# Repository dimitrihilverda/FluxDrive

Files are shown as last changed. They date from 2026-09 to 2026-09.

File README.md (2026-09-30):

# FluxDrive

An Amiga floppy drive emulator built around one ESP32-S3: no Gotek, no second microcontroller. It plugs into the
A500's internal floppy connector, holds a disk image in PSRAM and generates the MFM flux stream itself. Disk
images come from the [GTi](https://github.com/mesarim/Gotek-Touchscreen-interface) touchscreen over ESP-NOW, or
from a phone over WiFi. The design starts from Mez's OMEGAWARE FluxDrive hardware design document (see
[Credits](#credits)).

Status: v1 hardware (rev A) designed and reviewed: schematic, 4-layer layout (DRC clean) and JLCPCB production
files. It can be ordered once the checks under [Before ordering](#before-ordering) pass. Not built yet; the
firmware is a separate project.

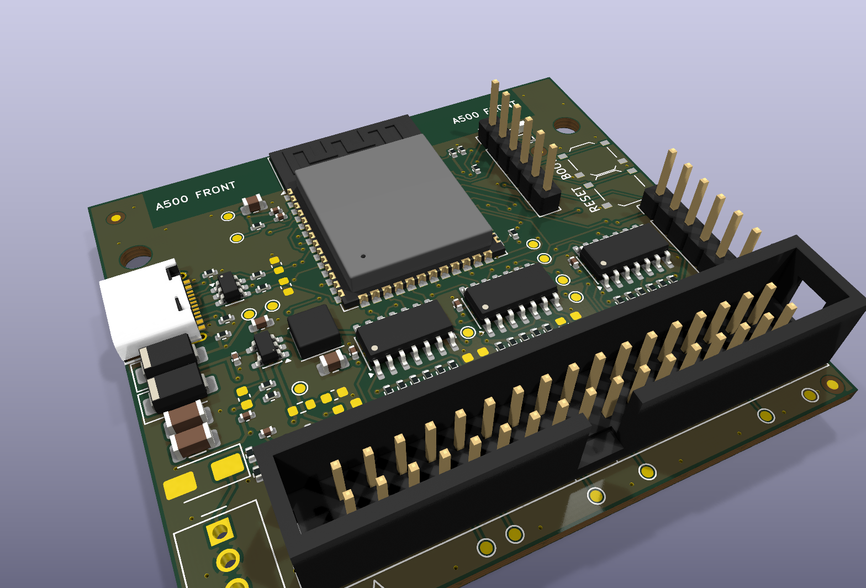
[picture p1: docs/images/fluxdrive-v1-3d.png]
FluxDrive v1, top


| Where | What |
|---|---|
| `docs/superpowers/specs/` | design specs (start with the v1 hardware design) |
| `docs/input/` | the documents this design builds on: Mez's OMEGAWARE FluxDrive HW design v0.1, breadboard measurements |
| `docs/reviews/` | specialist reviews of the spec, schematic and layout, with what was done about each finding |
| `FluxDrive_Schematic.pdf` | the schematic (generated from `hardware/design.py` by `tools/sch_gen.py`) |
| `FluxDrive.kicad_pcb` | the board (built by `tools/pcb_build.sh`; KiCad 10) |
| `jlcpcb/production_files/` | gerbers and drill files (zip), BOM and CPL for JLCPCB (`tools/jlc_production.sh`) |
| `mech/` | 1:1 fit template (PDF) and a STEP model for a printed dummy (`tools/fit_template.sh`) |
| `docs/images/` | renders of the board, top and bottom |

Related: the breadboard prototype and its firmware live in
[dimitrihilverda/amiga-floppy-emulator](https://github.com/dimitrihilverda/amiga-floppy-emulator).

## Building one

The board is 60 × 54.5 mm, 4 layers. JLCPCB places every SMD part on the top side except the ESP32 module; the
module and the connectors are soldered by hand.

### Before ordering

- **Range test:** check the radio with a WROOM-1 dev board inside the closed A500 (spec §11.5). If the range is
  poor, rev A is not the board to order (the WROOM-1U with an external antenna is the fallback).
- **J1:** check the drawing of the box header C601943: its body must not be longer than 52 mm, or it overhangs
  the east edge (the footprint is 50.84 mm, DIN 41651).
- **J2:** check the outline of the TE 171825-4 (C210162) against its footprint (spec O15).
- **Fit:** print `mech/fit_template.pdf` at 100 % (both scale bars must measure 50 mm and 40 mm) and lay it on
  CN11 in the A500: pin 1 over pin 1, the "A500 FRONT" edge towards the front of the computer. Check that the
  drive's power cable from CN12 reaches J2 (about 6 cm) and that the room under the shield takes the tallest part
  (`mech/FluxDrive.step` has the heights; the USB-C, the buttons and the eFuse are missing from it, none taller
  than 3.3 mm). On Dimitri's A500 both are fine. The rectangle that reaches 14.5 mm past the north edge on the
  template is the module's antenna keep-out, not board.

### Order settings (JLCPCB)

Upload `jlcpcb/production_files/GERBER-FluxDrive.zip`:

| Setting | Value |
|---|---|
| Layers | 4 (the default stackup; no impedance control needed: USB is full speed only) |
| Size | 60 × 54.5 mm, single board (no panel) |
| Thickness | 1.6 mm |
| Surface finish | lead-free HASL or ENIG |
| Via covering | tented |
| Mark on PCB | order number at a specified position (the `JLCJLCJLCJLC` text on the bottom) |
| PCB assembly | yes: Economic (Standard if the form does not offer it for 4 layers), top side, 2 or 5 boards |

Then upload `BOM-FluxDrive.csv` and `CPL-FluxDrive.csv`. They hold the 86 SMD parts that JLC places. Left out
(`tools/jlc_export.py` lists them): the ESP32 module U1, which you place yourself (`tools/assembly.py`; its pads get
no solder paste, see below), the unfitted pads, the test pads, the fiducials and every through-hole part.

### Check in JLC's placement preview

Before paying, look at every part below in JLC's preview; fix a wrong rotation there.

- **U2, U3, U4** (74LVC14A, 74LVC07A, SOIC-14): pin 1 at the south-west corner of each. The CPL gives SOIC the same
  correction as the TSSOP that JLC placed on the Nano-Tek; the JLCPCB Tools default would be 270°.
- **U1** (ESP32-S3-WROOM-1) is not placed by JLC: the preview shows its pads empty, and they come without paste.
- **U5** (TPS259531, WSON-8 with exposed pad), **U6** (TLV62569, SOT-23-5), **U7** (USBLC6-2SC6, SOT-23-6):
  pin 1 dot.
- **D1, D2** (SS34): cathode band to the west. **D3** (LED): cathode to the west.
- **J3** (USB-C): the opening flush with the west edge (the shell reaches 0.18 mm past it).
- **SW1, SW2**: the four pads on the pads.

### Soldering by hand

| Ref | Part | LCSC | Notes |
|---|---|---|---|
| U1 | ESP32-S3-WROOM-1-N16R8 module (exactly this variant) | C2913202 | SMD: antenna to the north edge, pin 1 at the north-west. The pads come bare (no paste from JLC, so the module sits flat). Solder the large ground pad underneath (pin 41) too, for ground and heat: flux or paste on the pads, then hot air or a hot plate. An iron alone reaches only the edge pads. Solder it before the connectors, while the board still lies flat |
| J1 | 2×17 box header, 2.54 mm, vertical | C601943 | or, to plug the board straight onto CN11, a 2×17 female socket on the bottom side (see the note on the silkscreen); pin 1 is the square pad |
| J2 | TE 171825-4 floppy power header, vertical | C210162 | polarised; pin 1 = +5 V at the north end |
| J4 | 1×6 pin header, 2.54 mm | — | optional: UART recovery (TX, RX, EN, IO0, 3V3, GND from the ESP32's side) |
| J5 | 1×6 pin header, 2.54 mm | — | optional: spare GPIO13, 14, 47, 48, 3V3, GND |

- **J3's shell legs:** the four through-hole legs of the USB-C receptacle get no solder paste. Check them on
  delivery; if they are bare, solder them from the bottom side (they carry the plugging force, not the SMD pins).
- **After soldering J1:** `/CHNG_D` runs 0.25–0.30 mm past the row of J1's ground pins, on both sides. With the
  board unpowered, beep between U4 pin 10 (`/CHNG_D`) and J1 pin 1 (GND): a steady beep means a solder bridge or
  a scratched mask there, and the Amiga would see a disk change all the time.

The unfitted pads (0603 unless noted), only if bring-up asks for them: C1–C4 220 pF input filters on STEP, SEL0,
SEL1 and MTR0; R16 and R25 1 kΩ pull-ups for the two /MTR0 pins; C16 15 pF buck feed-forward; C21/C22 10 pF on
USB D+/D−; R49 1 Ω + C15 4.7 µF damper on V5SYS (then change C13 from 10 µF to 4.7 µF); D4 SMAJ13A TVS (SMA) on
the power input.

### Power: read this first

- The board takes its power from the A500's drive power connector CN12, through the drive's power cable on J2.
  **Never plug or unplug it with the A500 switched on.** A mini-Berg plug forced on the wrong way round puts
  +12 V on the 5 V pin: the eFuse survives that only when the plug goes on with the power off.
- +12 V (J2 pin 4) is not connected on the board.
- The 34-pin cable without the power cable is not supported: the bus pull-ups then hang on a dead rail.
- USB-C and the A500 may power the board at the same time; neither can feed the other.

### Flashing

Over USB-C: the ESP32-S3's USB-Serial/JTAG enters download mode by itself (`idf.py flash`, `esptool.py`). If the
firmware has taken GPIO19/20 or put the chip to sleep: hold BOOT, press and release RESET, release BOOT, and flash
again. If USB does not work at all, J4 takes a 3.3 V USB-serial adapter (its RX to J4 TX, its TX to J4 RX, GND;
IO0 to GND and a pulse on EN for download mode).

### Test pads

1.0 mm pads on the top side, for a probe. x from the west edge, y from the north (antenna) edge, in mm.

| Pad | Net | x | y | | Pad | Net | x | y |
|---|---|---|---|---|---|---|---|---|
| TP1 | /DKRD (connector) | 50.5 | 53.1 | | TP9 | /MTR0 (connector) | 32.7 | 53.1 |
| TP2 | DKRD_N (ESP32) | 42.6 | 31.8 | | TP10 | MTR0 (ESP32) | 30.8 | 33.7 |
| TP3 | /INDEX (connector) | 22.6 | 53.1 | | TP11 | +5V_A | 14.0 | 32.9 |
| TP4 | INDEX_N (ESP32) | 42.4 | 28.4 | | TP12 | V5SYS | 14.6 | 22.5 |
| TP5 | /SEL0 (connector) | 25.1 | 53.1 | | TP13 | VBUS | 12.2 | 22.6 |
| TP6 | SEL0 (ESP32) | 42.6 | 34.3 | | TP14 | +3V3 | 13.9 | 8.1 |
| TP7 | /STEP (connector) | 37.8 | 53.1 | | TP15 | ESP_EN | 13.9 | 11.8 |
| TP8 | STEP (ESP32) | 42.4 | 26.1 | | TP16 | GND | 55.6 | 53.1 |

The connector-side pads sit in the strip south of J1, each between two ground pins.

### Rebuilding the files

KiCad 10, Python 3 with pytest, Java 17 and Freerouting 1.9 (`~/.kicad-mcp/freerouting.jar`):

```bash
bash tools/export_netlist.sh && python -m pytest -q    # schematic and its tests
bash tools/pcb_build.sh                                # the board: placement, routing, DRC (15-60 min)
bash tools/jlc_production.sh                           # gerbers, BOM and CPL
```

## Credits

- **Mez** ([mesarim](https://github.com/mesarim)): the *OMEGAWARE FluxDrive Hardware Design Document, Rev 0.1*
  ([`docs/input/OMEGAWARE_FluxDrive_HW_Design_v0.1.md`](docs/input/OMEGAWARE_FluxDrive_HW_Design_v0.1.md)), the input
  this design is built on: one ESP32-S3 on the Shugart bus that generates the MFM flux itself and gets its disk
  images from the GTi over ESP-NOW, the bus interface, the bench gate and the bring-up order. The v1 spec says where
  it follows that document and where it departs from it.
- **Dimmy (Dimitri Hilverda)**: the v1 hardware, from the spec to the board and the production files.
- Disk images come from the [GTi](https://github.com/mesarim/Gotek-Touchscreen-interface) touchscreen.

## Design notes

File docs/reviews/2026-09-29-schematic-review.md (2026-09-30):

# Review of the v1 schematic (commit f2901b3)

Four specialist reviews of the generated schematic (`FluxDrive.kicad_sch`, from `hardware/design.py`), its netlist
and its tests, done by separate agents on 2026-09-29. None of them changed a file. This document lists every
finding, what was decided and where it went. The spec went to v0.3 for this review only.

| Review | Findings | Blockers |
|---|---|---|
| Amiga floppy bus (SBUS) | 4: 2 minor, 2 nits | — |
| Power and EMC (SPWR) | 5: 1 major, 3 minor, 1 nit | — |
| ESP32-S3 hardware (SESP) | 3: 1 minor, 2 nits | — |
| PCB and manufacturing at JLC (SPCB) and the generator and tests (SCODE) | 15: 1 major, 7 minor, 7 nits | — |

Reference designators below are those of the fixed schematic; the reviews quoted the numbers of f2901b3, which
shifted when parts were added.

## Sources the reviews used

- **[TPS]** TI TPS2595x datasheet SLVSE57C (eFuse: pinout, clamp, current limit, dVdt, equation 18 and the TVS note).
- **[TLV]** TI TLV62569 datasheet SLVSDG1C (absolute maximum, input capacitor, feed-forward, table 4).
- **[NXP]** Nexperia 74LVC14A datasheet (VT+ max 2.0 V and VT− min 0.8 V at VCC 3.0–3.6 V).
- **[D]**, **[W]**, **[HDG]** ESP32-S3 datasheet v2.2 (table 2-2), WROOM-1 datasheet, hardware design guidelines, as
  in the spec review.
- **[JLC]** jlcsearch mirror of JLC's parts database: stock, basic/extended, descriptions.
- The netlist (`build/FluxDrive.net`), a pin-by-pin cross-check of netlist against design file (0 mismatches), and
  ERC at every severity (0 errors, 14 `footprint_filter` warnings).

## Where the reviews disagreed

| Topic | Positions | Decision |
|---|---|---|
| AMIGA_PWR on USB alone | SPWR-4: no hardware change, the firmware reads GPIO1 with the ADC. SESP-1: make the divider ten times stiffer. | Both. The divider is 1 kΩ / 1.5 kΩ, so the pin reads low in hardware (about 0.29 V), and spec §9 names the ADC reading as the firmware's second guard against the Schottky's leakage when hot. |
| Which TE part is vertical | SPCB-1 recalled 171825-x as the right-angle one. | The JLC listing of 171826-4 says right angle, the copied footprint's own description says "Horizontal" and its outline runs 11 mm to one side of the pins. 171825-4 (C210162, 5,365 in stock) is the vertical one. |

## Findings and decisions

"Accepted" means the design or spec now does what the finding asks. A test named in the Decision column failed
before the fix and passes after it; a test marked "coverage" pins behaviour that was already right, and was checked
by breaking the design on purpose (it failed).

### Amiga floppy bus

| ID | Sev. | Finding | Decision | Where |
|---|---|---|---|---|
| SBUS-1 | minor | With the firmware halted or unflashed, the 10 kΩ pull-ups release all six outputs: `/CHNG` high reads as a disk in, so DF0 looks like a drive holding an unreadable disk, not an empty one. | Accepted as a spec correction. No pull-down on `CHNG_N`: it would assert `/CHNG` while deselected and break "release = input". Bring-up checks that the Amiga still reaches the insert-disk screen or boots its next device. | spec 11 |
| SBUS-2 | minor | The tests did not check gate pairing, output direction or the spare gate input. | Accepted: `test_gate_pairs` (coverage) checks 1→2, 3→4, 5→6, 9→8, 11→10, 13→12 on U2/U3/U4 and U3 pin 13 on GND. | tests |
| SBUS-3 | nit | GPIO15/16 carry `/SIDE` and `/DKWE` and are also the 32 kHz crystal pins. | Accepted: spec §9 keeps the RTC slow clock internal. | spec 9 |
| SBUS-4 | nit | UART TX resistor 470 Ω in the design, 499 Ω in the spec. | Accepted: 470 Ω (basic part) in both. | spec 7 |

### Power and EMC

| ID | Sev. | Finding | Decision | Where |
|---|---|---|---|---|
| SPWR-1 | major | U7 (USBLC6) pin 5 on VBUS: from boot the ESP32's D+ pull-up lifts VBUS to about 2.7 V through the ESD diodes, plus D2's leakage. A USB-C host on a C-to-C cable then may never switch VBUS on, so the console fails while the Amiga powers the board. | Accepted: U7 pin 5 on +3V3, and R58 10 kΩ from VBUS to GND. `test_usb`. | design E, spec 5, 7 |
| SPWR-2 | minor | A USB hot-plug into the 10 µF through D2 can overshoot to 6–7.5 V, and D2 holds the peak; the TLV62569's absolute maximum is 6 V. | Accepted: unfitted damper R49 1 Ω + C15 4.7 µF on V5SYS (if fitted, C13 becomes 4.7 µF so the USB limit holds), and a bring-up hot-plug test with 1 m and 2 m cables. `test_protection_pads`. | design C, spec 5, 11 |
| SPWR-3 | minor | A reversed plug pushed on while the PSU runs can ring to 22–24 V on the eFuse input (20 V abs. max) and 7.7 V on EN/UVLO. | Accepted: unfitted D4 SMAJ13A (13 V standoff) on +5V_IN; spec says "fitted with the power off". `test_protection_pads`. | design C, spec 5 |
| SPWR-4 | minor | On USB alone +3V3 feeds +5V_A through the pull-ups: AMIGA_PWR at 1.25 V (undefined for the ESP32), bus inputs at 2.1–2.2 V (just above the LVC14A's VT+ max). | Accepted, see the disagreement above: AMIGA_PWR 0.29 V, bus inputs 0.51–0.74 V or 3.3 V. `test_usb_alone_leaves_everything_defined` solves the resistor network (it gave 1.24 V before the fix, as the review computed). | design C, spec 4.2, 5, 9 |
| SPWR-5 | nit | The 6.8 pF feed-forward value was for the datasheet's 200k/100k divider; ours needs about 13–15 pF. | Accepted: the unfitted pad C16 says 15 pF; the value is chosen at bring-up. `test_buck`. | design C, spec 5 |

### ESP32-S3 hardware

| ID | Sev. | Finding | Decision | Where |
|---|---|---|---|---|
| SESP-1 | minor | Same as SPWR-4: AMIGA_PWR is not reliably low on USB alone. | Accepted: R52 1 kΩ / R53 1.5 kΩ (C25867, basic), 3.0 V at 5 V, 3.5 V at the clamp, 2 mA. | design C, spec 5 |
| SESP-2 | nit | Same as SBUS-4. | Accepted. | spec 7 |
| SESP-3 | nit | Burning `EFUSE_DIS_USB_JTAG` without `EFUSE_DIS_PAD_JTAG` moves JTAG onto GPIO39–42 (bus outputs). | Accepted: rule added to spec §9. | spec 9 |

### PCB and manufacturing at JLC

| ID | Sev. | Finding | Decision | Where |
|---|---|---|---|---|
| SPCB-1 | minor | J2 171826-4 (C590635) has 16 in stock at LCSC and is right-angle; spec §8 wants a vertical header. | Accepted: TE 171825-4, vertical, C210162. New footprint `FluxDrive:171825-4` with the same pads (2.5 mm pitch, 1.2 mm drill, 1.8 mm pad); its outline is an estimate, open item O15. The right-angle footprint and its 3D model are removed. Spec §5 names a distributor for larger runs. | design C, library, spec 5, 10, 13 |
| SPCB-2 | minor | The 100 µF on +5V_A (C15008) is 6.3 V: the 5.7 V clamp is 90 % of its rating, and at 5 V it keeps only 20–30 µF. | Accepted: 2 × 47 µF 10 V X5R 1206 (C96123, CL31A476MPHNNNE, basic). `test_bulk_capacitors_rated_above_the_clamp`. | design C, spec 5, 10 |
| SPCB-3 | minor | The unfitted pads a builder might fill by hand were 0402. | Accepted: every unfitted R and C is 0603. `test_unfitted_pads_are_hand_solderable`. | design, spec 8 |
| SPCB-4 | nit | The eFuse is single-source with about 2,000 in stock, and its WSON cannot be reworked by hand. | Accepted: reserve stock at order time, spec §10. | spec 10 |
| SPCB-5 | nit | The library symbols' default footprints still pointed to `Nano-Tek:`. | Accepted: `FluxDrive:`. `test_project_symbols_load`. | library |
| SPCB-6 | nit | Same as SBUS-4. | Accepted. | spec 7 |
| SPCB-7 | nit | Every part was marked for the position file, also unfitted parts, holes and fiducials. | Accepted: `in_pos_files` = in BOM and fitted. `test_unplaced_parts_stay_out_of_the_position_file`. | generator |
| SPCB-8 | nit | The 14 `footprint_filter` warnings come from the 74HC14 symbol (its filter lists DIP only). The 1.0 mm test pads suit a probe, not a pogo-pin fixture. | Warnings noted and allowed by the ERC test. Test-pad size deferred to the layout (task 10), where the free space is known. | — |

### Generator and tests

| ID | Sev. | Finding | Decision | Where |
|---|---|---|---|---|
| SCODE-1 | major | The netlist tests read `build/FluxDrive.net` (git-ignored) and only checked that it existed: after a design edit without a re-export, about 40 tests passed on the old circuit. | Accepted: the session fixture generates the schematic, fails if it differs from the committed `FluxDrive.kicad_sch`, and exports a fresh netlist into a temporary directory. Checked: a design edit without a re-export now fails the netlist tests with "out of date". | tests/conftest.py |
| SCODE-2 | minor | ERC only ran on the tiny design, at error severity; stacked pins with different nets would merge two nets without an ERC error. | Accepted: `test_real_schematic_erc` (coverage) runs every severity on the real schematic and allows only `footprint_filter`; the generator raises on stacked pins with different nets (`test_stacked_pins_on_different_nets_are_an_error`). | tests, generator |
| SCODE-3 | minor | A pin named by number and by name silently took the last net. | Accepted: the generator raises. `test_pin_assigned_twice_is_an_error`. | generator |
| SCODE-4 | minor | Common pins of multi-unit symbols got duplicate IDs (not triggered by this design). | Accepted: the unit is part of the pin, label and no-connect IDs. `test_common_pins_of_multi_unit_symbols_get_unique_ids`, with a two-unit test symbol. | generator |
| SCODE-5 | minor | Nothing checked that the unfitted pads exist. | Accepted: `test_unfitted_pads_exist` (coverage) for the /MTR0 pull-ups and the 220 pF pads; `test_usb` for the 10 pF pads; `test_buck` for the feed-forward pad. | tests |
| SCODE-6 | nit | The tiny test design covers little (two rotations, no unfitted part, no pin by name, no `unconnected-` check; a hard-coded `parts[1]`). | Deferred: the real design, now tested fresh at every run, exercises all of these. | — |
| SCODE-7 | nit | `netlist.py` does not unescape `\\`; `p["_numbers"]` is unused; `lib_symbol` drops parent properties the child lacks; A0 paper is awkward to print. | Deferred: none changes the netlist of this design. | — |

## What the reviews could not verify

- The TE 171825-4 body outline and where the pin row sits in it (spec O15, before the layout is frozen).
- The USB hot-plug overshoot on V5SYS with real cables (bring-up, spec §11).
- The Schottky's reverse leakage into +5V_A when hot, which lifts AMIGA_PWR above 0.29 V (the firmware's ADC reading
  covers it, spec §9).
- How each Kickstart version treats a DF0 whose outputs are all released (bring-up, spec §11, O13).
- The schematic PDF (the reviewers had no PDF renderer; the netlist was reviewed instead).

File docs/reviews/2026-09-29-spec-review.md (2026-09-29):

# Review of the v1 hardware spec (draft of 2026-09-28)

Four specialist reviews of `docs/superpowers/specs/2026-09-28-fluxdrive-v1-hardware-design.md`, done by separate
agents on 2026-09-28/29. None of them changed a file. This document lists every finding, what was decided and where
it went in the spec (v0.2).

| Review | Findings | Blockers |
|---|---|---|
| Amiga floppy bus (BUS) | 12: 7 major, 3 minor, 2 nits | — |
| Power and EMC (PWR, SI) | 12: 1 blocker, 5 major, 5 minor, 1 nit | PWR-1 |
| ESP32-S3 hardware (ESP) | 11: 1 blocker, 3 major, 6 minor, 1 nit | ESP-1 |
| PCB and manufacturing at JLC (PCB) | 14: 4 major, 8 minor, 2 nits | — |

## Sources the reviews used

- **[SCH]** A500 schematic Rev 6a/7, https://amigawiki.org/dnl/schematics/A500_R6.pdf (sheet numbers from the title blocks)
- **[HRM]** Amiga Hardware Reference Manual, appendix E, https://www.theflatnet.de/pub/cbm/amiga/AmigaDevDocs/hard_e.html
- **[GARY]** Gary chip specification, https://www.devili.iki.fi/mirrors/haynie/systems/amiga2k/docs/gary.txt
- **[8520]** CIA 8520 specification, https://rastport.com/techblog/8520-complex-interface-adapter-specification/
- **[FF]** FlashFloppy source (`src/floppy.c`, `src/gotek/floppy.c`) and wiki page Host-Platforms, https://github.com/keirf/flashfloppy
- **[D]** ESP32-S3 datasheet v2.2, https://documentation.espressif.com/esp32-s3_datasheet_en.pdf
- **[W]** ESP32-S3-WROOM-1/1U datasheet v1.8, https://documentation.espressif.com/esp32-s3-wroom-1_wroom-1u_datasheet_en.pdf
- **[HDG]** ESP32-S3 hardware design guidelines, https://docs.espressif.com/projects/esp-hardware-design-guidelines/en/latest/esp32s3/
- **[RMT]** ESP-IDF RMT documentation and `esp_driver_rmt` source; ESP-IDF pages on USB-Serial/JTAG, SPI flash concurrency, I2S, `esp_wifi.h`
- **[TI]** SN74LS38 (SDLS105), SN74LS05, TPS562201, TLV62569, LM66100 datasheets, https://www.ti.com
- **[NXP]** Nexperia 74LVC14A (Rev 11) and 74LVC07A (Rev 10) datasheets
- **[AN88]** Linear Technology AN88, ceramic input capacitors and hot-plugging
- **[JLC]** JLCPCB assembly price, assembly capabilities, assembly FAQ and PCB capabilities pages; part data from the
  jlcsearch mirror of JLC's database (https://jlcsearch.tscircuit.com). Stock and prices from the mirror are to be
  re-checked in JLC's BOM tool at order time.

The ESP-1 claim was re-checked against [D] directly: table 2-2 lists GPIO1–14, XTAL_32K_P/N (GPIO15/16) and GPIO17
with a 60 µs low-level glitch at power-up, GPIO18 low and high, GPIO19/20 high. Footnote 1 defines a low-level glitch
as "the pin is at a low level output status".

## Where the reviews disagreed

| Topic | Positions | Decision |
|---|---|---|
| Bulk capacitor | PWR-4: aluminium electrolytic, a ceramic overshoots on hot-plug. PCB-14: 100 µF 1206 MLCC (basic part). | Ceramic, but only on `+5V_A` behind the eFuse. Its soft-start separates the capacitor from the cable, which is what AN88 is about. The `V5SYS` node stays at 10 µF (USB limit). |
| Power header | PCB-4: a generic 1×4 header (the 171826-4 has 16 in stock at JLC). PWR-3: the polarised 171826-4 is mandatory. | Polarised 171826-4. Dimitri solders all through-hole parts himself, so JLC stock does not matter. |
| Test pads | PCB-12: 1.5 mm pads on the bottom for a pogo jig. PCB-3: no exposed copper on the bottom, the plug-on board may rest on motherboard parts. | Test pads on the top side. |
| Buck converter | PCB-6: keep the TPS562201. PWR-5: its 4.5 V minimum input does not fit a diode-fed rail. | TLV62569 (PWR-5). |
| Output buffer | PCB-7: six 2N7002 would save one extended-part fee. | Keep the 74LVC07A: no inversion, fewer parts, the saving only counts at 5–10 boards. |

## Findings and decisions

"Accepted" means the spec now does what the finding asks; the column "Spec" gives the section of v0.2.

### Amiga floppy bus

| ID | Sev. | Finding | Decision | Spec |
|---|---|---|---|---|
| BUS-1 | major | `/MTR0` on pins 4/16 is latched by Gary (MTRON, U5 pin 46, via U36 74LS38 [SCH] sheet 4; [GARY] §2.1, §3.4.17). The breadboard symptom came from the HCT125 at 3.3 V. Sampling on the `/SEL0` edge would need ≥ 100 ns delay. | Accepted. O1 closed: firmware reads `/MTR0` as a level with a short glitch filter. A hardware latch is noted for a later external DF1. | 2.1, 9, 13 |
| BUS-2 | major | `/MTR0` already has R506 10 kΩ and the drive-LED transistor Q503 on the motherboard ([SCH] sheet 6). 2 × 1 kΩ on pins 4 and 16 (one net) is about 10.5 mA, over the A500+'s 74LS05 rating of 8 mA. | Accepted: no pull-up on pins 4 and 16, footprint left unfitted. | 4.1, 4.2 |
| BUS-3 | major | With the pull-up on the buffer side of the 100 Ω, the LVC14A sees up to 0.92 V for a low; its VT− can be 0.8 V ([NXP] 74LVC14A p.8). | Accepted: pull-up on the connector side, 100 Ω between that node and the buffer. A netlist test checks it. | 4.2, 11 |
| BUS-4 | major | Power domains: with FluxDrive unpowered the 1 kΩ pull-ups load the bus from a dead rail; on USB alone they feed about 1 mA per line into a dead Amiga; the P-FET conducts backwards. | Accepted: pull-ups on `+5V_A` (Amiga side of the power OR), 100 kΩ to 3.3 V on the buffer side, an `AMIGA_PWR` sense input, P-FET replaced (PWR-1). A ribbon without the power cable is declared unsupported. | 4.2, 5, 11 |
| BUS-5 | major | A mini-Berg forced on the wrong way round puts +12 V on pin 1 (CN12: 1 = +5 V, 4 = +12 V, [SCH] sheet 8), not a negative voltage. | Accepted, handled by the eFuse (PWR-3). | 5 |
| BUS-6 | major | An empty drive is not an absent drive: `/CHNG` stays set while no disk is in, `/TRK0` works without a disk ([HRM] appendix E, [FF]). "All outputs released until mounted" looks like "disk present, unchanged". | Accepted: outputs are gated by `/SEL0` only; empty state defined. | 9 |
| BUS-7 | major (DF1–3), minor (DF0) | `/RDY` with the motor off is the drive ID; a DD drive holds it low while selected ([HRM]). FlashFloppy does `pin 34 = !motor` in Amiga mode. | Accepted: the rule is used on DF0 as well; spin-up 500 ms. "Kickstart never probes DF0" softened. | 2.1, 9 |
| BUS-8 | minor | `/INDEX` goes to CIA-B /FLAG ([SCH] sheet 6); a real drive pulses once per revolution. | Accepted: 200 ms period, 2 ms low, only with motor on, disk mounted and selected. | 9 |
| BUS-9 | minor | Firmware release on deselect is too slow for two drives on one bus; real drives gate outputs in logic. | Deferred: fine for v1 (DF0 only). Hardware gating is an item for external-DF1 support. | 13 |
| BUS-10 | minor | `/DKWD` and `/DKWE` have no host pull-up and are shared with the external port; 1 kΩ + a DF1's 1 kΩ is 10 mA, over the 74LS05's 8 mA. | Accepted: 4.7 kΩ on `/DKWD` and `/DKWE`, 1 kΩ on `/STEP`, `/DIR`, `/SIDE`, `/SEL0`, 10 kΩ on `/SEL1`. The 0.7 µs rise on `/DKWD` is checked against Paula's write pulse before v2. | 4.2, 13 |
| BUS-11 | nit | Rise times are fine; the DB23 port adds 100 pF filters to the shared nets ([SCH] sheet 7). | No parts added. The `/DKRD` pulse width is fixed in the firmware spec after measuring a real drive. | 9, 13 |
| BUS-12 | nit | Cite [HRM] appendix E for the 1 kΩ termination, not the TEAC drive. | Accepted. | 2.1 |

### Power and EMC

| ID | Sev. | Finding | Decision | Spec |
|---|---|---|---|---|
| PWR-1 | blocker | A P-FET wired for reverse polarity conducts both ways once on: on USB alone it back-feeds the A500's whole 5 V rail. The spec's claim that the Schottky prevents back-feeding is wrong. | Accepted: CN12 → eFuse → `+5V_A` → Schottky → `V5SYS`; VBUS → USBLC6-2SC6 → Schottky → `V5SYS`. No P-FET. | 3, 5 |
| PWR-2 | major | Same as BUS-4 from the power side. | Accepted, see BUS-4. | 4.2, 5 |
| PWR-3 | major | Reversed plug = +12 V on the 5 V pin; it reaches the LVC14A inputs (abs. max 6.5 V) and the Amiga's pins through the pull-ups. A plug shifted by one pin shorts the PSU. | Accepted: eFuse with over-voltage clamp at 5.7 V (TPS259531, to be verified in the plan against its datasheet), and the polarised 171826-4 header is mandatory. | 5, 7 |
| PWR-4 | major | Ceramic bulk + hot-plug overshoot ([AN88]); inrush on the running A500; USB allows 10 µF on VBUS. | Accepted with a change: see "Where the reviews disagreed". | 5 |
| PWR-5 | major | TPS562201 needs 4.5 V in and ~4.4 V for 3.3 V out; USB minus a Schottky is ~4.35 V. | Accepted: TLV62569 (2.5–5.5 V, 100 % duty). Its 6 V abs. max is covered by the eFuse clamp. | 5 |
| PWR-6 | minor | No usable buck on JLC's basic list. | Accepted: one extended part. | 5, 10 |
| PWR-7 | major | The WROOM-1-N16R8 is rated −40…65 °C; with PSRAM ECC 85 °C ([W] §1). | Accepted: PSRAM ECC on (7.5 MB left, 2.8 MB used), one-hour lid-closed temperature test. | 6, 9, 11 |
| SI-1 | minor | Released `/DKRD` is a high-impedance node that picks up switch-node edges. | Accepted: connector at one end, buck at the other (≥ 15 mm), unbroken ground under the signals, stitching. | 8 |
| SI-2 | minor | LVC07A edges into an unterminated ribbon ring. | Accepted: 33 Ω in series on every output. | 4.3 |
| SI-3 | minor | The 100 Ω does not damp ringing; the hysteresis does. | Accepted: wording fixed; optional (unfitted) 100–220 pF pads after the 100 Ω on `/STEP`, `/SEL0`, `/SEL1`, `/MTR0`. | 4.2 |
| PWR-8 | minor | USB protection. | Accepted: USBLC6-2SC6 at the connector, before the VBUS diode. | 7 |
| PWR-9 | nit | Test points for the rails. | Accepted: `+5V_A`, `V5SYS`, VBUS, 3V3, EN. | 7 |

### ESP32-S3 hardware

| ID | Sev. | Finding | Decision | Spec |
|---|---|---|---|---|
| ESP-1 | blocker | All six output GPIOs (4, 8–12) are driven low for ~60 µs at power-up ([D] table 2-2), which overrides the 10 kΩ pull-ups and asserts every bus output, also on a RESET press while the Amiga runs. | Accepted: outputs moved to GPIO21 and 38–42, which have no glitch and are not strapping pins. O3 closed. | 4.1, 6 |
| ESP-2 | minor | GPIO18 also has a high-level glitch: output contention with the LVC14A. | Accepted: GPIO18 unused. | 4.1 |
| ESP-3 | major | RMT and GPIO drivers start pins low by default (`init_level`, `eot_level` = 0); I2S `auto_clear` sends zeros. | Accepted: release = pin to input, never a peripheral idle level; idle and end levels 1; release first in `app_main` and in a panic hook. | 9 |
| ESP-4 | minor | GPIO0 needs an external pull-up and no capacitor ([HDG]). | Accepted: 10 kΩ, no debounce capacitor; the 15 s wipe only with no disk mounted. | 6, 9 |
| ESP-5 | minor | No series parts on D+/D−; CC and pair wiring. | Accepted: 22 Ω series pads (0 Ω allowed), unfitted capacitor pads, separate 5.1 kΩ on CC1/CC2, A6–B6 and A7–B7 tied, 90 Ω pair. | 7, 8 |
| ESP-6 | minor | UART header pins not defined; a closed A500 hides USB and buttons. | Accepted: 6-pin header with UART0 (GPIO43/44, 499 Ω on TX), EN, IO0, 3.3 V, GND. A wired GTi link uses UART1 on spare pins. Wi-Fi OTA with rollback is the normal update path, only with no disk mounted. | 7, 9 |
| ESP-7 | minor | Temperature rating of the R8 modules. | Accepted with PWR-7; thermal pad to ground with vias. | 6, 8 |
| ESP-8 | major | Antenna: Espressif prefers the antenna outside the board, 15 mm clearance from metal ([HDG]); the SuperMini range test does not transfer. | Accepted: antenna past the board edge, 15 mm rule, range test with a real WROOM-1 board in both connector variants. | 6, 11 |
| ESP-9 | major | Flux ISR vs flash writes: an ISR that is safe with the cache off must still not touch PSRAM during a flash write; Wi-Fi stores its config in flash by default. | Accepted: Wi-Fi storage in RAM, the current track copied to internal RAM on each step, endless RMT transmission, channel created on core 1. | 9 |
| ESP-10 | minor | GPIO39–42 are JTAG pins; they stay GPIO with default eFuses. | Accepted: eFuse rules for v1. | 9 |
| ESP-11 | nit | GPIO47/48 run from VDD_SPI: 3.3 V on N16R8, 1.8 V on R16V. | Accepted: the module variant is fixed exactly in the BOM. | 6 |

### PCB and manufacturing at JLC

| ID | Sev. | Finding | Decision | Spec |
|---|---|---|---|---|
| PCB-1 | major | A 34-way boxed header body is about 51–54 mm long; 50 mm is too short. | Accepted: at least 56 mm along the connector; 54 × 10 mm on top kept free of SMD parts. | 8 |
| PCB-2 | minor | The pin-header hole pattern is right; the overhang direction and a mechanical key are missing. | Accepted: pin-1 triangle and edge marks on both sides, even row towards the board, key or foot; direction from the fit test. | 4.4, 8, 13 |
| PCB-3 | major | The plug-on board hangs on 34 contacts; cables lever it. | Accepted: power header next to the 34-way connector, vertical; two 3.2 mm non-plated holes at the far end for a foot; bottom vias tented, no exposed copper on the bottom. | 8 |
| PCB-4 | minor | Who solders the through-hole parts; stock of the 171826-4. | Accepted: Dimitri solders all through-hole parts; the header stays the polarised 171826-4 (PWR-3). | 7, 8 |
| PCB-5 | major | Economic assembly: 30 or 50 pieces (JLC's pages disagree); standard assembly needs 70 × 70 mm with rails. | Accepted: the board is laid out so a 2-up JLC panel is possible; decided at order time. | 8 |
| PCB-6 | minor | No basic buck; TPS562201 values. | Superseded by PWR-5. | 5 |
| PCB-7 | minor | Seven extended parts, about $21.5 per order. | Accepted as a cost; the 2N7002 option rejected. | 10 |
| PCB-8 | minor | Use SOIC-14 for the logic, reserve LVC07 stock. | Accepted. | 4, 10 |
| PCB-9 | minor | Module stock and price; windowpane paste on the ground pad. | Accepted. | 6, 8, 10 |
| PCB-10 | major | Antenna placement on a 45 mm board. | Accepted with ESP-8; whether economic assembly takes an overhanging module is asked at JLC (O10). | 6, 13 |
| PCB-11 | minor | Design rules. | Accepted. | 8 |
| PCB-12 | minor | Fiducials, test pads, serial box, order-number position. | Accepted; test pads on top (PCB-3). | 7, 8 |
| PCB-13 | nit | UART and spare headers: unpopulated holes. | Accepted. | 7 |
| PCB-14 | nit | 100 µF as 1206 MLCC. | Accepted, see "Where the reviews disagreed". | 5 |

## What the reviews could not verify

Carried into the spec's open items (§13) where they affect the design:

- Termination on the original Chinon/Matsushita A500 drives; how Kickstart 1.3/2.x/3.x treats a DF0 ID; whether reset
  clears Gary's motor latch; real-drive `/DKRD` and `/INDEX` pulse widths; Paula's write pulse width; the A500+
  `/MTR0` network (BUS).
- Unpowered 8520 pin behaviour; temperature in a closed A500; the default ESP-NOW rate; whether the A500's own CN12 is
  polarised (PWR).
- What the ROM and bootloader do to GPIO21 and 38–42 during download mode; whether an endless RMT transmission has no
  gap; whether Paula accepts the chosen `/DKRD` pulse width (ESP).
- JLC's own part pages and PCB prices; boxed-header dimensions from a datasheet; whether economic assembly takes a
  bottom-side through-hole part or an overhanging module (PCB).

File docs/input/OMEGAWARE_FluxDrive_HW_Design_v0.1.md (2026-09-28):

# OMEGAWARE FluxDrive — Hardware Design Document

**Rev 0.1 — working draft**
ESP32-S3 direct Shugart floppy emulator, Amiga DD target

---

## 1. Scope

A single PCB that presents itself to an Amiga as an internal DD floppy drive (DF0)
over the 34-pin Shugart bus. It receives ADF images wirelessly from the GTi over
ESP-NOW, holds them in PSRAM, and generates MFM flux directly. The Gotek is
eliminated from the system entirely.

### v1 definition (deliberately minimal)

| Item | v1 | Deferred |
|---|---|---|
| Density | DD only (250 kbit/s) | HD (500 kbit/s) |
| Format | Amiga trackdisk (11 sec/track) | IBM 720K/1.44M |
| Writes | `/WPRO` asserted always | Write capture + write-back |
| Images resident | 1 | Multi-disk set |
| Host | Amiga 500 internal DF0 | A1200, A2000, external DF1, PC |
| Radio during motor-on | deaf | — |

### Non-negotiables (established during design review)

1. **ESP32-S3-WROOM-1-N16R8.** 8 MB octal PSRAM. Not N8R2.
2. **No flash writes while a disk is mounted.** No NVS, no LittleFS, no OTA.
   A cache suspend of 20–40 ms is unsurvivable at any buffer depth. Buffer
   config changes in RAM, commit on eject.
3. **Refill ISR is `IRAM_ATTR`**, all DMA buffers in internal SRAM, flux task
   pinned to core 1, WiFi initialised from core 0.
4. **Output buffer released at power-on by hardware**, not firmware. The Amiga
   boots faster than the ESP32.
5. **RMT TX buffer ≥ 1024 symbols** (4 KB internal SRAM → ~3 ms slack at DD).

---

## 2. The 34-pin interface

### 2.1 Amiga internal pinout

All odd pins are GND. The Amiga uses a *modified* Shugart pinout — it is **not**
the PC pinout. Three differences will destroy a board if got wrong:

- Amiga selects on **DS0 (pin 10)**; PC drives use DS1
- **`/CHNG` is on pin 2** on Amiga; on PC it is pin 34
- **`/RDY` is on pin 34** on Amiga; PCs have no such signal

| Pin | Signal | Dir (from board) | Notes |
|---|---|---|---|
| 2 | `/CHNG` | **OUT** | Disk change. PC puts density select here. |
| 4 | `/MTR0` | IN | Amiga alternate motor line (drives LED) |
| 6 | n/c | — | |
| 8 | `/INDEX` | **OUT** | Optional for ADF — see §6.3 |
| 10 | `/SEL0` | IN | Drive select 0 — this is DF0 |
| 12 | n/c | — | (`/SEL1` on some machines) |
| 14 | n/c | — | |
| 16 | `/MTR` | IN | Motor on — **latched on `/SEL` falling edge** |
| 18 | `/DIR` | IN | Step direction |
| 20 | `/STEP` | IN | Step pulse |
| 22 | `/WDATA` | IN | Write data (flux from host) |
| 24 | `/WGATE` | IN | Write enable |
| 26 | `/TK0` | **OUT** | Track 0 |
| 28 | `/WPRO` | **OUT** | Write protect |
| 30 | `/RDATA` | **OUT** | **Read data — the flux stream** |
| 32 | `/SIDE` | IN | Head select |
| 34 | `/RDY` | **OUT** | Ready. Required by trackloaders (X-Copy etc.) |

**Count:** 8 inputs, 6 outputs. All active low. All open-collector on the bus.

> **VERIFY BEFORE ROUTING.** Pins 4 and 16 both carry motor-related signals in
> different Amiga models, and pin 12/14 select-line usage varies between A500,
> A1200 and A2000. Buzz out the actual target machine's connector with a meter
> before committing copper. Route pins 4, 12 and 14 to spare GPIO through the
> input buffer so they can be reassigned in firmware.

### 2.2 Electrical character of the bus

- 5 V TTL, **open collector / open drain**, active low
- Host provides pull-ups (typically 1 kΩ to +5 V on 3.5" machines)
- Sink current at 1 kΩ: **~5 mA per line**
- 5.25" systems with 150 Ω termination would need ~33 mA — out of scope for v1
  but affects driver choice if ever targeted

---

## 3. Level translation

The ESP32-S3 is 3.3 V and **not 5 V tolerant**. Every line needs conditioning.

### 3.1 Inputs (host → board)

**2 × 74LVC14A** hex Schmitt-trigger inverter, VCC = 3.3 V.

- LVC family inputs are 5 V tolerant when the part is powered at 3.3 V
- Schmitt hysteresis matters — ribbon cable in a metal case next to a switching
  PSU is a genuinely noisy environment, and `/STEP` glitches cause phantom seeks
- It inverts. Bus signals are already active-low, so a single inversion presents
  active-high logic to the S3 — handle in firmware, don't add a second stage
- Series 100 Ω on each line at the connector for ESD and ringing

Capacity: 12 inverters across two packages, 8 inputs used, 4 spare for the
verify-before-routing signals above.

### 3.2 Outputs (board → host)

**1 × 74LVC07A** hex open-drain buffer, VCC = 3.3 V.

- Open drain is mandatory — a push-pull output fighting the host's pull-up on a
  shared bus will damage something
- Sinks 24 mA min, comfortably above the ~5 mA required
- Output pins tolerate being pulled to 5 V by the host

**The safe-state trick:** fit **10 kΩ pull-ups to 3.3 V on every LVC07A input.**
At power-on the S3's GPIOs are high-impedance; the pull-ups hold the buffer
inputs high, the open drains release, and the bus floats to the host's idle
state. No `/OE` logic, no enable pin, no firmware involvement. The Amiga sees an
absent drive until firmware asserts otherwise.

This is worth being deliberate about — `ESP32FloppyTester` documents exactly the
inverse failure: on that board, flashing the ESP32 puts pins high-Z with pull-ups
and drives SELECT, MOTOR, SIDE and WRITE GATE all active, erasing whatever track
is under the head. The pull-up polarity is the whole difference.

### 3.3 Bus release on deselect

A real drive stops driving the bus when `/SEL` is deasserted. Firmware handles
this: on `/SEL` rising edge, drive all six output GPIOs high (releasing the open
drains) and stop the RMT channel. Microsecond-scale, no hardware gating needed.

Only relevant in a two-drive setup, but implement it from the start — it's three
lines of code and impossible to retrofit into a habit.

### 3.4 Pin remapping — what is and isn't possible

**The one hard rule: direction is baked into copper.** An input-buffer pin can
never become an output, and vice versa. Everything else is firmware.

FlashFloppy establishes the precedent and the scope. Its `interface=` modes remap
**only pins 2 and 34**:

| Mode | Pin 2 | Pin 34 |
|---|---|---|
| `shugart` (Amiga, Atari ST, CPC) | `DSKCHG` | `RDY` |
| `ibmpc` | unused | `DSKCHG` |
| `ibmpc-hdout` | `HD_OUT` | `DSKCHG` |
| `jppc` (Japanese PC) | unused | `RDY` |
| `jppc-hdout` | `HD_OUT` | `RDY` |

Plus `pin02 = auto` / `pin34 = auto` overrides for finer control.

**Critically: every variant of both pins is an output.** `DSKCHG`, `RDY`, `HD_OUT`,
unused — never an input. So both sit on the `74LVC07A` and mode switching costs
nothing in hardware. No dual-path, no bidirectional shifter.

Note that FlashFloppy does *not* remap drive select in firmware — that's a
physical jumper (S0 / S1 / JC on the Gotek's rear).

**Where FluxDrive can do better:** pins 10, 12 and 14 (`/SEL0`, `/SEL1`, `/SEL2`)
are all inputs, as are pins 4 and 6. Route all of them through the input buffer
and drive selection becomes a config value — **no jumper required**. Costs 3 spare
GPIO and 5 inverters, both of which the budget already has.

**Design rule for this board:**

| Pin | Direction | Fixed forever? |
|---|---|---|
| 2 | OUT | `/CHNG` ↔ `HD_OUT` — firmware |
| 34 | OUT | `/RDY` ↔ `/DSKCHG` — firmware |
| 4, 6, 10, 12, 14, 16 | IN | select/motor assignment — firmware |
| 18, 20, 22, 24, 32 | IN | fixed by function |
| 8, 26, 28, 30 | OUT | fixed by function |

That covers every documented interface variant with no hardware change. Only a
host that needs pin 2 or 34 as an *input* would break it, and no known machine
does.

---

## 4. Power tree

### 4.1 Input

The Amiga internal 34-pin connector carries **no power** — all odd pins are GND.
Power must come from the drive power connector (4-pin Berg on the A500 harness:
+5 V, GND, GND, +12 V). Only +5 V is needed; leave +12 V unconnected.

- Reverse polarity protection: series Schottky or P-FET (a reversed Berg is a
  classic way to destroy a board)
- 470 µF electrolytic + 10 µF ceramic bulk on the 5 V rail at entry

### 4.2 3.3 V generation

**Use a buck converter, not an LDO.**

ESP32-S3 with WiFi transmitting peaks around 350–500 mA. From 5 V:

| Regulator | Drop | Dissipation @ 450 mA | Verdict |
|---|---|---|---|
| AMS1117-3.3 (LDO) | 1.7 V | **0.77 W** | runs hot, marginal in SOT-223 |
| AP2112K-3.3 (LDO) | 1.7 V | 0.77 W | 600 mA rated, thermally tight |
| TPS562201 (buck) | — | ~0.15 W | **recommended** |
| MP2359 (buck) | — | ~0.15 W | acceptable alternative |

A hot LDO inside a sealed A500 next to the PSU is asking for thermal drift on a
board whose entire value proposition is timing accuracy. Spend the extra 40p.

### 4.3 Decoupling

- 100 µF + 10 µF + 100 nF at the WROOM-1 3V3 pin — the module's RF bursts are
  the largest transient on the board
- 100 nF per logic IC
- Steady state with radio off is ~50–70 mA, so most of the budget exists purely
  for the ADF transfer window

---

## 5. GPIO allocation

N16R8 consumes GPIO **26–32** (flash) and **33–37** (octal PSRAM). Avoid
strapping pins 0, 3, 45, 46. GPIO 19/20 are USB D-/D+.

Usable on WROOM-1: 1, 2, 4–18, 21, 38–42, 47, 48 (+43/44 if UART0 is sacrificed).
That is ~25 pins against 14 required — comfortable.

| Signal | GPIO | Notes |
|---|---|---|
| `/RDATA` (RMT TX) | 4 | Flux out. Keep trace short, away from switcher. |
| `/WDATA` (RMT RX) | 5 | Deferred to v2, route anyway |
| `/STEP` | 6 | Interrupt |
| `/DIR` | 7 | Sampled at STEP edge |
| `/SIDE` | 15 | |
| `/WGATE` | 16 | Interrupt |
| `/SEL0` | 17 | Interrupt (both edges — motor latch + bus release) |
| `/MTR` | 18 | Sampled at SEL falling edge |
| `/INDEX` | 8 | Optional, see §6.3 |
| `/TK0` | 9 | |
| `/WPRO` | 10 | Tied asserted in v1 |
| `/CHNG` | 11 | |
| `/RDY` | 12 | |
| Status LED | 14 | Mimic drive activity LED |
| Bus pin 4 (`/MTR0`) | 21 | IN — firmware-assignable |
| Bus pin 6 | 38 | IN — firmware-assignable |
| Bus pin 12 (`/SEL1`) | 39 | IN — firmware-assignable |
| Bus pin 14 (`/SEL2`) | 40 | IN — firmware-assignable |
| Spare | 41, 42, 47, 48 | Future: OLED I²C, SD |

Routing pins 4, 6, 12 and 14 to the input buffer is what makes drive-select and
motor-line assignment a firmware config rather than a jumper (§3.4). Four GPIO and
four inverters, both already in budget.

RMT reaches any GPIO through the peripheral matrix, so `/RDATA` placement is a
layout decision, not a constraint. Put it far from the buck converter's switch
node and give it a clean ground return.

---

## 6. Firmware architecture (summary — full detail separate document)

### 6.1 Three states

| State | Radio | Flux engine | Bus |
|---|---|---|---|
| `EMPTY` | listening | idle | `/RDY` deasserted |
| `MOUNTED_BUSY` | deaf | RMT streaming | driven when selected |
| `MOUNTED_IDLE` | listening | idle (motor off) | driven when selected |

The flux engine being idle in `MOUNTED_IDLE` is not a compromise — a real drive
isn't spinning when the motor is off, so silence on `/RDATA` is *correct
emulation*. The radio window falls out of accuracy rather than fighting it.

### 6.2 Memory plan (of 8 MB PSRAM)

| Region | Size |
|---|---|
| ADF, raw sectors | 880 KB |
| Whole disk pre-encoded as MFM bitcells | 1.91 MB |
| **Used** | **~2.8 MB** |
| Free | ~5.2 MB (HD headroom, future multi-disk) |

**Pre-encode all 160 tracks at insert time** (~50 ms, once). `/STEP` then becomes
a pointer change and the encoder leaves the host-deadline path entirely.

### 6.3 Amiga protocol specifics

- **Motor is latched, not level-read.** The drive latches `/MTR` on the falling
  edge of `/SEL`. A naïve `digitalRead(MTR)` reports "off" every time the machine
  deselects, including mid-load. Latch it in the `/SEL` ISR.
- **`/RDY` is required, and pin 34 is dual-purpose.** Amiga hosts expect a drive
  ID sequence on pin 34 when the motor is *disabled*, and `RDY` when the motor is
  *enabled*. FlashFloppy's default `shugart` mode ignores this and attaches `RDY`
  permanently — which works because a mounted image asserting `RDY` happens to
  match the DD drive ID anyway. The accurate approach multiplexes ID and `RDY`
  based on motor state with a realistic ~500 ms motor-on-to-`RDY` delay, and
  FlashFloppy can only do this on AT32F435-based Goteks because slower ones can't
  emulate the signals fast enough.

  **The S3 is comfortably faster than an AT32F435, and the `/SEL`-`/MTR` latch
  state machine this needs is already required for the motor-idle window.** So
  implement the accurate behaviour as the default, not as a premium option. It is
  a genuine fidelity edge over most Goteks in the field, and it's the difference
  between working and not working for HD images and external-drive use.

  AmigaOS tolerates a missing `/RDY`; trackloaders such as X-Copy Pro do not.
- **`/CHNG` handshake.** Assert on eject; clear **only** on a subsequent `/STEP`
  pulse. Otherwise AmigaDOS never notices the new disk.
- **`/INDEX` is optional for ADF.** Paula DMAs raw MFM and hunts `0x4489` sync
  words; it has no rotational-position requirement. Route it, populate it, leave
  it unasserted in v1.
- **Track wrap lands in the gap.** A real Amiga track has padding after sector 11
  before the first sync word. Point the RMT wrap at the middle of that gap — any
  minor discontinuity is invisible because nothing is being decoded there. No
  sub-tick seamlessness required.

### 6.4 Eject transaction

GTi retries `EJECT(txn_id)` at ~200 ms until the S3's motor-off window opens.
Must be **idempotent** (eject on an already-ejected slot returns `DONE`, not an
error — a lost ACK otherwise wedges the GTi) and **atomic** (if motor re-latches
mid-transaction, abort and report `BUSY`; never leave `/CHNG` asserted with the
image still mounted).

Failure case to handle in UI: trackloaders that leave the motor spinning during
gameplay never open a window. Show "waiting for drive idle" rather than a spinner,
and offer force-eject after ~10 s that fires on the next `/SEL` deassert.

---

## 7. Bring-up order

Staged so each step is independently verifiable and nothing depends on the Amiga
until it must.

| # | Step | Pass criterion |
|---|---|---|
| 0 | **Bench gate** (§8) | No gap or jitter at buffer boundary |
| 1 | Board powered, no bus connection | 3.3 V clean, module boots, LVC07A outputs float high |
| 2 | Bus connected, firmware halted | Amiga boots normally, sees no drive |
| 3 | Input capture only | Serial log shows `/SEL`, `/MTR`, `/STEP`, `/SIDE` from real Amiga |
| 4 | Static outputs | `/TK0`, `/WPRO`, `/RDY` assert; Amiga reports a drive present |
| 5 | Hardcoded synthetic track | Amiga reads *something* (garbage acceptable) |
| 6 | Real ADF, one track | Correct sector data on that track |
| 7 | Full disk | Workbench disk boots |
| 8 | ESP-NOW insert from GTi | Wireless load, then boot |
| 9 | Eject transaction | Disk swap recognised by AmigaDOS |

Steps 3 and 4 need no flux engine at all and will shake out most wiring errors.

---

## 8. The bench gate (do this first)

Everything above is contingent on one unvalidated property: **RMT ping-pong
buffer continuity under sustained load.** No Amiga, no level shifters, no ADF
parsing required.

### Setup
- Bare ESP32-S3 dev board, scope on the RMT TX pin
- Synthetic 11-sector Amiga MFM track in PSRAM, 1024-symbol ping-pong
- Loop indefinitely with the wrap point in the track gap
- ESP-NOW flooding the device from a second ESP32 throughout

### Measure
1. Interval histogram — expect tight clusters at 4/6/8 µs, spread < 0.2 µs
2. **Every buffer boundary** — no gap, no doubled interval, no accumulating drift
3. **The wrap point** — same
4. Run for 30+ minutes, not 30 seconds
5. Repeat with radio idle vs flooding — quantify the delta

### Interpreting it

The prior is better than "unknown". `ESP32FloppyTester` writes full MFM tracks to
real disks at 4/6/8 µs intervals and reads them back with passing CRCs — that is
200 ms of gapless flux across roughly 34 consecutive buffer boundaries, on older
silicon, verified magnetically. This test extrapolates 34 proven boundaries to
thousands; it does not ask whether ESP32 flux generation works at all.

**If it fails** and IRAM placement plus core pinning doesn't fix it: the fallback
is an RP2350 as a dumb flux coprocessor over SPI, with the S3 retaining radio and
storage. Leave 4 spare GPIO and an unpopulated footprint against that possibility
— it costs nothing now and saves a respin.

---

## 9. BOM (indicative)

| Qty | Part | Purpose | ~£ |
|---|---|---|---|
| 1 | ESP32-S3-WROOM-1-N16R8 | MCU, 8 MB PSRAM | 4.50 |
| 2 | 74LVC14A (SO-14) | Input Schmitt, 5 V tolerant | 0.60 |
| 1 | 74LVC07A (SO-14) | Output open drain | 0.35 |
| 1 | TPS562201 + L/C | 3.3 V buck | 0.90 |
| 1 | 34-pin IDC male header, 2.54 mm | Bus | 0.40 |
| 1 | 4-pin Berg male | Power | 0.20 |
| — | Passives, 100 Ω series ×14, 10 k ×6 | | 0.80 |
| 1 | microSD socket (**unpopulated**) | Future persistence | 0.30 |
| 1 | PCB, 2-layer, ~50 × 40 mm | | 1.50 |
| | | **Total** | **~£9.55** |

Against a Gotek at ~£15 plus a SuperMini plus a USB socket, and with one fewer
board in the machine.

---

## 10. Open items

| # | Item | Blocks |
|---|---|---|
| 1 | **Bench gate (§8)** | Everything |
| 2 | Buzz out target A500 connector — pins 4, 12, 14 | ~~Routing~~ firmware config only (§3.4) |
| 3 | Confirm A500 drive power connector type and pinout | Power section |
| 4 | Verify `/RDY` timing expectation of X-Copy specifically | v1 acceptance |
| 5 | Decide write policy for v2 (volatile RAM-disk vs SD vs push-to-GTi) | SD footprint |
| 6 | ESP-NOW protocol spec — separate document | Step 8 |
| 7 | Mechanical: does the board need to fit the DF0 bay, or sit loose? | Outline |
| 8 | Measure actual S3 WiFi ISR stall tail — validates policy-deaf assumption | Buffer sizing |

Item 8 is the one that could still change a design decision: if the WiFi ISR tail
is materially worse than the ~250 µs assumed, the 1024-symbol buffer stops being
comfortable and the deaf-while-spinning policy needs to become hardware-deaf.

---

*OMEGAWARE — draft, not yet reviewed against a physical machine.*

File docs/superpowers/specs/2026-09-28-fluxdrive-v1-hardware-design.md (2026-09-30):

# FluxDrive v1 — hardware design

**Status:** v0.4, 2026-09-29. Dimitri approved v0.2; v0.3 took in the schematic review, v0.4 the layout review and Dimitri's two decisions on it (4 layers; the antenna on the board).
**Authors:** Dimitri Hilverda (GTi co-author), with Claude
**Based on:** `docs/input/OMEGAWARE_FluxDrive_HW_Design_v0.1.md` (Mez, [mesarim](https://github.com/mesarim)), `docs/input/FluxDrive_v0.1_review_notes.md`
(breadboard measurements), and the A500 bus research done for the Nano-Tek Rev 2.0 GTi.
**Review:** `docs/reviews/2026-09-29-spec-review.md` lists every finding (BUS-, PWR-, SI-, ESP-, PCB-numbers below)
and what was done with it; `docs/reviews/2026-09-29-schematic-review.md` does the same for the schematic (SBUS-,
SPWR-, SESP-, SPCB-, SCODE-numbers), `docs/reviews/2026-09-29-layout-review.md` for the layout (LBUS-, LPWR-,
LESP-, LPCB-, LCODE-numbers).

FluxDrive is an Amiga floppy drive emulator built around one ESP32-S3 and nothing else: no Gotek, no second
microcontroller. It plugs into the A500's internal floppy connector, holds a disk image in PSRAM and generates the
MFM flux stream itself. Disk images come from the GTi touchscreen over ESP-NOW, or from a phone over WiFi.

The goal is the cheapest emulator that still has everything the GTi offers. Target: under €10 in parts per board at
50 pieces, SMD assembled by JLCPCB, through-hole parts soldered by hand.

---

## 1. Scope of v1

| | v1 | Later |
|---|---|---|
| Host | A500 internal DF0 | A1200, A2000, external DF1 |
| Density | DD, 11 sectors per track | HD, IBM formats |
| Writes | `/WPROT` always asserted. `/DKWD` and `/DKWE` are wired to GPIO, so writing is firmware only. | Write capture and write-back |
| Images | one ADF resident | several disks, disk sets |
| Image source | GTi over ESP-NOW; WiFi upload page for use without a GTi | microSD (footprint is not on v1) |
| Radio while the motor runs | off | — |

Not in v1: pass-through to a real drive, the drive-swap switch of the Nano-Tek, an OLED or buttons for picking
disks. The GTi is the user interface.

## 2. Facts this design leans on

### 2.1 The A500 internal floppy connector

From the A500 schematic Rev 6a/7 (amigawiki `A500_R6.pdf`; sheet numbers from the title blocks), the Hardware
Reference Manual (HRM) appendix E, the Gary specification and the 8520 specification. Checked in review (BUS).

- Connector CN11, even pins: 2 `/CHNG`, 4 `/MTR0`, 6 NC, 8 `/INDEX`, 10 `/SEL0`, 12 `/SEL1`, 14 NC, 16 `/MTR0`,
  18 `/DIR`, 20 `/STEP`, 22 `/DKWD` (write data), 24 `/DKWE` (write gate), 26 `/TRK0`, 28 `/WPROT`,
  30 `/DKRD` (read data), 32 `/SIDE`, 34 `/RDY`. Odd pins are ground, except pin 3 (NC). Pins 4 and 16 are one
  net.
- **Pin 2 is `/CHNG` and pin 34 is `/RDY`.** A PC drive has disk change on pin 34. Getting this wrong cost the
  breadboard build weeks.
- **Motor.** `/MTR0` is latched for DF0 by Gary (MTRON, U5 pin 46, through U36 74LS38, sheet 4; Gary spec §2.1:
  "latched disk 0 motor on", following `/SEL0` within 50 ns). It is a plain level. The breadboard's "stream dies
  on deselect" came from the 74HCT125 run at 3.3 V (§2.2). Only the external port gets the raw motor line.
- **Who drives what.**
  - `/STEP`, `/DIR`, `/SIDE`, `/SEL0–3` come straight from CIA-B (8520 port B): internal pull-ups of 3.1–5 kΩ,
    sinks at least 13 mA at 0.4 V.
  - `/MTR0`, `/DKWD`, `/DKWE` go through a 74LS38 (open collector, 24 mA). On the A500+ it is a 74LS05 (8 mA
    maximum, 0.5 V at 8 mA).
  - `/MTR0` has R506 10 kΩ to VCC on the motherboard, plus the base of the drive-LED transistor Q503 (sheet 6).
    `/DKWD` and `/DKWE` have **no** pull-up on the motherboard.
  - Back to the Amiga: `/DKRD` has 1 kΩ (R305, sheet 4), `/INDEX` 10 kΩ (RP501, sheet 6) and goes to CIA-B /FLAG.
    `/RDY`, `/TRK0`, `/WPROT` and `/CHNG` only have CIA-A's internal pull-ups.
  - `/STEP`, `/DIR`, `/SIDE`, `/SEL1`, `/DKWD` and `/DKWE` are shared with the external DB23 port, which puts 100 pF
    filters on them (sheet 7), even with nothing plugged in.
- **Drive termination.** HRM appendix E: "Each device must provide a 1000-Ohm pull-up resistor on those outputs
  driven by an open-collector device."
- **Power** is on a separate 4-pin connector CN12: 1 = +5 V, 2 = GND, 3 = GND, 4 = +12 V (sheet 8), no fuse. The
  34-pin connector carries none. A mini-Berg forced on the wrong way round puts **+12 V on the 5 V pin**.
- **Drive ID and disk state** (HRM appendix E). With the motor on, `/RDY` means "disk in and up to speed". With the
  motor off, `/RDY` carries the drive ID, which restarts on every motor on→off transition; a DD drive's ID is all
  ones (active low), so it simply holds `/RDY` low while selected with the motor off. The change flop is "set at
  power up or when no disk is installed" and reset by a step while selected, only with a disk in. `/TRK0` reports the
  head position with or without a disk. Kickstart does not probe DF0 at boot, but FlashFloppy's HD support reads its
  ID, so v1 answers the ID on DF0 as well.

### 2.2 What the breadboard build measured

ESP32-S3 at 240 MHz, buffers in PSRAM, Arduino core 3.3.7 (details in `docs/input/FluxDrive_v0.1_review_notes.md`):

- MFM-encoding one DD track: about 3.5 ms. Converting it naively to RMT symbols: another 12–17 ms.
- The Arduino RMT layer has no stop and no TX-done callback, and mixing it with the IDF RMT driver silently
  produces no output. Firmware for this board is therefore pure ESP-IDF.
- 74HCT125 powered at 3.3 V on the input side is out of spec and caused the "weak select line" symptoms.
  This design uses 74LVC throughout.

### 2.3 The ESP32-S3 at power-up

ESP32-S3 datasheet v2.2, table 2-2: GPIO1–14, GPIO15/16 (XTAL_32K) and GPIO17 are driven **low** for about 60 µs
during chip power-up, GPIO18 low and then high, GPIO19/20 high. A driven pin overrides any pull-up. The WROOM-1
datasheet says EN low powers the chip off, so a RESET press or a brown-out very likely repeats the glitch while the
Amiga runs. GPIO21 and GPIO38–48 start as inputs without a glitch. Every output that can disturb the bus is
therefore on GPIO21 or 38–42 (ESP-1).

## 3. Block diagram

```
 A500 CN11 (34-pin) ─┬─ pull-ups to +5V_A
                     └─100 Ω──► 2× 74LVC14A (Schmitt, 3.3 V) ──────────► ESP32-S3-WROOM-1-N16R8
                     ◄──33 Ω─── 74LVC07A (open drain, 3.3 V) ◄────────────  (outputs on GPIO21, 38–42)

 A500 CN12 ──► eFuse (5.7 V clamp) ──► +5V_A ──Schottky──┐
 USB-C VBUS ──► USBLC6 ────────────────────────Schottky──┴─► V5SYS ──► buck TLV62569 ──► 3V3
 +5V_A ──► divider ──► AMIGA_PWR (GPIO1)
                  BOOT, RESET, activity LED, 6-pin UART/recovery header, spare GPIO header, test pads
```

## 4. Bus interface

### 4.1 Pin by pin

| Pin | Signal | Direction (from FluxDrive) | Buffer | ESP32-S3 GPIO | On the board |
|---|---|---|---|---|---|
| 2 | `/CHNG` | out | LVC07A | 42 | 33 Ω series |
| 4 | `/MTR0` (alt.) | in | LVC14A | 4 | no pull-up (unfitted pad) |
| 6 | NC on A500 | in | LVC14A | 8 | 10 kΩ to +3.3 V |
| 8 | `/INDEX` | out | LVC07A | 39 | 33 Ω series |
| 10 | `/SEL0` | in | LVC14A | 17 | 1 kΩ to +5V_A |
| 12 | `/SEL1` | in | LVC14A | 9 | 10 kΩ to +5V_A |
| 14 | NC on A500 | in | LVC14A | 10 | 10 kΩ to +3.3 V |
| 16 | `/MTR0` | in | LVC14A | 11 | no pull-up (unfitted pad; R506 on the motherboard) |
| 18 | `/DIR` | in | LVC14A | 7 | 1 kΩ to +5V_A |
| 20 | `/STEP` | in | LVC14A | 6 | 1 kΩ to +5V_A |
| 22 | `/DKWD` | in | LVC14A | 5 | 4.7 kΩ to +5V_A |
| 24 | `/DKWE` | in | LVC14A | 16 | 4.7 kΩ to +5V_A |
| 26 | `/TRK0` | out | LVC07A | 40 | 33 Ω series |
| 28 | `/WPROT` | out | LVC07A | 41 | 33 Ω series |
| 30 | `/DKRD` | out | LVC07A | 38 | 33 Ω series |
| 32 | `/SIDE` | in | LVC14A | 15 | 1 kΩ to +5V_A |
| 34 | `/RDY` | out | LVC07A | 21 | 33 Ω series |

Eleven inputs on twelve inverters (one spare, input tied to ground). Six outputs on the six LVC07A buffers.

- The inputs sit on GPIOs that glitch low at power-up. That is harmless: the LVC14A output is low whenever its bus
  line is idle, so the glitch only overlaps an asserted line for 60 µs. GPIO18, which also glitches high, is not
  used (ESP-2).
- On the WROOM-1 the outputs are on the right edge and the bottom-right corner; the LVC07A goes there, the LVC14As
  on the left. `/DKRD` (pin 30) gets the shortest track.

### 4.2 Inputs

- **74LVC14A** hex Schmitt inverter at 3.3 V, SOIC-14. Its inputs tolerate 5.5 V while powered at 3.3 V, and its
  hysteresis (at least 0.3 V) is what rejects ringing on the ribbon. It inverts, so the ESP sees active-high
  signals.
- **Topology per line, in this order:** connector pin → pull-up node → 100 Ω → LVC14A input, with 100 kΩ from the
  LVC14A input to +3.3 V. The pull-up must be on the connector side: on the buffer side, 4 mA through the 100 Ω
  would lift a low to 0.92 V, above the LVC14A's minimum VT− of 0.8 V (BUS-3). The 100 Ω limits current for ESD
  and when the board is unpowered. On the bench (USB only, no Amiga, no ribbon) +3V3 leaks through the 100 kΩ
  and the pull-ups into +5V_A, which the AMIGA_PWR divider (§5) holds at about 0.5 V. Every input then sits at a
  defined level: 0.5–0.75 V on the lines pulled up to +5V_A (they read as asserted), 3.3 V on the others. The
  firmware ignores them while AMIGA_PWR is low (SPWR-4).
- **Pull-up values** (to +5V_A, the Amiga side of the power OR, §5):

  | Lines | Value | Why |
  |---|---|---|
  | `/STEP`, `/DIR`, `/SIDE`, `/SEL0` | 1 kΩ | HRM termination. CIA-B load 5 mA, plus 5 mA if an external DF1 terminates too, plus 1.6 mA internal = 11.6 mA, below 13 mA. |
  | `/DKWD`, `/DKWE` | 4.7 kΩ | No host pull-up, shared with the external port: keeps an A500+ 74LS05 inside 8 mA with a DF1 attached. |
  | `/SEL1` | 10 kΩ | Not used in v1. |
  | `/MTR0` (pins 4, 16) | none | The motherboard has R506 10 kΩ and the LED driver; 2 × 1 kΩ would exceed the A500+'s 74LS05. |

- Pull-ups on +5V_A draw no current when the Amiga is off, so nothing back-powers a dead Amiga (BUS-4, PWR-2).
- Optional 100–220 pF pads (not fitted) after the 100 Ω on `/STEP`, `/SEL0`, `/SEL1` and `/MTR0`; none on `/DKWD`.
- The two NC pins (6, 14) get 10 kΩ to +3.3 V so the buffer input never floats.

### 4.3 Outputs

- **74LVC07A** hex open-drain buffer at 3.3 V, SOIC-14: sinks 24 mA (VOL ≤ 0.4 V at 12 mA), the outputs may be
  pulled to 5 V by the host, and it has Ioff (±10 µA at VO = 5.5 V, VCC = 0), so an unpowered FluxDrive does not load
  the bus.
- **33 Ω in series** on every output, against ringing and EMI into the ribbon. At 5 mA it adds 0.17 V to the low
  level.
- **Power-on safe state:** 10 kΩ pull-up to +3.3 V on every LVC07A input. The six output GPIOs (21, 38–42) have no
  power-up glitch (§2.3), so the buffers stay off until the firmware asserts a line. GPIO39 also has a weak
  pull-up at reset.
- **Releasing a line** always means switching the GPIO to input so the 10 kΩ takes over, never relying on a
  peripheral's idle level (§9).
- **Gating on select** is firmware (§9). Two drives on one bus would need it in logic; that is for external-DF1
  support (§13).

### 4.4 The connector: ribbon or plug-on

The 2×17 holes take either part:

- a **boxed male header on the top side**, for a ribbon cable like a normal drive; or
- a **female 2×17 socket on the bottom side** (8.5 mm, e.g. DS1023-2*17SF11), which plugs straight onto the A500's
  male header. The board then sits about 11 mm above the motherboard.

Both mate correctly on the same holes because the footprint uses the pin-header pattern (pin 2 at +2.54 mm);
KiCad's socket footprint is mirrored and must not be used. This was worked out on the Nano-Tek CN3 and confirmed in
review (PCB-2).

- The even (signal) row faces the board interior, so signals escape without passing between the ground pins.
- A pin-1 triangle and a "this edge to …" mark on both silkscreen layers, because a bare header accepts the socket
  rotated or shifted by a row. The plug-on variant also gets a mechanical key: a printed foot in the mounting holes
  (§8).
- The overhang direction over the motherboard follows from the fit test (O7).
- Both connectors are hand-soldered, so the buyer picks.

## 5. Power

- **Input:** polarised 4-pin floppy power header **TE 171825-4**, vertical (LCSC C210162), fed from CN12. It is the
  same Berg family as on the Gotek and the Nano-Tek; their right-angle 171826-4 has almost no stock at LCSC (SPCB-1).
  For runs of 50, buy it from a distributor; it is hand-soldered anyway.
  A bare 1×4 header is not allowed: a plug shifted by one pin shorts the PSU. Only +5 V is used; +12 V is not
  connected.
- **eFuse** on CN12 pin 1: TPS259531 (checked against datasheet SLVSE57C in the schematic review) with an over-voltage clamp at
  5.7 V, a current limit and soft-start (about 22 nF). It survives a reversed plug (+12 V on the 5 V pin) **fitted
  with the power off**, and keeps it off the bus pull-ups, the LVC14A inputs (abs. max 6.5 V) and the Amiga's own
  pins. Its output is **+5V_A**. A reversed plug pushed on while the PSU runs can ring above the eFuse's 20 V
  absolute maximum: an unfitted pad for an SMAJ13A TVS (13 V standoff) sits on its input for that (SPWR-3).
- **Power OR:** `+5V_A` → Schottky (SS34) → **V5SYS**; USB-C VBUS → USBLC6-2SC6 → Schottky (SS34) → V5SYS. There
  is no P-FET: a reverse-polarity P-FET conducts both ways and would let USB feed the whole A500 (PWR-1).
  - The Amiga cannot reach VBUS, and USB cannot power +5V_A or the Amiga (only the 100 kΩ leakage of §4.2, BUS-4).
  - The USBLC6's supply pin goes to +3V3, not to VBUS: on VBUS, the ESP32's D+ pull-up would lift VBUS to about
    2.7 V through the ESD diodes, and a USB-C host on a C-to-C cable would then not switch VBUS on. A 10 kΩ bleeder
    holds VBUS at 0 V without a cable against the leakage of the VBUS diode (SPWR-1).
  - Alternative: two LM66100 ideal diodes instead of the Schottkys (±6 V abs. max, behind the eFuse).
- **3.3 V:** buck converter **TLV62569DBVR** (2.5–5.5 V in, 2 A, 100 % duty cycle), 2.2 µH, 22 µF out plus the
  module's own 22 µF, and an unfitted 15 pF feed-forward pad across the top feedback resistor (SPWR-5). It runs
  from USB's 4.75 V minus a Schottky; the TPS562201 of the input document needs 4.5 V in
  and does not (PWR-5). The ESP32-S3 peaks at 350–500 mA while transmitting; an LDO would burn up to 0.8 W inside
  the closed case.
- **Capacitors:**
  - eFuse input: 1 µF ceramic.
  - +5V_A: 2 × 47 µF 10 V X5R ceramic (1206, LCSC C96123), no 6.3 V parts: the clamp is 5.7 V (SPCB-2). The eFuse
    soft-start separates them from the cable, so the hot-plug overshoot of a ceramic on a bare cable does not apply.
  - V5SYS (buck input, seen by USB through its diode): 10 µF + 100 nF, no more (USB allows 10 µF on VBUS). An
    unfitted 1 Ω + 4.7 µF damper pad sits next to them in case a USB hot-plug rings V5SYS towards the buck's 6 V
    absolute maximum; if it is fitted, the 10 µF becomes 4.7 µF (SPWR-2).
  - 22 µF + 100 nF at the module's 3V3 pin, 100 nF per logic IC.
- **AMIGA_PWR:** 1 kΩ / 1.5 kΩ divider from +5V_A to GPIO1 (3.0 V at 5 V, 3.5 V at the clamp, 2 mA). It is this
  stiff so that on USB alone the leakage of §4.2 leaves it at about 0.3 V, well below the ESP32's 0.83 V low
  threshold (SESP-1). While it reads low, the firmware keeps every output released and ignores the inputs, because
  with the Amiga off every input reads as asserted.
- **Unsupported:** the 34-pin cable connected without the power cable. The pull-ups then hang on a dead +5V_A and
  the bus levels are undefined. The manual says so.

## 6. ESP32-S3 module

- **ESP32-S3-WROOM-1-N16R8** (exactly this variant: 16 MB flash, 8 MB octal PSRAM, VDD_SPI 3.3 V, so GPIO47/48 are
  3.3 V pins). The whole disk pre-encoded (1.9 MB) plus the ADF (880 KB) fits with room to spare, so a head step
  becomes a pointer change and no encoding happens under the host's deadline.
- **Temperature:** the R8 modules are rated −40…65 °C ambient, 85 °C with PSRAM ECC enabled. ECC is on (7.5 MB left);
  the lid-closed temperature is measured in bring-up (§11).
- **WROOM-1U-N16R8** (U.FL, external antenna) has the same 40 pads and thermal pad (WROOM-1 datasheet figures 11-1
  and 11-2). It is the fallback if the PCB antenna does not reach the GTi from inside the A500's shielded case (O5).
  It only helps if the antenna cable can leave the shield.
- **Antenna** (Espressif hardware design guidelines, PCB layout):
  - the antenna end of the module lies at the north board edge (0.5 mm inside it, so JLC can assemble the
    board: O10), over board material that is free of copper on all four layers, with its feed point near the
    edge. An overhanging antenna would reach a little further, but JLC's economic assembly wants every part inside
    the outline (Dimitri's decision after the layout review, LPCB-1);
  - no copper on any layer, no components and no ground pour under or beside it; dense ground vias along the
    keep-out border;
  - at least 15 mm clearance from metal in the housing, in all directions. In the plug-on variant the motherboard is
    closer than that: the range test decides (O5).
- **Pins:**

  | GPIO | Use |
  |---|---|
  | 0 | BOOT button, 10 kΩ pull-up to 3.3 V, no capacitor (strapping pin) |
  | 1 | AMIGA_PWR sense (§5) |
  | 2 | activity LED |
  | 4–11, 15–17 | bus inputs (§4.1) |
  | 19, 20 | USB D−, D+ |
  | 21, 38–42 | bus outputs (§4.1) |
  | 43, 44 | UART0 TX, RX: recovery and console header (§7) |
  | 13, 14, 47, 48 | spare header; 47/48 are glitch-free for future outputs |
  | 3, 12, 18, 45, 46 | not connected. GPIO3, 45 and 46 are strapping pins; GPIO45 must stay low or floating (it selects the flash voltage). |

  GPIO26–32 (flash) and 33–37 (octal PSRAM) are taken inside the module.
- **Boot and reset:** EN with 10 kΩ pull-up and 1 µF to ground (Espressif's values); a RESET button on EN; the BOOT
  button on GPIO0.
- **Module ground pad:** windowpane paste pattern, soldered to ground with tented vias.

## 7. Other parts on the board

- **USB-C** (USB 2.0 only) on GPIO19/20 for flashing and the serial console:
  - separate 5.1 kΩ on CC1 and CC2 (sink); A6–B6 and A7–B7 tied;
  - 22 Ω series pads on D+/D− near the module (0 Ω fitted if not needed) and unfitted capacitor pads to ground;
  - USBLC6-2SC6 at the connector, its supply pin on +3V3 (§5);
  - automatic download mode over USB-Serial/JTAG needs no extra parts, but stops working if the firmware
    reconfigures GPIO19/20, switches that controller off or sleeps. Recovery is then BOOT + RESET, or the UART header.
- **Activity LED** on GPIO2.
- **Recovery/console header** (6 pins, 2.54 mm, holes only): TX (GPIO43, 470 Ω in series), RX (GPIO44), EN, IO0,
  3.3 V, GND. A USB-serial adapter can reflash the board through it even if USB is dead. The ROM prints its boot
  messages on UART0, so a wired link to the GTi uses UART1 on the spare header, not this one.
- **Spare header** (holes only): GPIO13, 14, 47, 48, 3.3 V, GND. It replaces Mez's unpopulated RP2350 footprint:
  that fallback needs a crystal, flash and a second power domain, and is better as a separate board if the bench gate
  ever fails.
- **Test pads, on the top side:** `/DKRD`, `/INDEX`, `/SEL0`, `/STEP`, `/MTR0` (both sides of the buffers), +5V_A,
  V5SYS, VBUS, 3V3, EN, GND. The 34-pin connector itself is the interface for a functional test jig.

## 8. PCB

- **4 layers**, 1.6 mm, JLC standard process: F.Cu signals, In1.Cu a solid GND plane, In2.Cu a solid +3V3 plane,
  B.Cu signals (Dimitri's decision after the layout review: on 2 layers the router cut the bottom plane into
  pieces under the buffers, LBUS-1/LPWR-1). All SMD on the top side, assembled by JLC except the ESP32 module
  (Dimitri places it himself, 2026-09-30; `tools/assembly.py`: no paste on its pads, left out of JLC's BOM and
  CPL). **Hand-soldered** by the builder: every through-hole part (the 34-pin connector, top or bottom (§4.4), the power header, the two headers of
  §7). Unfitted pads are 0603, so the builder can fit them by hand (SPCB-3).
- **Size:** 60 × 54.5 mm: at least 56 mm along the connector axis (a 34-way boxed header body is 51–54 mm long),
  48 mm for the parts and 6.5 mm for the antenna; the fit test (O7) can still change it. A 54 × 10 mm area on the top side above the
  connector stays free of SMD parts, for the header body and for the soldering iron.
- **Floorplan** (top view):
  - south edge: the 2×17 connector, even row inward;
  - above it: the resistors, the two LVC14As (one under pins 4–16, one under pins 18–32, each gate in the
    connector's order), the LVC07A at the pin 26–34 end, so `/DKRD` is a track of about 10 mm without a via;
  - north half: the module, its antenna along the north edge;
  - west strip: the power header next to the 34-way connector (vertical, so plugging it in pushes straight down
    through the socket), eFuse, bulk capacitor, diodes, buck; USB-C on the west edge near GPIO19/20, with the ESD
    part at the connector;
  - east edge: buttons and LED, outside the antenna keep-out.
- **Mechanics:** two 3.2 mm non-plated holes at the far end for a nylon standoff or a printed foot; they are also
  tooling holes. All bottom-side vias tented, no exposed copper on the bottom (the plug-on board may rest on
  motherboard parts). Clearance under the A500's shield is part of the fit test.
- **Grounding and noise:** In1 is an unbroken ground plane under the whole board (apart from the antenna area);
  every GND pad of a logic IC and of its decoupling capacitor has its own via to In1 within 1.6 mm, none in a pad;
  +3V3 pads reach In2 through a via of their own or of a pad next to them (rev A: U2-U4 pin 14 through their
  100 nF, the row B pull-ups share four vias, the buck output enters In2 through one via; rev B gives each IC pin
  14 and C17/L1 their own vias); the odd connector pins are plated through to In1; the GND pours on F.Cu and B.Cu
  are stitched to In1 about every 5 mm, closer along the edges. No track runs between the rows of the 34-way
  connector (the plug-on socket is soldered there); between its GND pins only the five test-pad stubs, on F.Cu.
  Rev A has `/CHNG_D` running along the outside of the GND pin row, 0.25-0.30 mm from the pads (the README asks
  for a continuity check after soldering J1); rev B keeps tracks 0.8 mm from that row. The buck sits at least 15 mm from `/DKRD` and the antenna.
  Buck layout per the TLV62569 datasheet: tight input capacitor loop, small switch node with nothing under it or the
  inductor (no track under it on B.Cu, none between its pads), separate feedback sense track.
- **USB pair:** full speed (12 Mbit/s) only, so the impedance is not controlled (LESP-3): D+ and D− run close
  together over the In1 plane, the 22 Ω series pads next to the ESD part, the unfitted 10 pF pads on their module
  side.
- **Rules:** tracks and spacing 0.2 / 0.2 mm (0.15 mm allowed at the module), power 0.3 mm (the eFuse's 0.5 mm
  pitch pads take no wider track; 0.3 mm carries its 0.95 A limit); vias 0.3 mm drill /
  0.6 mm pad; through-hole annular ring ≥ 0.25 mm, header holes 1.0 mm with 1.7 mm pads; copper ≥ 0.3 mm from the
  edge; thermal reliefs on the ground pins of the 34-way and the power header; silkscreen text ≥ 1.0 mm with
  0.15 mm lines, 0.15 mm clear of pads.
- **Production features:** three fiducials (1 mm copper, 2 mm mask opening); a 15 × 6 mm silkscreen box on the
  bottom for a serial number and "FluxDrive v1 rev A"; a chosen position for JLC's order number.
- **Panel:** none needed: the board is ordered as a single board (economic assembly takes 2–50 pieces). A 2-up
  panel with mouse bites is possible if a larger run wants it; tracks and parts keep at least 0.3 mm from the
  edges.
- **Test pads:** 1.0 mm, on the top side, for a probe (SPCB-8: no pogo-pin fixture in v1). The connector-side ones
  sit in the strip south of J1; a map of all sixteen is in the README.

## 9. What the firmware must do because of this hardware

Firmware is a separate design; these points follow from the board and are fixed here.

- **Pure ESP-IDF.** Flux output through RMT or I2S/LCD_CAM; the bench gate picks one.
  - RMT: one endless transmission whose encoder wraps the track pointer itself (no start/stop at the wrap); the
    channel is created from a task pinned to core 1 at the highest interrupt priority; cache-safe ISR options on.
  - I2S/LCD_CAM: a continuous DMA ring; it can output `/DKRD` and `/INDEX` in lockstep.
  - The flux interrupt only reads internal RAM: on each head step a task copies the current track (about 12 KB of
    MFM bitcells) from PSRAM to internal RAM. An ISR that is safe with the flash cache off must still not touch PSRAM
    during a flash write.
- **No flash writes while a disk is mounted.** Wi-Fi keeps its settings in RAM (`esp_wifi_set_storage(WIFI_STORAGE_RAM)`),
  because by default every Wi-Fi config call writes flash. OTA updates (two slots with rollback, the normal way to
  update a fitted board) and the 15 s BOOT wipe only run with no disk mounted.
- **Bus release** (ESP-3): the first statement in `app_main`, and a panic/shutdown hook, switch the six output GPIOs
  to input. Releasing a line always means switching it to input. RMT channels use idle and end-of-transmission level
  1 (or `invert_out`); a GPIO is set high before it is made an output; I2S `auto_clear` must not send zeros onto
  `/DKRD`.
- **AMIGA_PWR low:** every output released, inputs ignored. Reading GPIO1 with ADC1_CH0 and a threshold of about
  2.4 V (+5V_A above about 4 V), with some hysteresis, also covers the reverse leakage of the +5V_A Schottky, which grows when hot (SPWR-4).
- **RTC slow clock:** internal only, never the external 32 kHz crystal: GPIO15/16 are bus inputs, driven by the
  LVC14A (SBUS-3).
- **Spare header J5:** GPIO13, 14, 47 and 48 get their internal pull-ups until something uses them; their tracks
  are 33–48 mm long and would float (LESP-10).
- **Outputs are gated by `/SEL0` only**, not by whether an image is mounted. While deselected all six are released.
- **Selected, no disk:** `/CHNG` asserted, `/WPROT` asserted, `/TRK0` live (it follows the head), no `/DKRD`, no
  `/INDEX`.
- **`/CHNG`:** set at power-up and while no disk is mounted; cleared only by a `/STEP` pulse while selected with a
  disk mounted. An eject sets it again.
- **`/RDY`:** with the motor off and the drive selected, held low (the DD drive ID, all ones active low). With the
  motor on, asserted about 500 ms after motor-on if a disk is mounted, not asserted without a disk. The same rule is
  used on DF0 and on DF1–DF3.
- **`/MTR0`:** read as a level (Gary latches it) with a short glitch filter. If it is ever sampled on the `/SEL0`
  edge, the sample must be taken at least 100 ns after the edge.
- **`/INDEX`:** a 2 ms low pulse every 200 ms, only with the motor on, a disk mounted and the drive selected, placed
  at the track wrap.
- **`/DKRD` pulse width:** fixed in the firmware spec after measuring a real drive (O12).
- **eFuses:** never burn `EFUSE_STRAP_JTAG_SEL` (GPIO39–42 must stay GPIO); `EFUSE_DIS_PAD_JTAG` may be burnt to lock
  that in. `EFUSE_DIS_USB_JTAG` only together with `EFUSE_DIS_PAD_JTAG`: alone it moves JTAG onto GPIO39–42,
  and GPIO40 would drive the bus until `app_main` runs (SESP-3). On v1, no secure boot, no flash encryption, no `DIS_DOWNLOAD_MODE`, no `DIS_USB_SERIAL_JTAG`: each would
  remove a recovery path.
- **GTi compatibility:** from the GTi's side FluxDrive is a dongle-class device, with the same ESP-NOW protocol and
  the same pairing gesture as the GTi SuperMini dongle (hold BOOT 5 s to pair, 15 s to wipe).

## 10. Cost

Estimate from the PCB review (JLC economic assembly: $8.18 setup, $1.53 stencil, $3.07 per extended part), with
about €1 per board (5–10 boards) or €0.5 (50) for 4 layers instead of 2 (layout review; to check in JLC's
calculator at order time), plus the
eFuse added after the power review. Parts at JLC's price tier per quantity, PCB price estimated, 1 EUR = 1.15 USD,
shipping, VAT and customs excluded. LCSC numbers and prices are fixed in the plan.

- Extended parts (8): module, 74LVC14A, 74LVC07A, eFuse, buck, inductor, USB-C, USBLC6. About $24.6 per order.
- Through-hole parts (34-way header or socket, power header): hand-soldered, about $0.40 per board.

| Quantity | Per board |
|---|---|
| 5 | ≈ €15 |
| 10 | ≈ €12 |
| 50 | ≈ €8 |

The WROOM-1U variant adds about €1.5–2 per board (module plus antenna and pigtail).

Main parts (review suggestions, to be re-checked in JLC's BOM tool):

| Function | Part | LCSC |
|---|---|---|
| Module | ESP32-S3-WROOM-1-N16R8 (1U: WROOM-1U-N16R8) | C2913202 (C3013946) |
| Schmitt inverter | SN74LVC14ADR, SOIC-14 (or Nexperia) | C133541 (C6065) |
| Open-drain buffer | 74LVC07AD, SOIC-14 | C6049 (reserve stock before a 50-piece order) |
| eFuse | TPS259531DSGR | C2155674 (single source, about 2,000 in stock: reserve before an order, SPCB-4) |
| Buck | TLV62569DBVR | C141836 |
| Schottky ×2 | SS34 | C8678 |
| USB ESD | USBLC6-2SC6 | C7519 or C2687116 |
| USB-C 16-pin | TYPE-C16PIN (the Nano-Tek part and footprint, placed by JLC before) | C393939 |
| Tactile switch | TS-1187A-B-A-B | C318884 |
| LED | KT-0603R | C2286 |
| Bulk capacitor ×2 | 47 µF 10 V X5R 1206, CL31A476MPHNNNE | C96123 |
| Power header | TE 171825-4, vertical, hand-soldered | C210162 |

## 11. How the design is proven

1. **Netlist tests** on the schematic export, as on the Nano-Tek:
   - every bus pin on the right buffer and direction, with the pull-up of §4.2 on the connector side of the 100 Ω;
   - no pull-up on `/MTR0`; pull-ups on +5V_A, not on V5SYS;
   - every output GPIO in {21, 38–42}, every output buffer input with its 10 kΩ, 33 Ω in series at every output;
   - strapping pins free, GPIO0 with 10 kΩ, no 5 V on a 3.3 V pin;
   - the power path: eFuse before +5V_A, a diode between +5V_A and V5SYS and between VBUS and V5SYS;
   - every gate used in and out of the same gate; the unfitted pads present, between the right nets;
   - the DC levels on USB alone (a resistor-network solve): AMIGA_PWR low, every bus input at a defined level;
   - the tests read a netlist exported fresh from the committed schematic, and fail if that schematic is not what
     the design file generates; ERC on the real schematic at every severity.
2. **ERC and DRC clean**, with JLC's 4-layer rules.
3. **Bench gate** (Mez §8), before the Amiga is involved: flux on a bare dev board for 30 minutes, with ESP-NOW
   flooding. Tight 4/6/8 µs clusters, nothing at buffer boundaries or the wrap point, no gap in the endless
   transmission.
4. **Fit test:** a 1:1 paper template and a printed dummy in the A500, in both connector variants, including the
   overhang direction and the clearance under the shield.
5. **Range test** with a real WROOM-1 board (a SuperMini has a different antenna) inside the closed A500, in both
   connector variants. If it does not reach the GTi, the board is ordered with the WROOM-1U.
6. **Bring-up** in Mez's order (§7 of the input document):
   - power: a reversed plug on a lab supply with current limit; USB alone with the Amiga off (+5V_A about 0.5 V,
     AMIGA_PWR low); hot-plug a 1 m and a 2 m USB-C cable with the Amiga off and scope V5SYS: it must stay below
     6 V, otherwise fit the damper of §5;
   - scope the six outputs through power-up, a RESET press and a flash over USB: no low pulse;
   - bus with firmware halted: all outputs released, so DF0 looks like a drive holding an unreadable disk (not an
     empty drive); the Amiga must still reach the insert-disk screen or boot its next device (SBUS-1). Then inputs
     logged, static outputs, synthetic
     track, one real track, Workbench boot, GTi insert, eject;
   - one hour lid-closed at the module: air temperature below 85 °C.

**v1 is done when:** Workbench 1.3 boots from an ADF sent by the GTi. Ten trackloader games load, among them one
that needs `/RDY` (X-Copy Pro). A disk swap is seen by AmigaDOS. The Amiga boots normally with FluxDrive fitted and
powered but with the firmware halted or unflashed. Fitted without the power cable is not supported (§5).

## 12. Review

Four specialist agents reviewed draft v0.1 on 2026-09-28/29: Amiga floppy bus, power and EMC, ESP32-S3 hardware,
PCB and manufacturing at JLC. Two blockers (the P-FET back-feed, the power-up glitches on the output GPIOs), 16
major findings and the rest minor. All of them are in `docs/reviews/2026-09-29-spec-review.md` with their sources and
decisions. The same four reviews ran again on the schematic (2026-09-29, no blockers, two majors, both fixed:
`docs/reviews/2026-09-29-schematic-review.md`) and run once more on the layout.

## 13. Open items

| # | Item | Decides |
|---|---|---|
| O5 | PCB antenna or U.FL: range test with a WROOM-1 board, both connector variants | module variant |
| O7 | Mounting of the plug-on variant (the printed foot of §8) and a printed dummy in the A500; the outline and the overhang direction are fixed by the paper fit test | mechanics |
| O8 | Write-back policy for v2 (RAM disk, push to GTi, microSD) | nothing in v1 |
| O9 | Licence and where the repo is published (OMEGAWARE / GTi) | publication |
| O12 | Real-drive `/DKRD` and `/INDEX` pulse widths, Paula's `/DKWD` pulse width (the 4.7 kΩ rise of 0.7 µs) | firmware, v2 |
| O13 | Kickstart 1.3/2.x/3.x with a DF0 ID; whether reset clears Gary's motor latch; the A500+ `/MTR0` network | firmware |
| O14 | External DF1 (later): outputs gated by `/SEL` in logic, a hardware motor latch for `MTRXD` | v2 hardware |
| O15 | TE 171825-4: body outline and the pin row's place in it against TE drawing 171825 (the footprint's pads are the right-angle part's, its outline an estimate) | layout |

Closed in review: O1 (Gary latches `/MTR0`), O2 (pull-up values, §4.2), O3 (output GPIOs without a power-up
glitch, §2.3), O4 (buck TLV62569, §5), O6 (GPIO allocation, §4.1 and §6). Closed in the schematic review: O11
(TPS259531 clamp, current limit, pinout and package checked against SLVSE57C; stock see §10).
Closed in the layout review: O10 (the module lies on the board with its antenna 0.5 mm inside the north edge, §6).
Fit test with the paper template (Dimitri, 2026-09-29/30): the board lies over CN11 towards the A500's front, over the
8520 and Gary; 60 mm is the width between CN12 and an electrolytic capacitor; the room under the shield is enough
and the drive's power cable reaches J2 from CN12. O7 keeps only the plug-on mounting and the printed dummy.

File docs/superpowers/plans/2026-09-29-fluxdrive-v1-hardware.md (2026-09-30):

# FluxDrive v1 hardware — implementation plan

> **For agentic workers:** REQUIRED SUB-SKILL: Use superpowers:subagent-driven-development (recommended) or superpowers:executing-plans to implement this plan task-by-task. Steps use checkbox (`- [ ]`) syntax for tracking.

**Goal:** a KiCad 10 project for the FluxDrive v1 board (schematic, 2-layer layout, JLC production files) that meets
the approved spec v0.2, proven by netlist tests, ERC, DRC and two rounds of specialist review.

**Architecture:** the circuit is written once, as data, in `hardware/design.py` (every part, every pin, every
net). `tools/sch_gen.py` turns that into `FluxDrive.kicad_sch`: symbols from KiCad's libraries, a net label on
every pin, no hand-drawn wires. `kicad-cli` exports the netlist; pytest checks it against the spec. The board is
built from that netlist by scripts adapted from the Nano-Tek (`pcb_sync`, placement, Freerouting, a maze router
for leftovers), so it can be rebuilt after every schematic change.

**Tech stack:** KiCad 10.0.6 (`kicad-cli`, its bundled Python with `pcbnew`), Python 3.13 + pytest for the tests,
Java 17 + Freerouting 1.9 (`~/.kicad-mcp/freerouting.jar`, already installed for the Nano-Tek), git with
`core.autocrlf=false`.

**Spec:** `docs/superpowers/specs/2026-09-28-fluxdrive-v1-hardware-design.md` (v0.2, approved by Dimitri on
2026-09-29). Review record: `docs/reviews/2026-09-29-spec-review.md`.

## Global constraints

- ESP32-S3-WROOM-1-N16R8 exactly (LCSC C2913202); the WROOM-1U-N16R8 (C3013946) is the same footprint.
- Bus outputs only on GPIO21 and GPIO38–42. GPIO18, 3, 12, 45, 46 and 35–37 unconnected.
- Inputs: connector → pull-up node → 100 Ω → 74LVC14A, 100 kΩ from the LVC14A input to +3.3 V.
- Pull-ups to **+5V_A**: 1 kΩ `/STEP` `/DIR` `/SIDE` `/SEL0`; 4.7 kΩ `/DKWD` `/DKWE`; 10 kΩ `/SEL1`; none fitted on `/MTR0` (pins 4, 16).
- Outputs: 74LVC07A, 10 kΩ to +3.3 V on every buffer input, 33 Ω in series at every output.
- Power: TE 171825-4 (vertical; was 171826-4 before the schematic review) → TPS259531 eFuse (5.7 V clamp) → +5V_A → SS34 → V5SYS; VBUS → USBLC6-2SC6 → SS34 → V5SYS; V5SYS ≤ 10 µF; TLV62569 buck, 2.2 µH, to +3V3. No P-FET.
- AMIGA_PWR: 1 kΩ / 1.5 kΩ from +5V_A to GPIO1 (10 kΩ / 15 kΩ before the schematic review, SESP-1).
- GPIO0: 10 kΩ pull-up, no capacitor. EN: 10 kΩ pull-up, 1 µF.
- Board: 2 layers, 1.6 mm, ≥ 56 mm along the connector, about 45 mm deep; all SMD on top, assembled by JLC; every through-hole part hand-soldered by Dimitri.
- Rules: tracks 0.2/0.2 mm (0.15 mm at the module), power 0.4 mm, vias 0.3/0.6 mm, copper ≥ 0.3 mm from the edge.
- Antenna end of the module over the north edge, keep-out on all layers, 15 mm clearance from housing metal (fit test).
- Silkscreen: pin-1 triangle and edge mark for the 34-pin connector on both sides, "FluxDrive v1 rev A", "by Dimmy (Dimitri Hilverda)".
- Git: commit with `git -c core.autocrlf=false`, never push. No AI attribution in commits (no `Co-Authored-By`), per Dimitri's global rules.

## Review focus

Failure modes the spec implies that no single task's main tests would catch; each has a test in the task named.

1. **A reversed power plug** (+12 V on pin 1): EN of the eFuse stays below 7 V and the eFuse is the only way from
   J2 to the board. Test `test_efuse_survives_12v` (task 5).
2. **USB alone on the bench with the Amiga off:** nothing from VBUS/V5SYS/+3V3 reaches +5V_A or a connector pin
   except through a reverse-biased diode or ≥ 100 kΩ. Test `test_no_backfeed_paths` (task 5).
3. **The ESP32 restarting while the Amiga runs:** every bus output GPIO is glitch-free and every buffer input has
   its 10 kΩ pull-up, so no output moves. Test `test_outputs_quiet_at_power_up` (task 4).
4. **A plug-on socket fitted rotated or a row off:** pin-1 marks on both silkscreen layers and the even row facing
   inward. Test `test_pin1_marked_both_sides` (task 10).
5. **Hand-soldering the connectors after JLC assembly:** no SMD part inside the 54 × 10 mm connector zone on top,
   and the power header next to the 34-pin connector. Test `test_connector_zone_free` (task 10).

---

## File structure

| Path | Responsibility |
|---|---|
| `hardware/design.py` | The circuit as data: `PARTS` (ref, symbol, value, footprint, LCSC, pin→net, block, dnp), `BLOCKS`, `PWR_FLAGS`. Single source of truth. |
| `tools/sexpr.py` | S-expression parser/writer that keeps quoted strings (KiCad files). |
| `tools/sch_gen.py` | `design.py` → `FluxDrive.kicad_sch`. |
| `tools/netlist.py` | Netlist reader (copied from Nano-Tek `2623d2f`, plus DNP awareness). |
| `tools/export_netlist.sh` | `kicad-cli` netlist export to `build/FluxDrive.net`. |
| `FluxDrive.kicad_sym`, `FluxDrive.pretty/` | Project symbols (TPS259531, TYPE-C16PIN, 171825-4) and footprints (USB-C, 171825-4). |
| `FluxDrive.kicad_pro`, `sym-lib-table`, `fp-lib-table` | KiCad project. |
| `tests/fd.py`, `tests/conftest.py` | Test helpers and the netlist fixture. |
| `tests/test_bus.py`, `test_power.py`, `test_esp.py`, `test_bom.py`, `test_sch_gen.py`, `test_pcb.py` | Spec checks. |
| `tools/pcb_sync.py`, `pcb_place.py`, `pcb_route.py`, `pcb_ripup.py`, `pcb_maze.py`, `pcb_autoroute.py`, `pcb_silk.py`, `pcb_build.sh` | Board from netlist (adapted Nano-Tek tools). |
| `tools/jlc_export.py`, `tools/jlc_production.sh` | BOM/CPL/gerbers (copied from Nano-Tek `2623d2f`). |
| `mech/fit_template.pdf` | 1:1 paper template for the fit test. |

---

### Task 1: Test tooling and project skeleton

**Files:**
- Create: `tools/__init__.py`, `tools/netlist.py`, `tools/sexpr.py`, `tools/export_netlist.sh`, `tests/__init__.py`, `tests/conftest.py`, `tests/fd.py`, `tests/test_tools.py`, `pytest.ini`, `.gitignore` (append)

**Interfaces:**
- Produces: `tools.sexpr.parse(text) -> list`, `tools.sexpr.dump(node) -> str`, class `tools.sexpr.Q(str)` (quoted atom); `tools.netlist.load(path) -> Netlist` with `.components`, `.nets`, `net_of(ref, pin)`, `net_of_function(ref, name)`, `resistors()`, and `Netlist.fitted(ref) -> bool`; `tests.fd` helpers `pulls(nl, net)`, `between(nl, ref)`, `parts_between(nl, a, b, prefix)`, `esp_net(nl, gpio)`, `RAILS`.

- [ ] **Step 1: copy the netlist reader.** `git -C "C:/Claude projecten/Nano-Tek" show 2623d2f:tools/netlist.py > tools/netlist.py`, then add to `Netlist`:

```python
    def fitted(self, ref):
        """False for parts marked DNP in the schematic (their footprint stays, JLC fits nothing)."""
        f = self.components[ref]["fields"]
        return "dnp" not in f and f.get("DNP", "") not in ("1", "yes")
```
  and make `resistors()` skip parts where `not self.fitted(ref)`.

- [ ] **Step 2: write `tools/sexpr.py`:**

```python
"""S-expressions as KiCad writes them. Quoted strings stay Q (so they are written back quoted)."""
import re

_TOKEN = re.compile(r'\(|\)|"(?:[^"\\]|\\.)*"|[^\s()"]+')

class Q(str):
    """A quoted atom."""

def parse(text):
    stack = [[]]
    for tok in _TOKEN.findall(text):
        if tok == "(":
            stack.append([])
        elif tok == ")":
            done = stack.pop()
            stack[-1].append(done)
        elif tok.startswith('"'):
            stack[-1].append(Q(tok[1:-1].replace('\\"', '"').replace("\\\\", "\\")))
        else:
            stack[-1].append(tok)
    return stack[0][0]

def _atom(a):
    if isinstance(a, Q):
        return '"' + a.replace("\\", "\\\\").replace('"', '\\"') + '"'
    if isinstance(a, float):
        return f"{a:.4f}".rstrip("0").rstrip(".") if a != int(a) else str(int(a))
    return str(a)

def dump(node, depth=0):
    """KiCad style: one child list per line, tab-indented; short atom lists stay on one line."""
    if not isinstance(node, list):
        return _atom(node)
    atoms = [x for x in node if not isinstance(x, list)]
    kids = [x for x in node if isinstance(x, list)]
    head = "(" + " ".join(_atom(a) for a in atoms)
    if not kids:
        return head + ")"
    inner = "\n".join("\t" * (depth + 1) + dump(k, depth + 1) for k in kids)
    return head + "\n" + inner + "\n" + "\t" * depth + ")"

def child(node, name):
    return next((c for c in node[1:] if isinstance(c, list) and c and c[0] == name), None)

def children(node, name):
    return [c for c in node[1:] if isinstance(c, list) and c and c[0] == name]
```

- [ ] **Step 3: write `tests/test_tools.py`** (fails until steps 1–2 exist):

```python
from tools import sexpr
from tools.netlist import parse_ohms

def test_sexpr_round_trip_keeps_quotes():
    text = '(kicad_sch (version 20260101) (symbol (lib_id "Device:R") (at 1.27 2.54 90)))'
    node = sexpr.parse(text)
    again = sexpr.parse(sexpr.dump(node))
    assert again == node
    assert isinstance(sexpr.child(again, "symbol")[1][1], sexpr.Q)

def test_parse_ohms():
    assert parse_ohms("4K7") == 4700 and parse_ohms("100") == 100 and parse_ohms("2K2") == 2200
```

- [ ] **Step 4:** `pytest.ini` with `[pytest]` / `pythonpath = .`; `tests/conftest.py`:

```python
import os
import pathlib

import pytest

from tools import netlist

ROOT = pathlib.Path(__file__).resolve().parents[1]

@pytest.fixture(scope="session")
def nl():
    path = pathlib.Path(os.environ.get("FD_NETLIST", ROOT / "build" / "FluxDrive.net"))
    if not path.exists():
        pytest.fail(f"{path} is missing: run  bash tools/export_netlist.sh  first")
    return netlist.load(path)
```

- [ ] **Step 5: `tests/fd.py`:**

```python
"""Helpers for the FluxDrive netlist tests."""
RAILS = {"+5V_IN", "+5V_A", "V5SYS", "VBUS", "+3V3", "GND"}

def pulls(nl, net):
    """Sorted [(value, rail)] of fitted resistors between `net` and a rail."""
    out = []
    for ref, a, b, _ in nl.resistors():
        if net in (a, b):
            other = b if a == net else a
            if other in RAILS:
                out.append((nl.components[ref]["value"], other))
    return sorted(out)

def between(nl, ref):
    return {nl.net_of(ref, 1), nl.net_of(ref, 2)}

def parts_between(nl, a, b, prefix="R"):
    """Fitted two-pin parts whose pins are on nets a and b."""
    return sorted(r for r, c in nl.components.items()
                  if r.startswith(prefix) and nl.fitted(r) and between(nl, r) == {a, b})

def esp_net(nl, gpio):
    for name in (f"IO{gpio}", {19: "USB_D-", 20: "USB_D+", 43: "TXD0", 44: "RXD0"}.get(gpio, "")):
        if name:
            net = nl.net_of_function("U1", name)
            if net is not None:
                return net
    raise AssertionError(f"U1 has no pin for GPIO{gpio}")

def is_nc(net):
    return net is None or net.startswith("unconnected-")
```

- [ ] **Step 6:** `tools/export_netlist.sh`:

```bash
#!/usr/bin/env bash
# Generate the schematic from hardware/design.py and export its netlist. Needs KiCad 10.
set -euo pipefail
cd "$(dirname "$0")/.."
KICAD_CLI="${KICAD_CLI:-/c/Program Files/KiCad/10.0/bin/kicad-cli.exe}"
mkdir -p build
python tools/sch_gen.py FluxDrive.kicad_sch
"$KICAD_CLI" sch export netlist --format kicadsexpr -o build/FluxDrive.net FluxDrive.kicad_sch
echo "build/FluxDrive.net written"
```

- [ ] **Step 7:** `python -m pytest -q tests/test_tools.py` → 2 passed. Append `build/`, `*.bak`, `fp-info-cache`, `*-backups/`, `*.lck` to `.gitignore`.
- [ ] **Step 8: commit** "Tools: s-expression and netlist readers, test skeleton".

### Task 2: The schematic generator

**Files:**
- Create: `tools/sch_gen.py`, `tests/test_sch_gen.py`, `tests/fixtures/tiny_design.py`

**Interfaces:**
- Consumes: `tools.sexpr`.
- Produces: `python tools/sch_gen.py OUT.kicad_sch [module]` (default module `hardware.design`); a design module defines `TITLE`, `BLOCKS` (list of block names), `PARTS` (list of dicts: `ref, lib, value, footprint, lcsc, pins, block, dnp, rot, in_bom`), `PWR_FLAGS` (net names). `pins` maps a pin number or a unique pin name to a net name, or to `None` for a no-connect. Every pin of the symbol must appear; `generate()` raises `ValueError` naming the missing pins.

- [ ] **Step 1: tiny test design** `tests/fixtures/tiny_design.py`:

```python
TITLE = "tiny"
BLOCKS = ["A. test"]
PARTS = [
    dict(ref="R1", lib="Device:R", value="10K", footprint="Resistor_SMD:R_0402_1005Metric", lcsc="C25744",
         pins={"1": "+3V3", "2": "SIG"}, block="A. test", dnp=False, rot=90, in_bom=True),
    dict(ref="U1", lib="74xx:74HC14", value="74LVC14A", footprint="Package_SO:SOIC-14_3.9x8.7mm_P1.27mm",
         lcsc="C133541", block="A. test", dnp=False, rot=0, in_bom=True,
         pins={"1": "SIG", "2": "OUT", "3": "GND", "4": None, "5": "GND", "6": None, "9": "GND", "8": None,
               "11": "GND", "10": None, "13": "GND", "12": None, "14": "+3V3", "7": "GND"}),
    dict(ref="R2", lib="Device:R", value="1K", footprint="Resistor_SMD:R_0402_1005Metric", lcsc="C11702",
         pins={"1": "OUT", "2": "GND"}, block="A. test", dnp=False, rot=90, in_bom=True),
]
PWR_FLAGS = ["+3V3", "GND"]
```

- [ ] **Step 2: failing test** `tests/test_sch_gen.py`:

```python
import pathlib
import subprocess

import pytest

from tools import netlist, sch_gen

CLI = r"C:/Program Files/KiCad/10.0/bin/kicad-cli.exe"

def test_tiny_design_round_trips(tmp_path):
    sch = tmp_path / "tiny.kicad_sch"
    sch_gen.main(str(sch), "tests.fixtures.tiny_design")
    net = tmp_path / "tiny.net"
    subprocess.run([CLI, "sch", "export", "netlist", "--format", "kicadsexpr", "-o", str(net), str(sch)], check=True)
    nl = netlist.load(net)
    assert nl.net_of("R1", 2) == "SIG" and nl.net_of("U1", 1) == "SIG"
    assert nl.net_of("U1", 2) == "OUT" and nl.net_of("R2", 1) == "OUT"
    assert nl.net_of("U1", 14) == "+3V3" and nl.net_of("U1", 7) == "GND"
    erc = tmp_path / "erc.txt"
    r = subprocess.run([CLI, "sch", "erc", "--severity-error", "--exit-code-violations", "-o", str(erc), str(sch)])
    assert r.returncode == 0, erc.read_text()

def test_missing_pin_is_an_error():
    import copy
    import tests.fixtures.tiny_design as d
    parts = copy.deepcopy(d.PARTS)
    del parts[1]["pins"]["12"]
    with pytest.raises(ValueError, match="U1.*12"):
        sch_gen.generate("t", ["A. test"], parts, [])
```
  Run `python -m pytest -q tests/test_sch_gen.py` → FAIL (no module `sch_gen`).

- [ ] **Step 3: write `tools/sch_gen.py`:**

```python
"""Draw a KiCad 10 schematic from a design module (a netlist written as data).

    python tools/sch_gen.py FluxDrive.kicad_sch [hardware.design]

Each part is placed once per unit, in rows per block. Every pin gets a local net label at its end point,
or a no-connect flag. Symbols are copied from KiCad's libraries (or FluxDrive.kicad_sym) into lib_symbols,
so the file is self-contained. It is a readable netlist, not a drawn circuit: the circuit lives in the
design module, and the tests check the exported netlist.
"""
import copy
import importlib
import math
import pathlib
import sys
import uuid

ROOT = pathlib.Path(__file__).resolve().parents[1]
sys.path.insert(0, str(ROOT))
from tools.sexpr import Q, child, children, dump, parse  # noqa: E402

KICAD_SYM = pathlib.Path(r"C:/Program Files/KiCad/10.0/share/kicad/symbols")
LOCAL_SYM = ROOT / "FluxDrive.kicad_sym"
G = 1.27
PAGE_W, MARGIN, ROW_GAP = 560.0, 20.0, 12.7
_libs = {}

def uid():
    return Q(str(uuid.uuid4()))

def snap(v):
    return round(round(v / G) * G, 4)

def _lib(name):
    if name not in _libs:
        path = LOCAL_SYM if name == "FluxDrive" else KICAD_SYM / f"{name}.kicad_sym"
        root = parse(path.read_text(encoding="utf-8"))
        _libs[name] = {s[1]: s for s in children(root, "symbol")}
    return _libs[name]

def lib_symbol(lib_id):
    """The library symbol, flattened (extends resolved) and renamed to lib_id, as lib_symbols wants it."""
    lib, name = lib_id.split(":", 1)
    syms = _lib(lib)
    sym = copy.deepcopy(syms[name])
    while child(sym, "extends"):
        parent_name = child(sym, "extends")[1]
        parent = copy.deepcopy(syms[parent_name])
        props = [c for c in sym[2:] if isinstance(c, list) and c[0] == "property"]
        head = [c for c in parent[2:] if not (isinstance(c, list) and c[0] in ("property", "symbol", "extends"))]
        subs = [c for c in parent[2:] if isinstance(c, list) and c[0] == "symbol"]
        for s in subs:
            s[1] = Q(name + s[1][len(parent_name):])
        sym = [sym[0], sym[1], *head, *props, *subs]
    sym[1] = Q(lib_id)
    return sym

def pins_of(sym):
    """{unit: [(number, name, x, y, angle)]}; unit 0 pins belong to every unit. Body style 2 is skipped."""
    base = sym[1].split(":", 1)[1]
    out = {}
    for s in children(sym, "symbol"):
        unit, style = (int(v) for v in s[1][len(base) + 1:].split("_"))
        if style == 2:
            continue
        for p in children(s, "pin"):
            at = child(p, "at")
            out.setdefault(unit, []).append((str(child(p, "number")[1]), str(child(p, "name")[1]),
                                             float(at[1]), float(at[2]), int(float(at[3])) if len(at) > 3 else 0))
    return out

def place(px, py, rot):
    """Symbol coordinates (y up) -> offset on the sheet (y down), for a rotation of rot degrees."""
    x, y = px, -py
    r = math.radians(rot)
    return (x * math.cos(r) + y * math.sin(r), -x * math.sin(r) + y * math.cos(r))

def resolve(ref, pins, allpins):
    """Map the design's keys (pin number or unique pin name) to pin numbers; every pin must be covered."""
    numbers = {n for n, *_ in allpins}
    by_name = {}
    for n, name, *_ in allpins:
        by_name.setdefault(name, set()).add(n)
    out = {}
    for key, net in pins.items():
        key = str(key)
        if key in numbers:
            out[key] = net
        elif len(by_name.get(key, ())) == 1:
            out[next(iter(by_name[key]))] = net
        else:
            raise ValueError(f"{ref}: pin {key!r} is not a pin number or a unique pin name")
    missing = sorted(numbers - set(out), key=lambda s: (len(s), s))
    if missing:
        raise ValueError(f"{ref}: pins not in the design: {', '.join(missing)}")
    return out

def prop(name, value, x, y, hide=False, angle=0):
    p = [ "property", Q(name), Q(value), ["at", snap(x), snap(y), angle],
          ["effects", ["font", ["size", 1.27, 1.27]]]]
    if hide:
        p.insert(4, ["hide", "yes"])
    return p

def label(net, x, y, pin_angle):
    ang = {0: 180, 180: 0, 90: 270, 270: 90}[pin_angle % 360]
    just = "right" if ang in (180, 270) else "left"
    return ["label", Q(net), ["at", snap(x), snap(y), ang],
            ["effects", ["font", ["size", 1.27, 1.27]], ["justify", just, "bottom"]], ["uuid", uid()]]

def instance(p, unit, pins, at, root_uuid, project):
    x, y = at
    sym = ["symbol", ["lib_id", Q(p["lib"])], ["at", x, y, p.get("rot", 0)], ["unit", unit],
           ["body_style", 1], ["exclude_from_sim", "no"], ["in_bom", "yes" if p.get("in_bom", True) else "no"],
           ["on_board", "yes" if p.get("on_board", True) else "no"], ["in_pos_files", "yes"],
           ["dnp", "yes" if p.get("dnp") else "no"], ["uuid", uid()],
           prop("Reference", p["ref"], x, y - 5.08), prop("Value", p["value"], x, y + 5.08),
           prop("Footprint", p.get("footprint", ""), x, y, hide=True),
           prop("Datasheet", "", x, y, hide=True)]
    if p.get("lcsc"):
        sym.append(prop("LCSC", p["lcsc"], x, y, hide=True))
    for n in sorted({pin[0] for pin in pins}, key=lambda s: (len(s), s)):     # this unit's pins only
        sym.append(["pin", Q(n), ["uuid", uid()]])
    sym.append(["instances", ["project", Q(project), ["path", Q("/" + root_uuid),
                                                       ["reference", Q(p["ref"])], ["unit", unit]]]])
    return sym

def extent(pins, rot, nets):
    """(x0, y0, x1, y1) of pins plus room for their labels, around the symbol origin."""
    xs, ys = [0.0], [0.0]
    for n, _, px, py, a in pins:
        dx, dy = place(px, py, rot)
        room = 2.0 + 1.0 * len(nets.get(n) or "")
        ang = (a + rot) % 360
        xs += [dx - room if ang == 0 else dx, dx + room if ang == 180 else dx]
        ys += [dy + room if ang == 90 else dy, dy - room if ang == 270 else dy]
    return min(xs) - 2.54, min(ys) - 6.35, max(xs) + 2.54, max(ys) + 6.35
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

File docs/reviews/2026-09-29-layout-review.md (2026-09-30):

# Review of the v1 layout (commit 91eaca9)

Four specialist reviews of `FluxDrive.kicad_pcb` as it stood after plan task 10 (2 layers, 60 × 48 mm, the module's
antenna 6 mm past the north edge), its build scripts and its tests, done by separate agents on 2026-09-29. None of
them changed a file. This document lists every finding, what was decided and where it went.

| Review | Findings | Blockers |
|---|---|---|
| Amiga floppy bus (LBUS) | 8: 3 major, 4 minor, 1 nit | — |
| Power and EMC (LPWR) | 14: 4 major, 6 minor, 4 nits | — |
| ESP32-S3 and USB (LESP) | 11: 1 major, 4 minor, 6 nits | — |
| Manufacturing at JLC (LPCB) and build scripts (LCODE) | 22: 5 major, 11 minor, 6 nits | — |

Two decisions went to Dimitri, both on 2026-09-29:

1. **4 layers instead of 2.** The bus and power reviews measured the same thing independently: on 2 layers the
   router cut the bottom ground plane into 48 pieces under the buffers and the resistor rows (27 % GND coverage in
   the signal area), and the decoupling capacitors reached their IC's ground pin only over 20–70 mm of copper. The
   board now has In1.Cu as a solid GND plane and In2.Cu as a solid +3V3 plane; F.Cu and B.Cu carry the signals and
   GND pours stitched to In1. Cost: about €1 per board more at 5–10 boards (spec §10).
2. **The antenna on the board.** JLC's economic assembly wants every part inside the outline (LPCB-1). The board
   grows 6.5 mm to the north; the module lies with its antenna end 0.5 mm inside the north edge, over board material
   that is copper-free on all four layers (the module footprint's own keep-out). The envelope in the A500 does not
   change: the fit test (below) was done with the antenna drawn past the old edge.
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

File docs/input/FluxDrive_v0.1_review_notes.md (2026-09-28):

# Review notes — OMEGAWARE FluxDrive HW Design v0.1

**From:** Dimmy's breadboard project (ESP32-S3 Super Mini + 74HCT125, Arduino Core 3.3.7)
**Re:** field-tested findings relevant to §3, §6 and especially the §8 bench gate
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

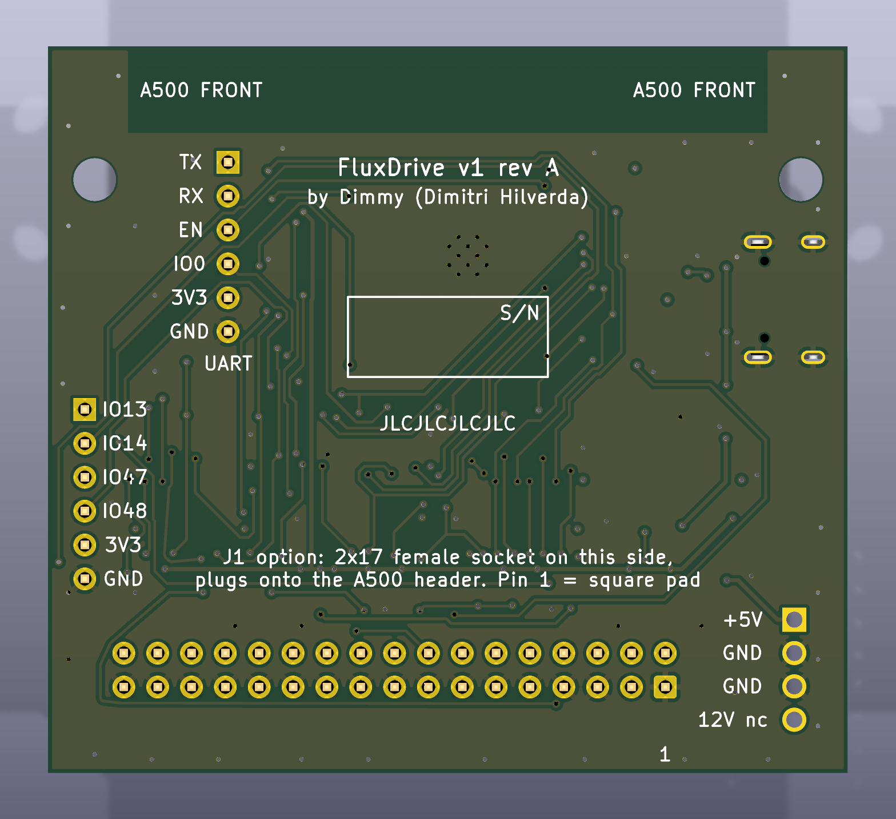
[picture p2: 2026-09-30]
docs/images/fluxdrive-v1-bottom.png

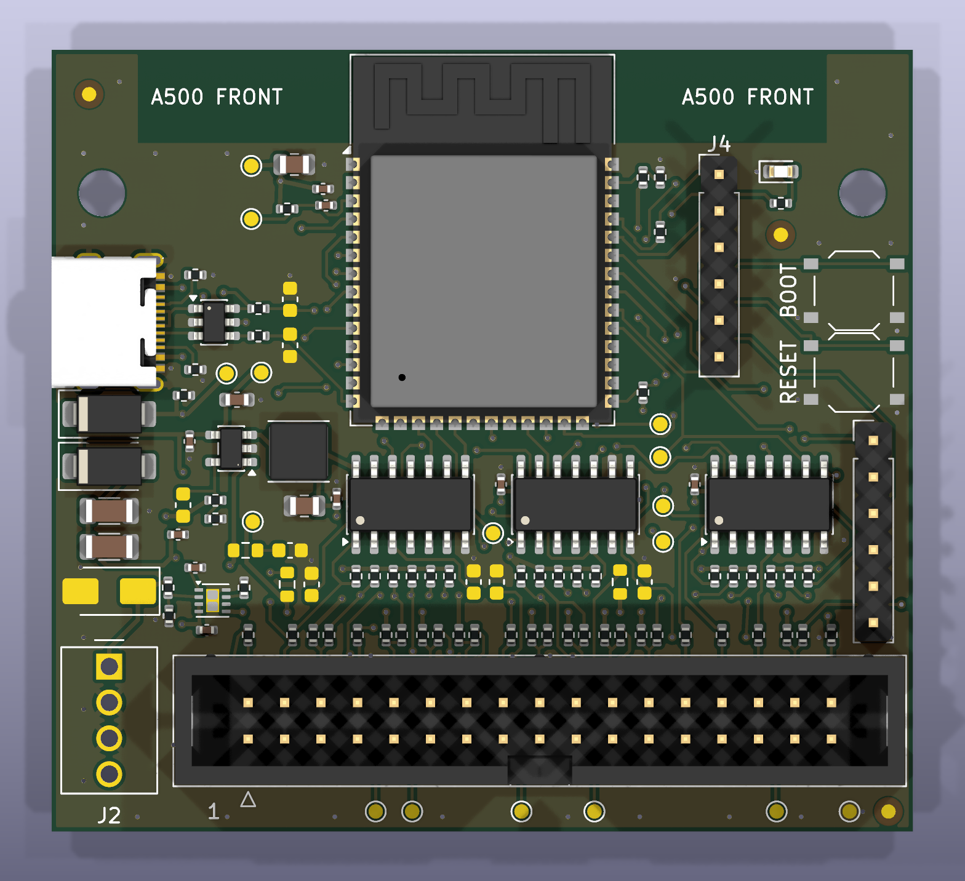
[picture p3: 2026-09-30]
docs/images/fluxdrive-v1-top.png

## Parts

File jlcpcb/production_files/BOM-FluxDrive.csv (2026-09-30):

Comment | Designator | Footprint | LCSC | Quantity
100 | R2,R5,R8,R11,R14,R17,R20,R23,R26,R29,R32 | R_0402_1005Metric | C25076 | 11
100K | R3,R6,R9,R12,R15,R18,R21,R24,R27,R30,R33,R50 | R_0402_1005Metric | C25741 | 12
100nF | C5,C6,C7,C12,C14,C19 | C_0402_1005Metric | C1525 | 6
10K | R13,R28,R31,R34,R36,R38,R40,R42,R44,R46,R54,R55,R58 | R_0402_1005Metric | C25744 | 13
10uF | C13 | C_0603_1608Metric | C19702 | 1
1K | R1,R4,R7,R10,R52,R62 | R_0402_1005Metric | C11702 | 6
1K5 | R53 | R_0402_1005Metric | C25867 | 1
1uF | C8,C20 | C_0402_1005Metric | C52923 | 2
2.2uH | L1 | L_Sunlord_SWPA4020S | C83423 | 1
22 | R59,R60 | R_0402_1005Metric | C25092 | 2
22K | R51 | R_0402_1005Metric | C25768 | 1
22nF | C9 | C_0402_1005Metric | C1532 | 1
22uF | C17,C18 | C_0805_2012Metric | C45783 | 2
2K2 | R48 | R_0402_1005Metric | C25879 | 1
33 | R35,R37,R39,R41,R43,R45 | R_0402_1005Metric | C25105 | 6
470 | R61 | R_0402_1005Metric | C25117 | 1
47uF | C10,C11 | C_1206_3216Metric | C96123 | 2
4K7 | R19,R22,R47 | R_0402_1005Metric | C25900 | 3
5K1 | R56,R57 | R_0402_1005Metric | C25905 | 2
74LVC07A | U4 | SOIC-14_3.9x8.7mm_P1.27mm | C6049 | 1
74LVC14A | U2,U3 | SOIC-14_3.9x8.7mm_P1.27mm | C133541 | 2
BOOT | SW1,SW2 | SW_Push_1P1T_XKB_TS-1187A | C318884 | 2
LED red | D3 | LED_0603_1608Metric | C2286 | 1
SS34 | D1,D2 | D_SMA | C8678 | 2
TLV62569DBVR | U6 | SOT-23-5 | C141836 | 1
TPS259531 | U5 | Texas_DSG0008A_WSON-8-1EP_2x2mm_P0.5mm_EP0.9x1.6mm | C2155674 | 1
USB-C | J3 | USB-C-SMD_TYPE-C16PIN | C393939 | 1
USBLC6-2SC6 | U7 | SOT-23-6 | C2687116 | 1

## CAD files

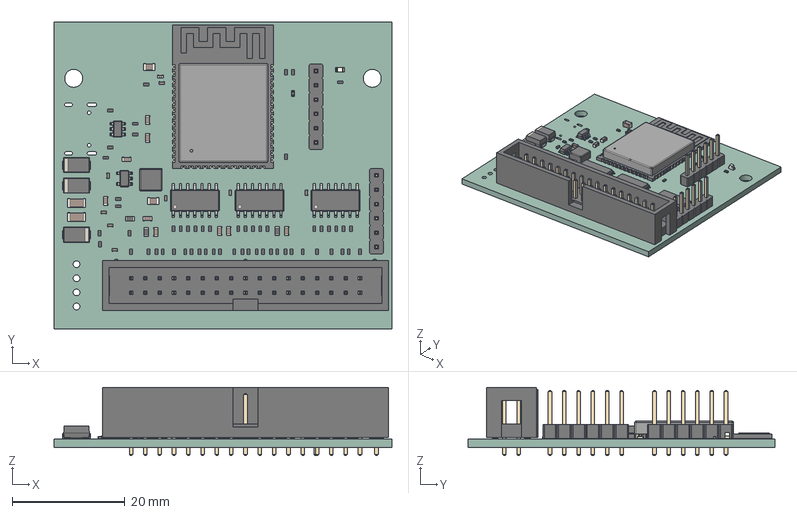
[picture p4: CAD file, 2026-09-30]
mech/FluxDrive.step
60.0 x 54.5 x 12.1 mm
R_0402_1005Metric x 59
LED_0603_1608Metric
SOIC-14_3.9x8.7mm_P1.27mm x 3
SOT-23-5
C_0402_1005Metric x 9
C_0603_1608Metric x 9
IDC_Header_2x17_P254mm_Vertical
SOT-23-6
R_0603_1608Metric x 3
C_0805_2012Metric x 2
D_SMA x 3
ESP32-S3-WROOM-1
C_1206_3216Metric x 2
a671c444-8551-11ed-a139-00155d22e2d7_part
a671c57a-8551-11ed-a139-00155d22e2d7_part
a671c5fc-8551-11ed-a139-00155d22e2d7_part
PinHeader_1x06_P254mm_Vertical x 2
FluxDrive_PCB

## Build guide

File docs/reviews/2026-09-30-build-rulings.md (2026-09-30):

# Rulings made while building v1 (plan tasks 1–12)

The plan `docs/superpowers/plans/2026-09-29-fluxdrive-v1-hardware.md` was carried out task by task. Where the plan
was silent, contradicted the spec or could not work as written, the executor decided and wrote the decision down
as a ruling: what was decided, why, and what it costs if it was wrong. This file keeps all of them, in the order
they were made, together with the minor findings that were deferred. The reviews themselves, with every finding
and its decision, are the other files in this folder.

61 rulings, 9 deferred minor findings.

## Rulings

- T4 <- T6: test_input_chain/test_output_chain need U1 (T6). Ruling: T4 and T5 task-done run only the tests that do not need U1; the full suite runs at T6 — the plan itself notes this red state — cost if wrong: an input/output fault found two tasks later.
- Task 3: Ruling: generator UUIDs made deterministic (uuid5 of a stable key per item) — random UUIDs rewrote the whole schematic and the footprint paths on every regeneration — cost if wrong: none, test_generation_is_deterministic added (it was written after the change, so it never failed first).
- Task 5: Ruling: test_no_backfeed_paths excludes FD_PIN6/FD_PIN14 — the spec (4.2) requires 10k to +3V3 on these NC pins and nothing on the A500 connects to them — cost if wrong: on a host that drives pin 6 or 14 the 10k would feed 3.3 V into it (not a v1 host).
- Task 5: Ruling: feed-forward pad is 6.8 pF (DNP), not the plan's 10 pF — TLV62569 datasheet SLVSDG1C 8.2.2.2 recommends 6.8 pF with 100k — cost if wrong: none, the pad is unfitted.
- Task 7: Ruling: U4 uses symbol 74xx:74LCX07 instead of 74LS07 — 74LS07 extends 74LCX07 and the flattened copy gave an ERC lib_symbol_mismatch warning; same pinout and open-drain outputs — cost if wrong: none (value and LCSC stay 74LVC07A / C6049).
- Task 7: Ruling: +5V_A has no PWR_FLAG — the eFuse OUT pin is a power output, a flag there is an ERC pin-to-pin error — cost if wrong: none.
- Task 7: Ruling: the generator picks the smallest of A2/A1/A0 that fits (layout() split from generate(), test_everything_fits_on_the_sheet) — at 560 mm fixed width block F fell off the A1 sheet; the design needs A0 — cost if wrong: a large sheet to print; on screen it is fine.
- Task 7: Ruling: AMIGA_PWR divider 1k/1k5 AND firmware ADC reading (SPWR-4 said firmware only, SESP-1 said divider) — hardware low (0.29 V) without relying on firmware, ADC covers Schottky leakage when hot — cost if wrong: 2 mA more from the Amiga's 5 V.
- Task 7: Ruling: J2 is the vertical TE 171825-4 (C210162); footprint pads copied from the right-angle part, body outline estimated (spec O15) — the reviewer's recollection (171825 = right angle) contradicts the JLC listing and the old footprint's own "Horizontal" — cost if wrong: courtyard/silk off by a mm or two; pads and pitch are the family's.
- Task 7: Ruling: right-angle footprint 171826-4 and its STEP model removed from the repo — nothing uses them; they remain in Nano-Tek and in git history — cost if wrong: none.
- Task 7: Ruling: feed-forward pad 15 pF, replacing the Task 5 ruling of 6.8 pF — the 6.8 pF of the datasheet belongs to its 200k/100k divider (SPWR-5) — cost if wrong: none, the pad is unfitted.
- Task 7: Ruling: D4 uses KiCad's Diode:SMAJ13A (pins named A1/A2 by its parent SM6T6V8A, pin 1 = cathode = D_SMA pad 1 with the band) on +5V_IN — cost if wrong: a builder fitting it backwards shorts +5V_IN through the diode; the pad is unfitted and the silk band marks the cathode.
- Task 7: Ruling: spec bumped to v0.3 with the review's corrections, without asking Dimitri first — spec 12 already says the reviews run on the schematic, and every change is traceable in the review record — cost if wrong: Dimitri reverts a wording.
- Task 8: Ruling: board 60 x 48 mm instead of the plan's 56 x 45 — with all SMD on top, the 54 x 10 mm connector zone free and J2 beside J1, 56 x 45 left no room for the power column and the USB-C; spec 8 says "at least 56 mm ... about 45 mm, the final outline follows the layout and the fit test", the plan test allows 40-48 mm — cost if wrong: the fit test (task 10) shows it does not fit, and the outline shrinks again.
- Task 8: Ruling: J1 pin 1 at (113.68, 142.0), module at (130, 106.75), J2 at (104, 136.5) rot 270 beside J1 (same band, pin 1 north) — the plan's coordinates were for 56 x 45; the plan's intent (J1 south, antenna 6 mm past north, J2 at the west end of J1) is kept — cost if wrong: none beyond a re-place.
- Task 8: Ruling: Power netclass 0.3 mm instead of the spec's 0.4 mm — the eFuse (WSON, 0.25 mm pads at 0.5 mm) cannot take a 0.4 mm track with 0.2 mm clearance; 0.3 mm on 1 oz carries the 0.95 A eFuse limit at about 10 C rise (IPC-2221) — cost if wrong: warmer tracks at full current; bring-up measures.
- Task 8: Ruling: netclass patterns get the "/" prefix — the rails are local labels, so the nets are "/GND", "/+3V3"; without it no net was in the Power class — cost if wrong: none.
- Task 8: Ruling: U1 uses a project copy FluxDrive:ESP32-S3-WROOM-1 whose 12 ground-pad thermal vias have 0.3 mm drills instead of 0.2 mm — below the board rule and JLC's 2-layer minimum; the pads stay tented on the bottom (F.Mask only) — cost if wrong: none (0.6 mm pads, 0.15 mm ring).
- Task 8: Ruling: no extra antenna rule area — the module footprint's own keep-out (x +-24 mm, antenna end) ends exactly at the north edge with the antenna 6 mm past it, so no copper on the board can come under the antenna — cost if wrong: none.
- Task 8: Ruling: pcb_place legalises the non-fixed parts (spiral search to the nearest free spot; fixed: J1, U1, J2, J3, buffers, holes, row A) — hand coordinates on this density collided; it prints every part it moves (8 parts, at most 2.1 mm) — cost if wrong: none.
- Task 9: Ruling: GND is not routed as tracks — the DSN keeps the GND net but without pins, so Freerouting treats GND pads as obstacles; GND is the B.Cu plane plus the F.Cu fill, reached through the fan-out vias, the through-hole pins and 34 stitching vias — cost if wrong: none found; DRC shows no unconnected GND.
- Task 9: Ruling: tools/freerouting.rules makes B.Cu four times as expensive as F.Cu and vias dear — without it Freerouting put 1349 mm of track on B.Cu (53 %); with it about 930 mm (38 %), so the bottom plane stays mostly whole (spec 8 asks for an unbroken plane with short crossings; that strict wording is not met, the layout review judges it) — cost if wrong: more plane cuts than a hand layout.
- Task 9: Ruling: B.Cu track keep-out over the J1 pin rows (y 137.4 to 1.2 mm past the odd row) — keeps every GND pin of the 34-way on an unbroken strip of plane; a keep-out down to the south edge left 35 connections open (it took the east-west channel) — cost if wrong: none.
- Task 9: Ruling: placement v3 (after routing trials): buffers 1.2 mm higher, row B at 1.3 mm pitch (one track between two resistors), 2.5 mm between rows A and B for the rails, J5 east of U4, buttons on the east edge, J1 0.45 mm north, connector-side test pads and FID3 in the strip south of J1 between the odd pins, the other test pads out of the module-buffer channel, U7 1 mm east — the first placement left 7 connections open and a wall of resistors — cost if wrong: none, all DRC-checked.
- Task 9: Ruling: tools/pcb_prefan.py pre-routes a USB-C VBUS bridge (stub + via at each VBUS pad, joined on B.Cu under the pad row), locked — joined on F.Cu, VBUS looped round a CC pad and shut it in, in every Freerouting run — cost if wrong: two vias in VBUS.
- Task 9: Ruling: pcb_autoroute runs Freerouting six times in parallel on copies and keeps the best (it varied from 2 to 10 open on the same input), then finishing rounds: maze without rip-up, else Freerouting --continue, undone if not better; one attempt (ATTEMPTS = 1) — the Nano-Tek loop (re-pin, rip all, re-run) took 45 min per attempt and a maze pass with rip-up over all nets cascaded to 14-65 open — cost if wrong: none, the result is DRC-checked.
- Task 9: Ruling: the SES import runs in a fresh process (pcb_route.py --import) — after board.Remove() the pcbnew bindings of that process failed (SwigPyObject has no GetTracks) — cost if wrong: none.
- Task 9: Ruling: the maze router keeps each pad's own clearance (GetOwnClearance), not only the board's — it ran a track 0.2 mm past a fiducial that wants 1 mm — cost if wrong: none.
- Task 9: Ruling: pcb_stitch removes stitching vias that DRC reports unconnected (they joined cut-off pieces of pour, 3 of 37) — cost if wrong: none.
- Task 9: Ruling: min_resolved_spokes 1 instead of 2 — three GND through-hole pins (J1 7 and 15, the USB-C shell) keep only one F.Cu spoke between tracks; each also sits in the B.Cu plane — cost if wrong: a little more heat to the iron on those pins, no electrical effect.
- Task 10: Ruling: most texts on B.SilkS (name and credit, header pin names, serial box, JLC order number, the plug-on socket note) — the top has no free area outside the connector zone; the plan wanted name and credit on F.SilkS, the test accepts either side — cost if wrong: the name is on the back.
- Task 10: Ruling: no "this edge to the front of the A500" mark yet — the direction comes from Dimitri's fit test (plan step 6); the pin-1 "1" on both sides, the J1 footprint's triangle and "Pin 1 = square pad" on the bottom are there — cost if wrong: one silkscreen text to add after the fit test.
- Task 10: Ruling: the 50 mm scale bar is on Dwgs.User, below the outline, and only in the fit-template PDF — on the silkscreen it would be printed on every board — cost if wrong: none.
- Task 10: Ruling: references of passives, test pads, holes, fiducials, buttons, U1, U5-U7, J1, J5 hidden (they stay on F.Fab); U2-U4 on their bodies, J2 below it — 0 silk overlaps — cost if wrong: harder to find a part by eye; the assembly drawing (F.Fab) has them all.
- Task 11: Ruling: LBUS-3 gate re-assignment (U3 takes J1 pins 4-16, U2 pins 18-32, each gate in connector order; spare gate to U2 pin 9 with pin 8 open) — the old order crossed the _B nets (398 mm, 39 vias); test_gate_pairs and test_buffers_follow_the_connector changed with it, the schematic and its PDF regenerated, ERC clean — cost if wrong: none, the logic is the same.
- Task 11: Ruling: the six U4 pull-ups stay in row B (LBUS-4) — with In1 under every route their wrap-around has a reference plane; moving them next to U4 meant a new resistor row in the buffer channel — cost if wrong: about 10 mm more track on six open-drain lines.
- Task 11: Ruling: LESP-2 kept, the module stays centred on the north edge — Espressif prefers a corner, but that redoes the whole placement; the range test (O5) decides, the WROOM-1U is the fallback — cost if wrong: less radio range in the closed A500.
- Task 11: Ruling: the USB-C shell keeps its 0.18 mm past the west edge (LPCB-1) — a receptacle has to reach the edge for the plug; the Nano-Tek, assembled by JLC, has the same placement — cost if wrong: JLC's preview asks to move it 0.2 mm.
- Task 11: Ruling: library footprints keep their 0.12 mm silk lines (LPCB-4 asked for text height only) and J3's 0.34 mm peg-to-slot gap stays (LPCB-12, the Nano-Tek footprint) — cost if wrong: a JLC DFM remark at order time.
- Task 11: Ruling: DSN planes: /GND and /+3V3 go to Freerouting as LT_POWER planes on In1/In2 and the outer pours are left out of the export copy; vias are exported 0.68 mm (so Freerouting keeps 0.58 mm between holes) and shrunk back to 0.6 mm on import — the Nano-Tek method; with the pours in, Freerouting routed around islands — cost if wrong: none, DRC checks the result.
- Task 11: Ruling: pcb_prefan pre-routes, locked, besides the VBUS bridge: the +5V_A rail on B.Cu between rows A and B (router left +5V_A open), the nine eFuse tracks (router left EN or ILM open), and the USB D+/D- pad joins at the receptacle (D+ round the west end of A7 in the 0.64 mm strip in front of the USB-C body area, D- round the east end of A6; build 9 left A7 open) — test_usb_data_pads_joined_on_top RED on build 9 — cost if wrong: hand routes to redo if the placement there moves.
- Task 11: Ruling: U5 (eFuse) and its parts moved west beside D4/J2 (U5 at 111.2, 131.9), C13 to (112.9, 117.9), TP11 to (114.0, 126.4) — the legaliser had pushed C13 into the VBUS corridor and TP11 had no room — cost if wrong: none, DRC-checked.
- Task 11: Ruling: the finishing rounds after the six Freerouting runs use Freerouting --continue (100 passes) when the maze router without rip-up leaves nets open; a round that is not better is undone — the maze router with rip-up cascaded — cost if wrong: none.
- Task 11: Ruling: pcb_prefan pre-routes /DKRD_D (U4 pin 4 straight down through the widest nearby gap in row B to R35, 6.4 mm, no via), locked — the fan-out chained row B's +3V3 pull-up pads on F.Cu across that gap (no room for a via between the 0402s and U4) and the router took /DKRD_D 19.9 mm round the row with two vias; test_dkrd_short_and_on_one_layer RED on build 10 — cost if wrong: none, DRC-checked.
- Task 11: Ruling: pcb_stitch keeps each pad's own clearance (GetOwnClearance, as pcb_maze) — build 10 put a stitching via 0.44 mm from FID1, which asks 0.6 mm; reproduced by removing the via and re-stitching (3 DRC errors), 0 after the fix — cost if wrong: none.
- Task 11: Ruling: the three _B detours stay for rev A (SIDE_B 111 mm on B.Cu under the module, PIN14_B 71 mm, DKWD_B 67 mm / 7 vias; all 11 _B nets 420 mm / 34 vias against 398 / 39 before LBUS-3's fix) — the row A-B channel is full (the +5V_A rail and INDEX_D on B.Cu, SIDE crossing U4's three outputs); with the rest in place Freerouting --continue and the maze router found no path at all; a better result needs a placement change (INDEX/CHNG from the west end), and all of them run over a plane at open-collector edge rates; written into the review record — cost if wrong: more crosstalk on DKWD than a hand layout; bring-up scopes DKWD.
- Task 11: Ruling: the silkscreen warnings stay (SW1/SW2 outlines touch, D2/D4 outlines against J3/R46, J4's reference on its outline, J3's outline past the edge) — library outlines, JLC clips silk on pads and off the board, moving parts means a new route — cost if wrong: a thicker silk line between the buttons.
- Task 11: Ruling: fit_template.sh accepts kicad-cli's exit 2 for the STEP when the only error is the USB-C's VRML-only model (the buttons and the eFuse have no KiCad 10 model either; none is taller than 3.3 mm) — cost if wrong: the printed dummy lacks those three low parts.
- Task 12: Ruling: order settings say 4 layers, not the plan's 2 — Dimitri's 4-layer decision in the layout review (spec v0.4) — cost if wrong: none.
- Task 12: Ruling: SOIC gets rotation correction 0 in tools/jlc_export.py, not the plan's 270 (the old JLCPCB Tools default) — KiCad's SOIC and TSSOP share the pin-1 orientation, and the Nano-Tek Rev 1.2 CPL that JLC assembled used 0 for its TSSOP; the README puts U2-U4 first on the placement-preview list and names the 270 alternative — cost if wrong: three ICs shown turned 90 degrees in JLC's preview, fixed there before paying.
- Task 12: Ruling: J4 and J5 (1x6 2.54 mm headers, optional) are listed without an LCSC number — the design gives them none and any header fits; J1 C601943 and J2 C210162 are listed — cost if wrong: none.
- Task 12: Ruling: test_production_files_match_the_board added (not in the plan) — the CPL is made from the board and goes stale after a rebuild (the LCODE-1 failure mode); RED against a CPL made from the task-9 board (25 mismatches), GREEN on the current files — cost if wrong: none.
- Final: fixed record/spec claims (LBUS-2 +3V3 vias, LBUS-6 CHNG_D, LPCB-12 0.805 mm, spec §8 grounding, final-review section) — documentation, verified by reading, no test (Ruling: a text fix has no failing test to write).
- Final: Ruling: the rotation corrections stand (SOIC 0, SOT-23 180, 0 for WSON, SMA and the LED) — they depend on JLC's drawing of each LCSC part; the Nano-Tek Rev 1.2 CPL (TSSOP 0, SOT-23 180) is the only real evidence, and the README's preview list covers every polarity-critical part — cost if wrong: a rotation fixed in JLC's preview before paying.
- Final: Ruling: J3's paste-less shell legs stay as the footprint has them — whether JLC solders them is JLC's process; the README asks to check them on delivery and solder them from the bottom — cost if wrong: four joints by hand.
- Final: Ruling: JLC Economic for 4 layers and edge rails are left to the order form — the README says Standard if Economic is not offered; parts 0.4-0.5 mm from three edges may make JLC add rails — cost if wrong: a few euros for rails or the Standard service.
- Final: Ruling: the module's CPL centre stands (F.Fab body centre, 130.0, 106.75, rotation 0) — whether C2913202's library origin is the body centre shows in JLC's preview, which the README lists for U1 — cost if wrong: a shift corrected in the preview.
- Final: Ruling: TPS259531 exposed pad and pin map not re-judged — schematic scope, checked against SLVSE57C in the schematic review — cost if wrong: none new.
- Final: Ruling: O5 (range test) and O15 (C601943 length, TE 171825-4 outline) stay with Dimitri before ordering — both are in the README's "Before ordering" — cost if wrong: an order with the wrong module variant or a header that overhangs.
- Final: Ruling: no second full build to prove bit-for-bit reproducibility — the installed board is build 12 itself, made by the committed scripts; the fan-out is deterministic (LCODE-2) and Freerouting is on identical input — cost if wrong: a rebuild gives a different, still DRC-gated board.
- Final: Ruling: mech/FluxDrive.step not compared by geometry — tools/fit_template.sh made it from the installed board right after installing it — cost if wrong: none.

## Deferred minor findings

- Task 7: minor (deferred): SPCB-8 test pads 1.0 mm (small for pogo pins) — decide in task 10 where free space is known.
- Task 7: minor (deferred): SCODE-6 tiny test design covers little (rotations, DNP, pin by name, unconnected-).
- Task 7: minor (deferred): SCODE-7 netlist.py does not unescape \, unused p["_numbers"], lib_symbol drops parent-only properties, A0 paper.
- Final: minor (deferred): +3V3 own vias at U2-U4 pin 14 and C17/L1; test_decoupling_reaches_the_planes to cover +3V3 by track path (rev B rebuild).
- Final: minor (deferred): CHNG_D 0.25-0.30 mm along the J1 GND row; keep 0.8 mm in rev B.
- Final: minor (deferred): fit_template.sh accepts any "Could not add 3D model" and a stale STEP; accept only J3/SW1/SW2/U5 and delete the STEP first.
- Final: minor (deferred): tests weaker than their docstrings (antenna: no zones/pads; rule areas: names only; production: R/C positions only, no rotations; buck: to the edge; pin-1 docstring 4 mm vs 6 mm test).
- Final: minor (deferred): sparse GND vias along the east side of the antenna keep-out (spec §6 "dense").
- Final: minor (deferred): empty org.kicad.kicad/ entry in the gerber zip; J3 CPL at pad centre (0.16 mm off origin, harmless); BOM comment "BOOT" for SW1 and SW2.

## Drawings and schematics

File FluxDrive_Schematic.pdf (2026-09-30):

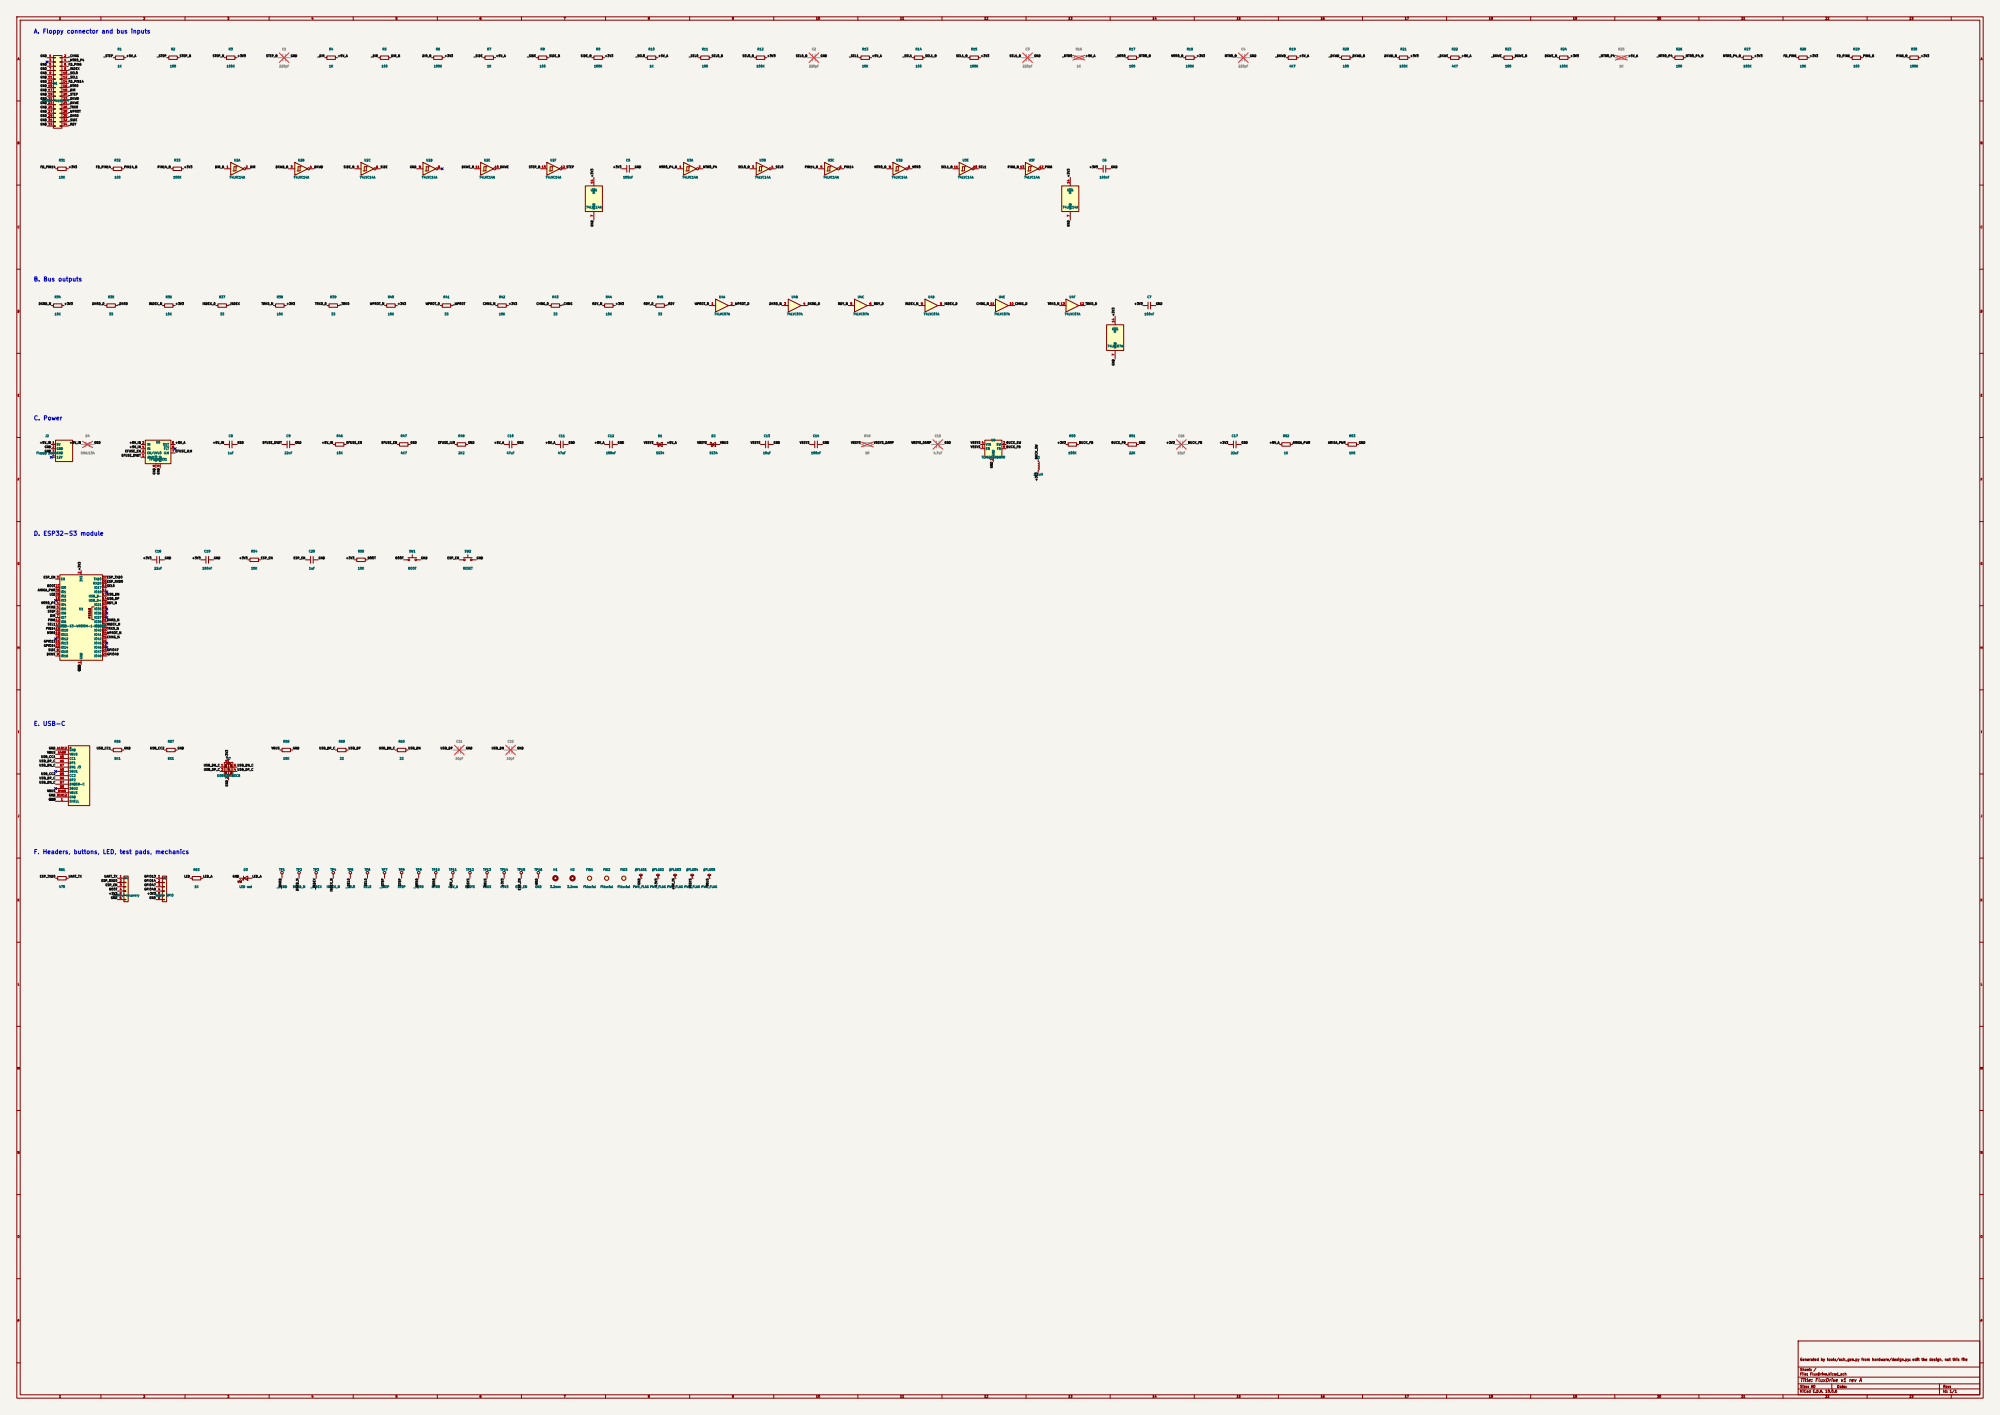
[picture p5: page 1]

A. Floppy connector and bus inputs

F. Headers, buttons, LED, test pads, mechanics

Generated by tools/sch_gen.py from hardware/design.py: edit the design, not this file

Size: A0 | Rev:
KiCad E.D.A. 10.0.6 | Id: 1/1

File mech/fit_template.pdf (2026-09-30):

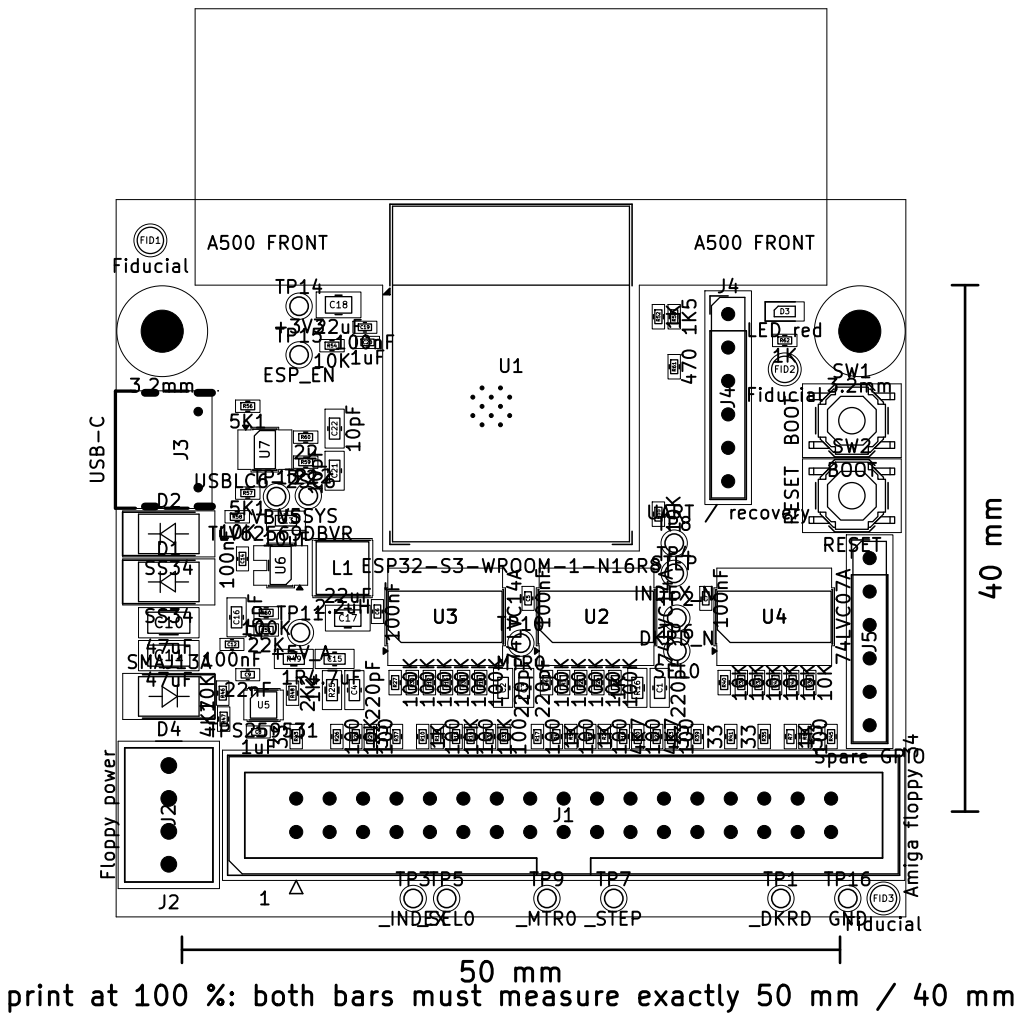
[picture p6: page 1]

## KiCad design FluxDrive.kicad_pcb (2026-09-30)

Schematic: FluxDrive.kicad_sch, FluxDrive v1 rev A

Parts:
C1, C2, C3, C4: 220pF; C_0603_1608Metric; not fitted
C5, C6, C7, C12, C14, C19: 100nF; C_0402_1005Metric; LCSC C1525
C8, C20: 1uF; C_0402_1005Metric; LCSC C52923
C9: 22nF; C_0402_1005Metric; LCSC C1532
C10, C11: 47uF; C_1206_3216Metric; LCSC C96123
C13: 10uF; C_0603_1608Metric; LCSC C19702
C15: 4.7uF; C_0603_1608Metric; not fitted
C16: 15pF; C_0603_1608Metric; not fitted
C17, C18: 22uF; C_0805_2012Metric; LCSC C45783
C21, C22: 10pF; C_0603_1608Metric; not fitted
D1, D2: SS34; D_SMA; LCSC C8678
D3: LED red; LED_0603_1608Metric; LCSC C2286
D4: SMAJ13A; D_SMA; not fitted
FID1, FID2, FID3: Fiducial; Fiducial_1mm_Mask2mm
H1, H2: 3.2mm; MountingHole_3.2mm_M3
J1: Amiga floppy 34; IDC-Header_2x17_P2.54mm_Vertical; LCSC C601943
J2: Floppy power; 171825-4; LCSC C210162
J3: USB-C; USB-C-SMD_TYPE-C16PIN; LCSC C393939
J4: UART / recovery; PinHeader_1x06_P2.54mm_Vertical
J5: Spare GPIO; PinHeader_1x06_P2.54mm_Vertical
L1: 2.2uH; L_Sunlord_SWPA4020S; LCSC C83423
R1, R4, R7, R10, R52, R62: 1K; R_0402_1005Metric; LCSC C11702
R2, R5, R8, R11, R14, R17, R20, R23, R26, R29, R32: 100; R_0402_1005Metric; LCSC C25076
R3, R6, R9, R12, R15, R18, R21, R24, R27, R30, R33, R50: 100K; R_0402_1005Metric; LCSC C25741
R13, R28, R31, R34, R36, R38, R40, R42, R44, R46, R54, R55, R58: 10K; R_0402_1005Metric; LCSC C25744
R16, R25: 1K; R_0603_1608Metric; not fitted
R19, R22, R47: 4K7; R_0402_1005Metric; LCSC C25900
R35, R37, R39, R41, R43, R45: 33; R_0402_1005Metric; LCSC C25105
R48: 2K2; R_0402_1005Metric; LCSC C25879
R49: 1R; R_0603_1608Metric; not fitted
R51: 22K; R_0402_1005Metric; LCSC C25768
R53: 1K5; R_0402_1005Metric; LCSC C25867
R56, R57: 5K1; R_0402_1005Metric; LCSC C25905
R59, R60: 22; R_0402_1005Metric; LCSC C25092
R61: 470; R_0402_1005Metric; LCSC C25117
SW1: BOOT; SW_Push_1P1T_XKB_TS-1187A; LCSC C318884
SW2: RESET; SW_Push_1P1T_XKB_TS-1187A; LCSC C318884
TP1: _DKRD; TestPoint_Pad_D1.0mm
TP2: DKRD_N; TestPoint_Pad_D1.0mm
TP3: _INDEX; TestPoint_Pad_D1.0mm
TP4: INDEX_N; TestPoint_Pad_D1.0mm
TP5: _SEL0; TestPoint_Pad_D1.0mm
TP6: SEL0; TestPoint_Pad_D1.0mm
TP7: _STEP; TestPoint_Pad_D1.0mm
TP8: STEP; TestPoint_Pad_D1.0mm
TP9: _MTR0; TestPoint_Pad_D1.0mm
TP10: MTR0; TestPoint_Pad_D1.0mm
TP11: +5V_A; TestPoint_Pad_D1.0mm
TP12: V5SYS; TestPoint_Pad_D1.0mm
TP13: VBUS; TestPoint_Pad_D1.0mm
TP14: +3V3; TestPoint_Pad_D1.0mm
TP15: ESP_EN; TestPoint_Pad_D1.0mm
TP16: GND; TestPoint_Pad_D1.0mm
U1: ESP32-S3-WROOM-1-N16R8; ESP32-S3-WROOM-1; LCSC C2913202
U2, U3: 74LVC14A; SOIC-14_3.9x8.7mm_P1.27mm; LCSC C133541
U4: 74LVC07A; SOIC-14_3.9x8.7mm_P1.27mm; LCSC C6049
U5: TPS259531; Texas_DSG0008A_WSON-8-1EP_2x2mm_P0.5mm_EP0.9x1.6mm; LCSC C2155674
U6: TLV62569DBVR; SOT-23-5; LCSC C141836
U7: USBLC6-2SC6; SOT-23-6; LCSC C2687116

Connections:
/+3V3: C5.1, C6.1, C7.1, C16.1, C17.1, C18.1, C19.1, J4.5, J5.5, L1.2, R3.2, R6.2, R9.2, R12.2, R15.2, R18.2, R21.2, R24.2, R27.2, R28.2, R30.2, R31.2, R33.2, R34.2, R36.2, R38.2, R40.2, R42.2, R44.2, R50.1, R54.1, R55.1, TP14.1, U1.2 (3V3), U2.14 (VCC), U3.14 (VCC), U4.14 (VCC), U7.5 (VBUS)
/+5V_A: C10.1, C11.1, C12.1, D1.2 (A), R1.2, R4.2, R7.2, R10.2, R13.2, R16.2, R19.2, R22.2, R25.2, R52.1, TP11.1, U5.5 (OUT)
/+5V_IN: C8.1, D4.1 (A1), J2.1 (5V), R46.1, U5.3 (IN), U5.4 (IN)
/AMIGA_PWR: R52.2, R53.1, U1.39 (IO1)
/BOOT: J4.4, R55.2, SW1.1, U1.27 (IO0)
/BUCK_FB: C16.2, R50.2, R51.1, U6.5 (FB)
/BUCK_SW: L1.1, U6.3 (SW)
/CHNG_D: R43.1, U4.10
/CHNG_N: R42.1, U1.35 (IO42), U4.11
/DIR: U1.7 (IO7), U2.2
/DIR_B: R5.2, R6.1, U2.1
/DKRD_D: R35.1, U4.4
/DKRD_N: R34.1, TP2.1, U1.31 (IO38), U4.3
/DKWD: U1.5 (IO5), U2.4
/DKWD_B: R20.2, R21.1, U2.3
/DKWE: U1.9 (IO16), U2.10
/DKWE_B: R23.2, R24.1, U2.11
/EFUSE_DVDT: C9.1, U5.1 (dVdt)
/EFUSE_EN: R46.2, R47.1, U5.2 (EN/UVLO)
/EFUSE_ILM: R48.1, U5.7 (ILM)
/ESP_EN: C20.1, J4.3, R54.2, SW2.1, TP15.1, U1.3 (EN)
/ESP_RXD0: J4.2, U1.36 (RXD0)
/ESP_TXD0: R61.1, U1.37 (TXD0)
/FD_PIN6: J1.6, R28.1, R29.1
/FD_PIN14: J1.14, R31.1, R32.1
/GND: C1.2, C2.2, C3.2, C4.2, C5.2, C6.2, C7.2, C8.2, C9.2, C10.2, C11.2, C12.2, C13.2, C14.2, C15.2, C17.2, C18.2, C19.2, C20.2, C21.2, C22.2, D3.1 (K), D4.2 (A2), J1.1, J1.5, J1.7, J1.9, J1.11, J1.13, J1.15, J1.17, J1.19, J1.21, J1.23, J1.25, J1.27, J1.29, J1.31, J1.33, J2.2 (GND), J2.3 (GND), J3.1 (SHELL), J3.2 (SHELL), J3.3 (SHELL), J3.4 (SHELL), J3.A1B12 (GND), J3.B1A12 (GND), J4.6, J5.6, R47.2, R48.2, R51.2, R53.2, R56.2, R57.2, R58.2, SW1.2, SW2.2, TP16.1, U1.1 (GND), U1.40 (GND), U1.41 (GND), U2.7 (GND), U2.9, U3.7 (GND), U4.7 (GND), U5.8 (GND), U5.9 (PAD), U6.2 (GND), U7.2 (GND)
/GPIO13: J5.1, U1.21 (IO13)
/GPIO14: J5.2, U1.22 (IO14)
/GPIO47: J5.3, U1.24 (IO47)
/GPIO48: J5.4, U1.25 (IO48)
/INDEX_D: R37.1, U4.8
/INDEX_N: R36.1, TP4.1, U1.32 (IO39), U4.9
/LED: R62.1, U1.38 (IO2)
/LED_A: D3.2 (A), R62.2
/MTR0: TP10.1, U1.19 (IO11), U3.8
/MTR0_B: C4.1, R17.2, R18.1, U3.9
/MTR0_P4: U1.4 (IO4), U3.2
/MTR0_P4_B: R26.2, R27.1, U3.1
/PIN6: U1.12 (IO8), U3.12
/PIN6_B: R29.2, R30.1, U3.13
/PIN14: U1.18 (IO10), U3.6
/PIN14_B: R32.2, R33.1, U3.5
/RDY_D: R45.1, U4.6
/RDY_N: R44.1, U1.23 (IO21), U4.5
/SEL0: TP6.1, U1.10 (IO17), U3.4
/SEL0_B: C2.1, R11.2, R12.1, U3.3
/SEL1: U1.17 (IO9), U3.10
/SEL1_B: C3.1, R14.2, R15.1, U3.11
/SIDE: U1.8 (IO15), U2.6
/SIDE_B: R8.2, R9.1, U2.5
/STEP: TP8.1, U1.6 (IO6), U2.12
/STEP_B: C1.1, R2.2, R3.1, U2.13
/TRK0_D: R39.1, U4.12
/TRK0_N: R38.1, U1.33 (IO40), U4.13
/UART_TX: J4.1, R61.2
/USB_CC1: J3.A5 (CC1), R56.1
/USB_CC2: J3.B5 (CC2), R57.1
/USB_DN: C22.1, R60.2, U1.13 (USB_D-)
/USB_DN_C: J3.A7 (DN1), J3.B7 (DN2), R60.1, U7.1 (I/O1), U7.6 (I/O1)
/USB_DP: C21.1, R59.2, U1.14 (USB_D+)
/USB_DP_C: J3.A6 (DP1), J3.B6 (DP2), R59.1, U7.3 (I/O2), U7.4 (I/O2)
/V5SYS: C13.1, C14.1, D1.1 (K), D2.1 (K), R49.1, TP12.1, U6.1 (EN), U6.4 (VIN)
/V5SYS_DAMP: C15.1, R49.2
/VBUS: D2.2 (A), J3.A4B9 (VBUS), J3.B4A9 (VBUS), R58.1, TP13.1
/WPROT_D: R41.1, U4.2
/WPROT_N: R40.1, U1.34 (IO41), U4.1
/_CHNG: J1.2, R43.2
/_DIR: J1.18, R4.1, R5.1
/_DKRD: J1.30, R35.2, TP1.1
/_DKWD: J1.22, R19.1, R20.1
/_DKWE: J1.24, R22.1, R23.1
/_INDEX: J1.8, R37.2, TP3.1
/_MTR0: J1.16, R16.1, R17.1, TP9.1
/_MTR0_P4: J1.4, R25.1, R26.1
/_RDY: J1.34, R45.2
/_SEL0: J1.10, R10.1, R11.1, TP5.1
/_SEL1: J1.12, R13.1, R14.1
/_SIDE: J1.32, R7.1, R8.1
/_STEP: J1.20, R1.1, R2.1, TP7.1
/_TRK0: J1.26, R39.2
/_WPROT: J1.28, R41.2

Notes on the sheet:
A. Floppy connector and bus inputs
B. Bus outputs
C. Power
D. ESP32-S3 module
E. USB-C
F. Headers, buttons, LED, test pads, mechanics

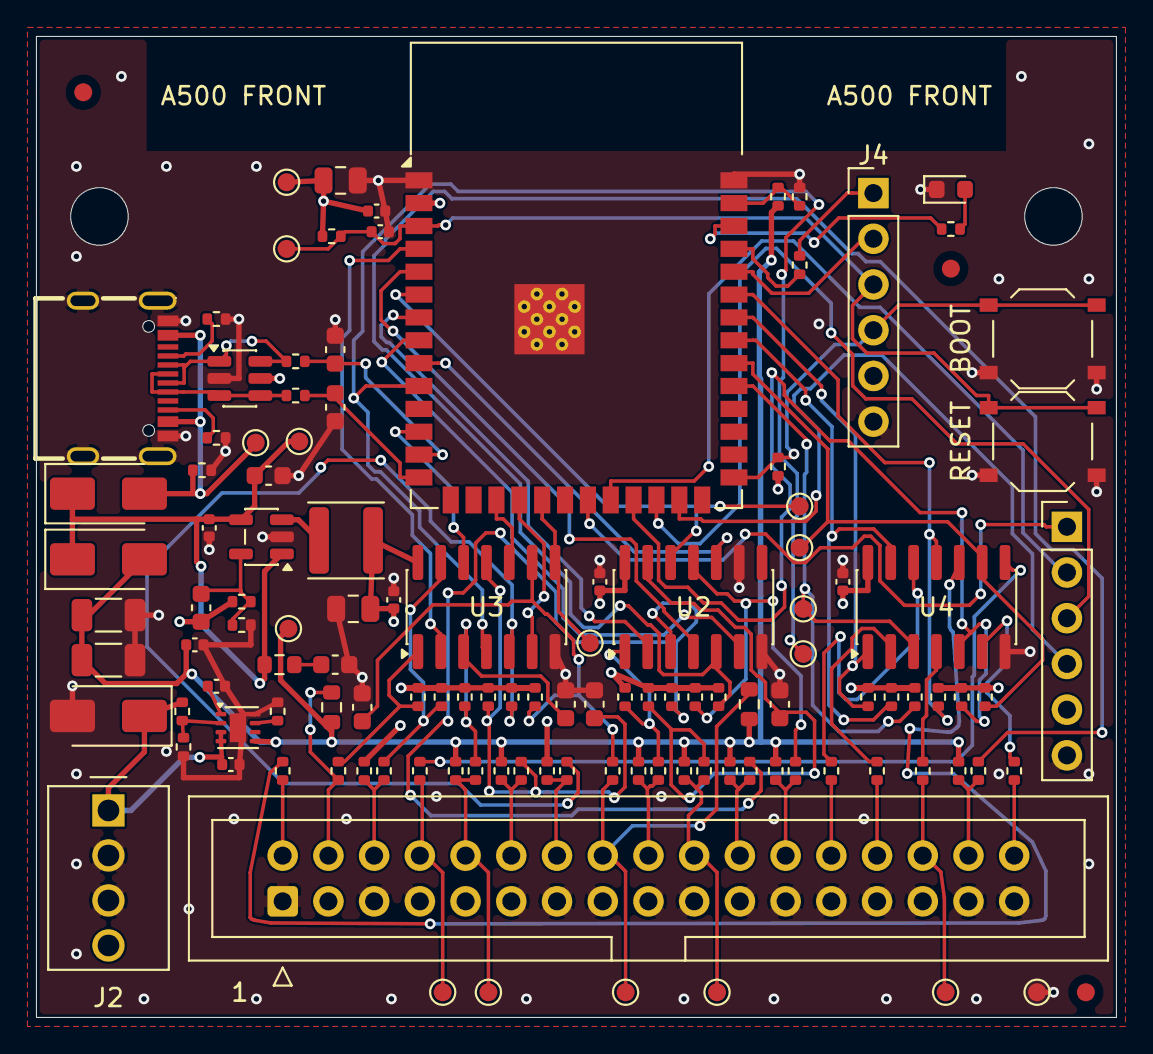
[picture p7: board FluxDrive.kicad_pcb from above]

Board: 4 copper layers, 60.0 x 54.5 mm, 124 parts (0 on the bottom side), 81 nets.

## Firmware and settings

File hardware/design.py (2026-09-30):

"""FluxDrive v1: every part and every pin (spec v0.2). tools/sch_gen.py draws FluxDrive.kicad_sch from this.
The tests read the exported netlist, not this file. Refs are numbered in the order parts are added."""
import itertools

TITLE = "FluxDrive v1 rev A"
BLOCKS = ["A. Floppy connector and bus inputs", "B. Bus outputs", "C. Power", "D. ESP32-S3 module",
          "E. USB-C", "F. Headers, buttons, LED, test pads, mechanics"]
R0402 = "Resistor_SMD:R_0402_1005Metric"
R0603, C0603 = "Resistor_SMD:R_0603_1608Metric", "Capacitor_SMD:C_0603_1608Metric"   # unfitted: hand-solderable
RES_LCSC = {"22": "C25092", "33": "C25105", "100": "C25076", "470": "C25117", "1K": "C11702", "1K5": "C25867",
            "2K2": "C25879",
            "4K7": "C25900", "5K1": "C25905", "10K": "C25744", "15K": "C25756", "22K": "C25768", "100K": "C25741"}
CAPS = {"100nF": ("Capacitor_SMD:C_0402_1005Metric", "C1525"), "1uF": ("Capacitor_SMD:C_0402_1005Metric", "C52923"),
        "22nF": ("Capacitor_SMD:C_0402_1005Metric", "C1532"), "10uF": ("Capacitor_SMD:C_0603_1608Metric", "C19702"),
        "22uF": ("Capacitor_SMD:C_0805_2012Metric", "C45783"), "47uF": ("Capacitor_SMD:C_1206_3216Metric", "C96123")}
PARTS = []
_n = {k: itertools.count(1) for k in ("R", "C", "D", "TP")}
SOIC14 = "Package_SO:SOIC-14_3.9x8.7mm_P1.27mm"


def part(ref, lib, value, footprint, pins, block, lcsc="", dnp=False, rot=0, in_bom=True):
    PARTS.append(dict(ref=ref, lib=lib, value=value, footprint=footprint, pins=pins, block=block,
                      lcsc=lcsc, dnp=dnp, rot=rot, in_bom=in_bom))


def R(value, a, b, block, dnp=False):
    part(f"R{next(_n['R'])}", "Device:R", value, R0603 if dnp else R0402, {"1": a, "2": b}, block,
         "" if dnp else RES_LCSC[value], dnp, rot=90, in_bom=not dnp)


def C(value, a, b, block, dnp=False):
    fp, lcsc = (C0603, "") if dnp else CAPS[value]
    part(f"C{next(_n['C'])}", "Device:C", value, fp, {"1": a, "2": b}, block, "" if dnp else lcsc, dnp,
         rot=90, in_bom=not dnp)


A, B, P, E, U, F = BLOCKS

# --- A: connector and inputs -----------------------------------------------------------------------------
EVEN = {2: "_CHNG", 4: "_MTR0_P4", 6: "FD_PIN6", 8: "_INDEX", 10: "_SEL0", 12: "_SEL1", 14: "FD_PIN14",
        16: "_MTR0", 18: "_DIR", 20: "_STEP", 22: "_DKWD", 24: "_DKWE", 26: "_TRK0", 28: "_WPROT",
        30: "_DKRD", 32: "_SIDE", 34: "_RDY"}
j1 = {str(p): ("GND" if p != 3 else None) for p in range(1, 34, 2)}
j1.update({str(p): n for p, n in EVEN.items()})
part("J1", "Connector_Generic:Conn_02x17_Odd_Even", "Amiga floppy 34", "Connector_IDC:IDC-Header_2x17_P2.54mm_Vertical",
     j1, A, lcsc="C601943")

# signal, connector net, pull-up (value, rail) or None, GPIO, buffer, input pin, output pin, optional C pad.
# U3 (west) takes the lines on J1 pins 4-16, U2 (east) the ones on pins 18-32, each in the connector's
# west-to-east order over the gates (input pins 1, 13, 3, 11, 5, 9 with the SOIC turned 90 degrees on the
# board), so the lines from the connector to the buffers do not cross (layout review LBUS-3).
INPUTS = [
    ("STEP", "_STEP", ("1K", "+5V_A"), 6, "U2", 13, 12, True),        # J1 pin 20
    ("DIR", "_DIR", ("1K", "+5V_A"), 7, "U2", 1, 2, False),           # 18
    ("SIDE", "_SIDE", ("1K", "+5V_A"), 15, "U2", 5, 6, False),        # 32
    ("SEL0", "_SEL0", ("1K", "+5V_A"), 17, "U3", 3, 4, True),         # 10
    ("SEL1", "_SEL1", ("10K", "+5V_A"), 9, "U3", 11, 10, True),       # 12
    ("MTR0", "_MTR0", None, 11, "U3", 9, 8, True),                    # 16
    ("DKWD", "_DKWD", ("4K7", "+5V_A"), 5, "U2", 3, 4, False),        # 22
    ("DKWE", "_DKWE", ("4K7", "+5V_A"), 16, "U2", 11, 10, False),     # 24
    ("MTR0_P4", "_MTR0_P4", None, 4, "U3", 1, 2, False),              # 4
    ("PIN6", "FD_PIN6", ("10K", "+3V3"), 8, "U3", 13, 12, False),     # 6
    ("PIN14", "FD_PIN14", ("10K", "+3V3"), 10, "U3", 5, 6, False),    # 14
]
buf = {"U2": {"14": "+3V3", "7": "GND", "9": "GND", "8": None}, "U3": {"14": "+3V3", "7": "GND"}}
for sig, conn, pull, gpio, u, pin_in, pin_out, cpad in INPUTS:
    if pull:
        R(pull[0], conn, pull[1], A)
    else:
        R("1K", conn, "+5V_A", A, dnp=True)                  # /MTR0: the motherboard has R506 (spec 4.2)
    R("100", conn, f"{sig}_B", A)
    R("100K", f"{sig}_B", "+3V3", A)
    if cpad:
        C("220pF", f"{sig}_B", "GND", A, dnp=True)
    buf[u].update({str(pin_in): f"{sig}_B", str(pin_out): sig})
for u in ("U2", "U3"):
    part(u, "74xx:74HC14", "74LVC14A", SOIC14, buf[u], A, lcsc="C133541")
    C("100nF", "+3V3", "GND", A)

# --- B: outputs --------------------------------------------------------------------------------------------
# signal, connector net, GPIO, U4 input pin, output pin. The gates whose output faces the connector (the
# bottom row with the SOIC turned 90 degrees: 2, 4, 6) take /WPROT, /DKRD and /RDY in the connector's order,
# so /DKRD runs straight down to its 33 ohm; /TRK0, /CHNG and /INDEX go the long way anyway (layout review LBUS-4).
OUTPUTS = [("DKRD", "_DKRD", 38, 3, 4), ("INDEX", "_INDEX", 39, 9, 8), ("TRK0", "_TRK0", 40, 13, 12),
           ("WPROT", "_WPROT", 41, 1, 2), ("CHNG", "_CHNG", 42, 11, 10), ("RDY", "_RDY", 21, 5, 6)]
u4 = {"14": "+3V3", "7": "GND"}
for sig, conn, gpio, pin_in, pin_out in OUTPUTS:
    R("10K", f"{sig}_N", "+3V3", B)
    R("33", f"{sig}_D", conn, B)
    u4.update({str(pin_in): f"{sig}_N", str(pin_out): f"{sig}_D"})
part("U4", "74xx:74LCX07", "74LVC07A", SOIC14, u4, B, lcsc="C6049")     # same pinout and open-drain outputs
C("100nF", "+3V3", "GND", B)
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

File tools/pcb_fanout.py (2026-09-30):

"""Fan out the SMD pads of the plane nets (GND -> In1.Cu, +3V3 -> In2.Cu) with a short track and a via.

    "/c/Program Files/KiCad/10.0/bin/python.exe" tools/pcb_fanout.py FluxDrive.kicad_pcb

Adapted from the Nano-Tek tool (2623d2f). Changes after the FluxDrive layout review:
- a via never touches a pad, its own included (LCODE-4: solder would drain into it): the search starts
  outside the pad, and every pad's copper counts as an obstacle for the via ring (other nets with the
  clearance, the same net with a mask web);
- pads are handled in reference order (LCODE-2: the file order depended on footprint IDs);
- the board edge comes from Edge.Cuts;
- stubs and vias stay out of the rule areas (the module's antenna keep-out, pcb_place's track keep-outs);
- a pad that holds plated holes of its own net (the module's ground pad with its thermal vias) is on the
  plane already and gets nothing.

Run it before Freerouting (which does not fan out to planes itself). Only pads that have no
track attached yet. Pass 1 gives each pad its own via: it tries positions around the pad
(outward first) and takes the first one that keeps clearance to every other copper item on
F.Cu and B.Cu, keeps holes 0.5 mm apart and stays away from the board edge. Pass 2 joins the
pads that had no room (fine-pitch corner pins) to a fanned-out pad or via of the same net with
a straight or L-shaped track. New tracks and vias are locked, so Freerouting keeps them.
"""
import math
import sys

import pcbnew

NETS = ("/GND", "/+3V3")
VIA_D, VIA_DRILL = 0.6, 0.3
TRACK_W = 0.3
CLEARANCE = 0.22          # via to other copper: a bit more than the 0.2 board rule
SEG_CLEARANCE = 0.21      # stubs: the board rule plus a hair
HOLE_GAP = 0.52           # hole edge to hole edge, board rule 0.5 (also between vias of the same net)
EDGE = 0.6                # copper to board edge
WEB = 0.12                # via ring to a pad of its own net: a solder-mask web between them
X0 = X1 = Y0 = Y1 = 0.0   # the board outline, from Edge.Cuts (set in main)
KO_TRACK, KO_VIA = [], []  # outlines of the rule areas that forbid F.Cu tracks / vias (set in main)


def mm(v):
    return pcbnew.FromMM(v)


def has_track(board, pad):
    for t in board.GetTracks():
        if t.GetNetCode() == pad.GetNetCode() and t.GetClass() == "PCB_TRACK":
            if pad.HitTest(t.GetStart()) or pad.HitTest(t.GetEnd()):
                return True
    return False


def obstacles(board, layer, netcode):
    out = []
    for t in board.GetTracks():
        if t.GetNetCode() != netcode and t.IsOnLayer(layer):
            out.append(t.GetEffectiveShape(layer))
    for fp in board.GetFootprints():
        for p in fp.Pads():
            if p.GetNetCode() != netcode and p.IsOnLayer(layer):
                out.append(p.GetEffectiveShape(layer))
    return out


def holes(board):
    hs = [(v.GetPosition(), v.GetDrillValue()) for v in board.GetTracks() if v.GetClass() == "PCB_VIA"]
    for fp in board.GetFootprints():
        for p in fp.Pads():
            if p.HasHole():
                hs.append((p.GetPosition(), max(p.GetDrillSize().x, p.GetDrillSize().y)))
    return hs


def free(pos, seg_from, width, cache, hole_list, own):
    x, y = pcbnew.ToMM(pos.x), pcbnew.ToMM(pos.y)
    if not (X0 + EDGE + VIA_D / 2 < x < X1 - EDGE - VIA_D / 2 and Y0 + EDGE + VIA_D / 2 < y < Y1 - EDGE - VIA_D / 2):
        return False
    for hp, hd in hole_list:
        if (pos - hp).EuclideanNorm() < mm(VIA_DRILL / 2 + pcbnew.ToMM(hd) / 2 + HOLE_GAP):
            return False
    circle = pcbnew.SHAPE_CIRCLE(pos, mm(VIA_D / 2))
    for s in cache[pcbnew.F_Cu] + cache[pcbnew.B_Cu]:
        if s.Collide(circle, mm(CLEARANCE)):
            return False
    if any(s.Collide(circle, mm(WEB)) for s in own):        # its own pad and the other pads of its net
        return False
    if any(z.Collide(circle, 0) for z in KO_VIA):
        return False
    return clear_path([seg_from, pos], width, cache)


def own_pads(board, netcode):
    """Copper of every pad on this net, top and bottom: a via must keep a mask web from all of them."""
    out = []
    for fp in board.GetFootprints():
        for p in fp.Pads():
            if p.GetNetCode() == netcode:
                for layer in (pcbnew.F_Cu, pcbnew.B_Cu):
                    if p.IsOnLayer(layer):
                        out.append(p.GetEffectiveShape(layer))
    return out


def clear_path(points, width, cache):
    """True if an F.Cu track of this width along the points keeps SEG_CLEARANCE to other nets and the edge."""
    for a, b in zip(points, points[1:]):
        for q in (a, b):
            x, y = pcbnew.ToMM(q.x), pcbnew.ToMM(q.y)
            if not (X0 + EDGE < x < X1 - EDGE and Y0 + EDGE < y < Y1 - EDGE):
                return False
        seg = pcbnew.SHAPE_SEGMENT(a, b, mm(width))
        if any(s.Collide(seg, mm(SEG_CLEARANCE)) for s in cache[pcbnew.F_Cu]):
            return False
        if any(z.Collide(seg, 0) for z in KO_TRACK):
            return False
    return True


def stub_width(pad):
    """Never wider than the pad itself, so a stub out of a fine-pitch pin keeps the pin-to-pin gap."""
    s = pad.GetSize(pcbnew.F_Cu)
    return min(TRACK_W, pcbnew.ToMM(min(s.x, s.y)))


def add_track(board, net, points, width):
    for a, b in zip(points, points[1:]):
        tr = pcbnew.PCB_TRACK(board)
        tr.SetStart(a)
        tr.SetEnd(b)
        tr.SetWidth(mm(width))
        tr.SetLayer(pcbnew.F_Cu)
        tr.SetNet(net)
        tr.SetLocked(True)
        board.Add(tr)


def same_net_targets(board, pad, with_pads):
    """Points a stub may end on: vias and F.Cu track ends of the pad's net, and (second pass) SMD pads of
    that net that are already fanned out, e.g. the +3V3 pad of the decoupling cap next to a fine-pitch pin."""
    p, out = pad.GetPosition(), []
    for t in board.GetTracks():
        if t.GetNetCode() != pad.GetNetCode():
            continue
        if t.GetClass() == "PCB_VIA":
            out.append(t.GetPosition())
        elif t.IsOnLayer(pcbnew.F_Cu):
            out += [t.GetStart(), t.GetEnd()]
    if with_pads:
        for fp in board.GetFootprints():
            for q in fp.Pads():
                same = q.GetNetCode() == pad.GetNetCode() and q is not pad
                if same and q.IsOnLayer(pcbnew.F_Cu) and has_track(board, q):
                    out.append(q.GetPosition())
    return sorted((q for q in out if 0 < (q - p).EuclideanNorm() < mm(4.0) and not pad.HitTest(q)),
                  key=lambda q: (q - p).EuclideanNorm())


def candidate_paths(p, q, axis):
    """Straight, then L-shaped, then a short stub along the pad's outward axis followed by an L."""
    V = pcbnew.VECTOR2I
    yield [p, q]
    yield [p, V(q.x, p.y), q]
    yield [p, V(p.x, q.y), q]
    for d in (0.5, 0.8, 1.2):
        m = V(int(p.x + mm(d) * math.cos(axis)), int(p.y + mm(d) * math.sin(axis)))
        yield [p, m, q]
        yield [p, m, V(q.x, m.y), q]
        yield [p, m, V(m.x, q.y), q]


def connect_to_same_net(board, pad, cache, axis, width, with_pads):
    for q in same_net_targets(board, pad, with_pads):
        for pts in candidate_paths(pad.GetPosition(), q, axis):
            pts = [a for i, a in enumerate(pts) if i == 0 or a != pts[i - 1]]
            if clear_path(pts, width, cache):
                add_track(board, pad.GetNet(), pts, width)
                return True
    return False


def place_via(board, pad, cache, axis, width):
    p = pad.GetPosition()
    hole_list = holes(board)
    own = own_pads(board, pad.GetNetCode())
    bb = pad.GetBoundingBox()
    half = pcbnew.ToMM(max(bb.GetWidth(), bb.GetHeight())) / 2       # start outside the pad in every direction
    start = half + VIA_D / 2 + WEB
    for dist in (start + d for d in (0.0, 0.3, 0.6, 1.0, 1.5, 2.1, 2.8, 3.5)):
        for k in (0, 1, -1, 2, -2, 3, -3, 4, 0.5, -0.5, 1.5, -1.5, 2.5, -2.5, 3.5, -3.5, "up", "down"):
            a = -math.pi / 2 if k == "up" else math.pi / 2 if k == "down" else axis + k * math.pi / 4
            q = pcbnew.VECTOR2I(int(p.x + mm(dist) * math.cos(a)), int(p.y + mm(dist) * math.sin(a)))
            if free(q, p, width, cache, hole_list, own):
                via = pcbnew.PCB_VIA(board)
                via.SetPosition(q)
                via.SetWidth(pcbnew.F_Cu, mm(VIA_D))
                via.SetDrill(mm(VIA_DRILL))
                via.SetNet(pad.GetNet())
                via.SetLocked(True)
                board.Add(via)
                add_track(board, pad.GetNet(), [p, q], width)
                return True
    return False


def natural(ref):
    head = ref.rstrip("0123456789")
    return head, int(ref[len(head):] or 0)


def plane_pads(board):
    """SMD pads of the plane nets, in reference and pad order (not file order: see LCODE-2 above)."""
    fps = sorted(board.GetFootprints(), key=lambda f: natural(f.GetReference()))
    for fp in fps:
        holes_here = [q for q in fp.Pads() if q.HasHole()]
        for pad in sorted(fp.Pads(), key=lambda q: (q.GetNumber(), q.GetPosition().x, q.GetPosition().y)):
            if pad.GetNetname() in NETS and not pad.HasHole() and pad.IsOnLayer(pcbnew.F_Cu):
                if any(h.GetNetCode() == pad.GetNetCode() and pad.HitTest(h.GetPosition()) for h in holes_here):
                    continue                                   # on the plane through its own plated holes
                yield fp, pad


def outward_axis(fp, pad):
    """Outward and square to the package side: a diagonal stub would graze the neighbouring pins."""
    c, p = fp.GetPosition(), pad.GetPosition()
    dx, dy = p.x - c.x, p.y - c.y
    return (0.0 if dx >= 0 else math.pi) if abs(dx) >= abs(dy) else (math.pi / 2 if dy >= 0 else -math.pi / 2)


def main(path):
    global X0, X1, Y0, Y1
    board = pcbnew.LoadBoard(path)
    e = board.GetBoardEdgesBoundingBox()
    X0, X1, Y0, Y1 = (pcbnew.ToMM(v) for v in (e.GetLeft(), e.GetRight(), e.GetTop(), e.GetBottom()))
    for z in list(board.Zones()) + [z for fp in board.GetFootprints() for z in fp.Zones()]:
        if z.GetIsRuleArea():
            if z.GetDoNotAllowTracks() and z.IsOnLayer(pcbnew.F_Cu):
                KO_TRACK.append(z.Outline())
            if z.GetDoNotAllowVias():
                KO_VIA.append(z.Outline())
    done, failed = 0, []
    # pass 1: a via of its own (or a straight stub to a nearby via of the same net)
    for fp, pad in plane_pads(board):
        if has_track(board, pad):
            continue
        nc, axis, w = pad.GetNetCode(), outward_axis(fp, pad), stub_width(pad)
        cache = {pcbnew.F_Cu: obstacles(board, pcbnew.F_Cu, nc), pcbnew.B_Cu: obstacles(board, pcbnew.B_Cu, nc)}
        if connect_to_same_net(board, pad, cache, axis, w, False) or place_via(board, pad, cache, axis, w):
            done += 1
        else:
            failed.append((fp, pad))
    # pass 2: no room for a via, so join a neighbour of the same net that has one (straight or L-shaped)
    left = []
    for fp, pad in failed:
        nc, axis, w = pad.GetNetCode(), outward_axis(fp, pad), stub_width(pad)
        cache = {pcbnew.F_Cu: obstacles(board, pcbnew.F_Cu, nc), pcbnew.B_Cu: obstacles(board, pcbnew.B_Cu, nc)}
        if connect_to_same_net(board, pad, cache, axis, w, True):
            done += 1
        else:
            left.append(f"{fp.GetReference()}.{pad.GetNumber()}")
    pcbnew.SaveBoard(path, board)
    print(f"fanned out {done} pads; no room for: {left or 'none'}")


if __name__ == "__main__":
    main(sys.argv[1])

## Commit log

2026-09-29 Spec v0.2 after the specialist review
    Four reviews (Amiga bus, power/EMC, ESP32-S3, PCB/JLC) in
    docs/reviews/2026-09-29-spec-review.md, with every finding and its decision.
    - Power: eFuse with 5.7 V clamp instead of the P-FET (which back-fed the A500
    from USB), Schottky OR, TLV62569 buck, AMIGA_PWR sense.
    - Outputs on GPIO21/38-42: GPIO1-18 are driven low at power-up.
    - Pull-ups on the Amiga side of the OR, connector side of the 100 ohm;
    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
2026-09-29 Implementation plan for the v1 hardware
    Schematic generated from hardware/design.py, netlist tests per spec, ERC,
    layout by script from the netlist, DRC, two review rounds, JLC files.
    Spec: USB-C part C393939 (the Nano-Tek footprint), as the plan uses.
2026-09-29 Schematic generator: design data to KiCad 10 schematic
2026-09-29 Project libraries: TPS259531, USB-C and power header; deterministic schematic UUIDs
    [171826-4.stp]
2026-09-29 Design: floppy connector, input and output buffers
2026-09-29 Design: power path with eFuse, diode OR and buck
2026-09-29 Design: ESP32-S3 module, USB-C, headers, LED, test pads
2026-09-29 Schematic: generated from the design, ERC clean, PDF
    ERC: 0 errors; 14 footprint_filter warnings (74HC14 symbol filters DIP,
    footprint is SOIC-14). 44 netlist tests pass.
    [FluxDrive.kicad_sch]
2026-09-29 Schematic review: fix VBUS back-feed and stale-netlist tests, take in the minors
    Four reviews of the generated schematic (bus, power, ESP32-S3, PCB and code),
    recorded in docs/reviews/2026-09-29-schematic-review.md.
    - U7 (USBLC6) supply pin on +3V3 instead of VBUS, 10k bleeder on VBUS (SPWR-1)
    - tests read a netlist exported fresh from the committed schematic and fail
    when it is not what hardware/design.py generates (SCODE-1)
    - AMIGA_PWR divider 1k/1k5: low on USB alone (SESP-1, SPWR-4)
    - +5V_A bulk 2 x 47uF 10V instead of 100uF 6.3V (SPCB-2)
    - J2 vertical TE 171825-4 (C210162) with its own footprint (SPCB-1)
    - unfitted pads: V5SYS damper, SMAJ13A on +5V_IN, 15pF feed-forward, all 0603
    -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
    [171826-4.stp, FluxDrive.kicad_sch]
2026-09-29 Board: footprints from the netlist, outline and placement
    - tools/pcb_sync.py (from the Nano-Tek tool, without its Rev 1.2 migration) builds
    FluxDrive.kicad_pcb from the netlist; tools/pcb_place.py sets the 60 x 48 mm outline,
    the GND pours and every position, moving non-fixed parts to the nearest free spot
    - module footprint copy with 0.3 mm thermal vias; netclass patterns with the / prefix,
    Power tracks 0.3 mm (the eFuse pads are 0.25 mm at 0.5 mm pitch)
    - tests/test_pcb.py: outline, J1 on the south edge, antenna past the north edge,
    J2 beside J1
    [FluxDrive.kicad_pcb, FluxDrive.kicad_sch]
2026-09-29 Board: routed, DRC clean
    - tools/pcb_build.sh builds the board in build/pcb (OUT= to choose): netlist, sync, placement,
    hand-made USB-C VBUS bridge, GND fan-out, Freerouting x6 in parallel with the best kept,
    finishing (maze, Freerouting --continue), loose ends, ground stitching, silkscreen, DRC
    - routing tools from the Nano-Tek, for 2 layers: GND stays plane (no pins in the DSN),
    B.Cu four times as dear as F.Cu, track keep-out on B.Cu between the J1 pin rows
    - placement: buffers higher, row B at 1.3 mm pitch, room for the rails between the rows,
    spare header east of U4, connector test pads south of J1
    - DRC: 0 errors, 0 unconnected, 0 parity issues; buck 32 mm from /DKRD, 21 mm from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
    [FluxDrive.kicad_pcb]
2026-09-29 Board: silkscreen, marks and fit template
    - tools/pcb_silk.py: pin 1 of J1 on both sides, name and credit, header pin names, serial box,
    JLC order-number spot and the plug-on socket note on the bottom, BOOT/RESET labels, tidy
    reference texts (passives hidden, 0 silk overlaps); a 50 mm scale bar on Dwgs.User
    - tools/fit_template.sh -> mech/fit_template.pdf: 1:1 outline, courtyards, silkscreen and fab
    drawing, to print at 100 % and try in the A500
    [pcb_silk.py]
2026-09-30 Layout review and fixes: 4 layers, antenna on the board
    Four specialist reviews of the task-10 layout (55 findings, 13 major); the
    record with every decision is docs/reviews/2026-09-29-layout-review.md.
    - 4 layers (Dimitri): In1 solid GND, In2 solid +3V3; every GND/+3V3 pad
    has its own via, outer pours stitched to In1.
    - The board grows 6.5 mm north; the module's antenna lies 0.5 mm inside
    the edge over copper-free board (Dimitri; O10 closed). Spec v0.4.
    - Buffer gates re-assigned in connector order (U3 pins 4-16, U2 18-32);
    row B follows the buffer inputs; schematic and PDF regenerated.
    - Rule areas: J1 rows, antenna edge, buck, module underside, USB-C body.
    - Hand routes before Free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
    [FluxDrive.kicad_pcb, FluxDrive.kicad_sch, FluxDrive.step]
2026-09-30 Production files, render and README
    - tools/jlc_export.py and tools/jlc_production.sh from the Nano-Tek,
    for 4 layers: gerber and drill zip, BOM (29 lines, 87 parts) and CPL;
    through-hole, unfitted, test pads and fiducials left out.
    - Renders of the top, bottom and a 3D view in docs/images/.
    - README "Building one": checks before ordering, JLCPCB settings, the
    parts to check in the placement preview, hand-soldered parts, the
    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
    [BOM-FluxDrive.csv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]
2026-09-30 Fit-test answers, O7 narrowed, and the build rulings on record
    - Dimitri's fit test: the room under the shield is enough and the power
    cable reaches J2 from CN12; O7 keeps only the plug-on mounting and the
    printed dummy.
    - Spec 11.2: DRC with JLC's 4-layer rules.
    - docs/reviews/2026-09-30-build-rulings.md: every ruling made while
    carrying out the plan (61) and the deferred minor findings (9).
2026-09-30 ESP32 module placed by hand: no paste, out of JLC's BOM and CPL
    Dimitri places U1 (ESP32-S3-WROOM-1-N16R8) himself. JLC prints paste on
    every stencil opening, also on parts it does not place, and the reflowed
    bumps (the ground pad's the worst) would keep the module from sitting flat.
    - tools/assembly.py: HAND_PLACED = ("U1",).
    - pcb_sync.py takes the paste off hand-placed parts as off unfitted ones;
    applied to the board: only U1's 49 paste openings change (40 pads, 9
    windowpane openings). DRC: 0 errors, 0 unconnected, 0 parity.
    - jlc_export.py leaves hand-placed parts out: BOM 28 lines / 86 parts.
    - Tests: test_hand_placed_parts_have_no_paste; the production test skips
    hand-placed par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
    [BOM-FluxDrive.csv, FluxDrive.kicad_pcb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]
